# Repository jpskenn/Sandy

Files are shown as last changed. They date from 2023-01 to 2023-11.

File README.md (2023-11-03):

# Sandy（サンディ）

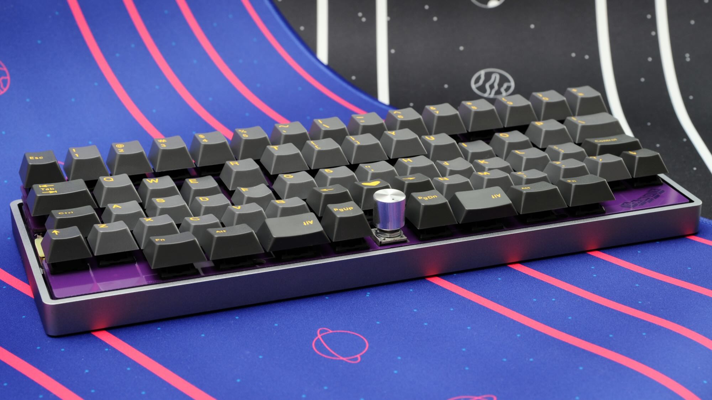
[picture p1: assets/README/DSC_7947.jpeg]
Sandy keyboard
  

Sandy is a keyboard with key height optimization.

Layered PCB will make height differences for each key.
This covers the lack of optimization to physical key layout that only adjust x-y direction in a plane.

---

Sandyは、スイッチの配置を立体的にして高さ方向への最適化を加えた、左右対称レイアウトの60%キーボードです。  

平面上のキーレイアウトだけでは最適化しきれない部分を、キーの位置に応じてスイッチを配置する高さを変えることで補っています。

名前の由来は、立体的、つまり3Dという意味を込めて…

``` text
3D → スリーディー → さんディー → サンディ → Sandy
```

という言葉遊びで、Sandy（サンディ）に決まりました。

---

## お知らせ

2023-11-04

キー割り当て書き換えツール[Remap](https://remap-keys.app)がQMKファームウェアのバージョン 0.22.2以降に対応したことに伴い、新しくビルドしたSandyのファームウェアを公開しました。  
参考：[Remap supports QMK Firmware 0.22.2 or higher](https://remap-keys.app/docs/support-qmk-022)

今すぐファームウェアを更新する必要はありませんが、ロータリーエンコーダへのキー割り当てを変更したい場合は、ファームウェアを更新するとよいでしょう。

Remapによる旧バージョンのサポート終了後は、ファームウェアを更新してください。

詳しくは、ビルドガイドの「Sandy関連ファイル」等をご覧ください。

## 特徴

- 左右対称のキーレイアウト  
  [Jones](https://github.com/jpskenn/Jones)と同様の、2行目と3行目にずれのない、左右対称な、シンメトリカル ロースタッガードのレイアウトです。
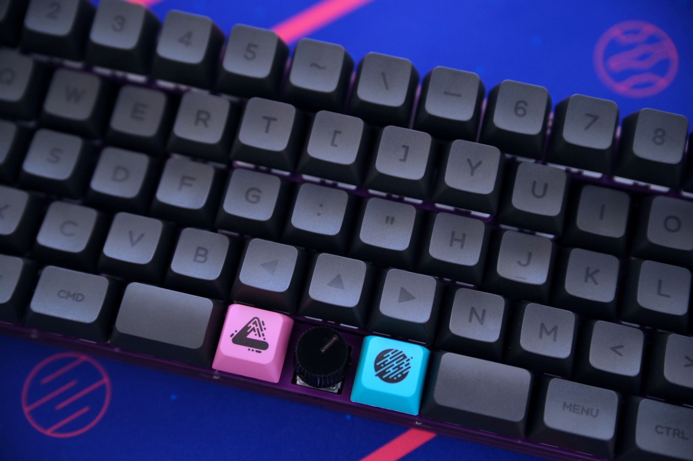
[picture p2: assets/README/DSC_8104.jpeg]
左右対称のキーレイアウト
  

- キースイッチを立体的に配置  
  3段階の高さで、キースイッチを立体的に配置しています。
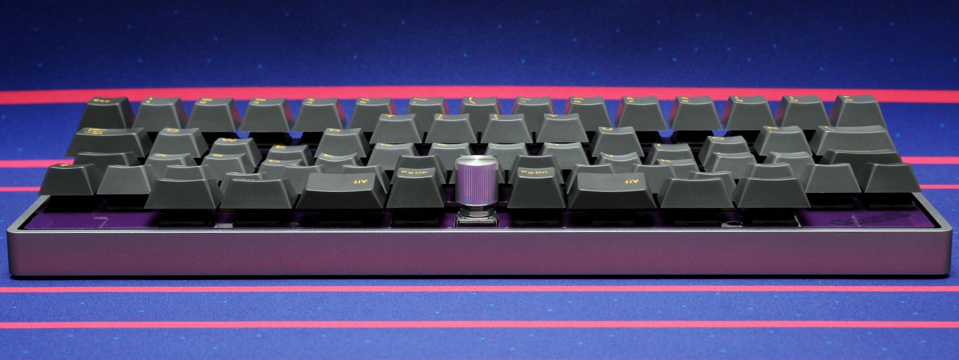
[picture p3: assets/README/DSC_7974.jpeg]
キースイッチの高さ
  

  平面上のキー配置だけでは最適化しきれない部分を、キーの位置に応じて高さを変え、立体的に配置することで補っています。  
  Jonesに比べて、ホームポジションから遠いキーへの打鍵しやすさが向上しています。

- 60%ケースと組み合わせられる  
  GH60型ケース互換のネジ穴を用意してあるので、市販のケースと組み合わせて使用できます。  
  ※詳しくはビルドガイドを参照

- [Remap](https://remap-keys.app)や[VIA](https://www.caniusevia.com)によるキー割り当て変更  
  プログラミング等の知識がなくても、ブラウザ上で簡単にキー割り当てを変更することができます。

- 外部EEPROM搭載  
  Remapでたくさんのレイヤーを使用できます。

- オプション機能  
  以下のオプション機能を使用できます。

  - ロータリーエンコーダ
  - インジケータLED
  - アンダーグローLED

## レイアウト

### バリエーション

キーのバリエーションを含むレイアウトは以下の通りです。  
Ctrl（左）とEnter（右）にはキーサイズのバリエーションがあり、最下行の中央にはロータリーエンコーダを配置できます。
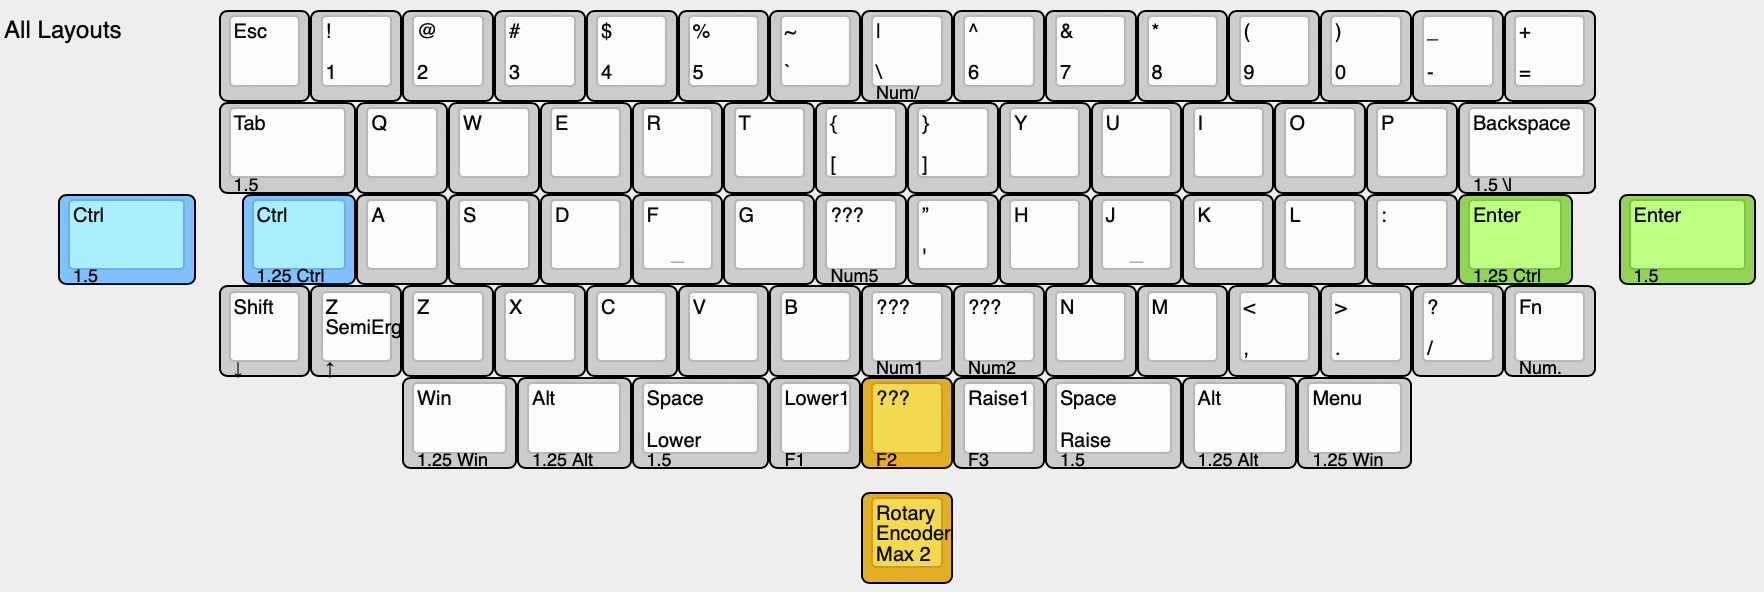
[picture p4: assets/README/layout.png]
Keyboard Layout Editor: Sandy (DN0030)
[  
Keyboard Layout Editor: Sandy (DN0030)](http://www.keyboard-layout-editor.com/#/gists/c907e866d8f82b82a22b455e622b7301)

### キーの高さ

キーの高さはLow（0mm）, Middle（3.6mm）, High（8.6mm）の3段階で、以下のように配置されます。  
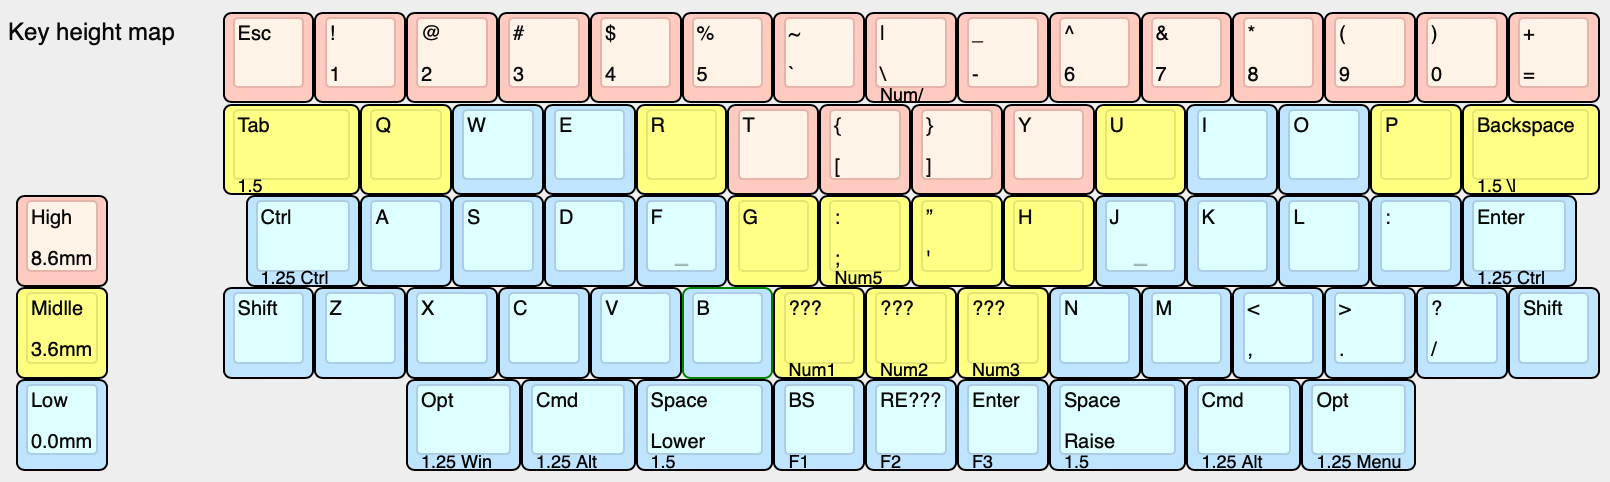
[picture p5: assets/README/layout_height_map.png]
キーの高さ


### 推奨キーマッピング

このレイアウトは、左右の手の運指を同じにするため、[SemiErgo Layout](https://github.com/mtei/SemiErgo_Layout)に準ずるキーマッピングで使用することを念頭に設計されています。  
つまり、一般的なロースタッガードレイアウトから、アルファ部の左手側Z行を左へ1キー、数字行の右手側を右側へ1キーずらしたものが、推奨キーマッピングとなります。

以下にSemiErgoを適用した推奨キーマッピングの例を示します。  
枠で囲った部分が、一般的なロースタッガードからの変更箇所です。
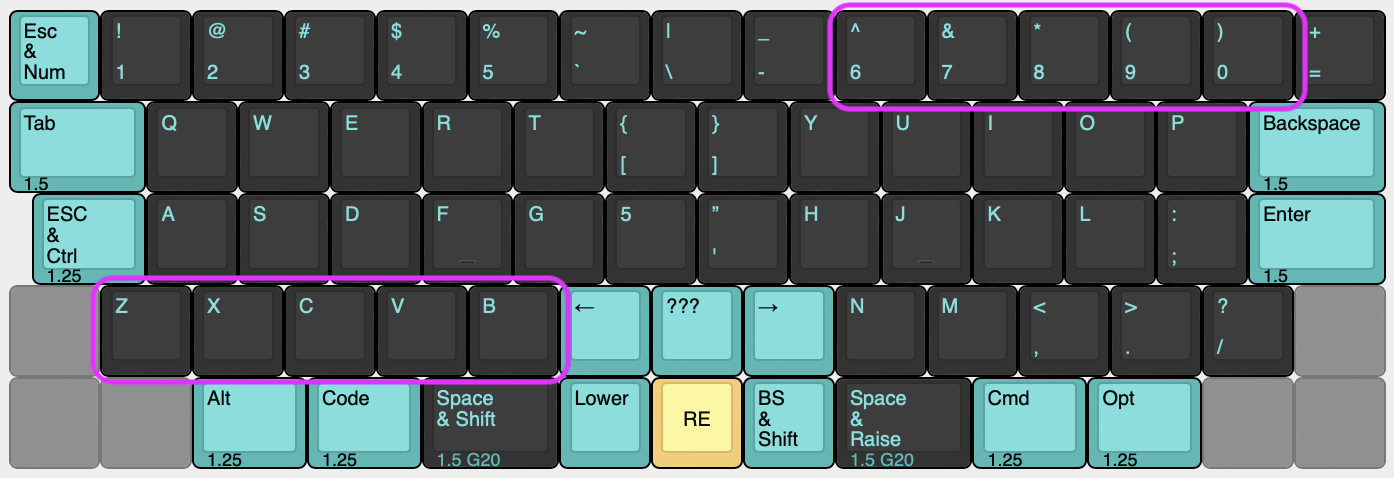
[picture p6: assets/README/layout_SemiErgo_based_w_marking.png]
SemiErgoを適用した推奨キーマッピング例

<small>💡ヒント：このキーマッピング例ではスペースキーをSandS（Space & Shift）にしているので、左右端のシフトキーを取り除いています。</small>

## ビルドガイド

- 最新版
  - [Sandy（DN0030）](/docs/BuildGuide_DN0030.md)

- 試作版
  - [Sandy（DN0020）](/docs/BuildGuide_DN0020.md)
  - [Sandy v.0.1](/docs/BuildGuide_v0_1.md)

## SNSタグ

[#Sandy_kbd](https://twitter.com/search?q=%23Sandy_kbd)

## ギャラリー

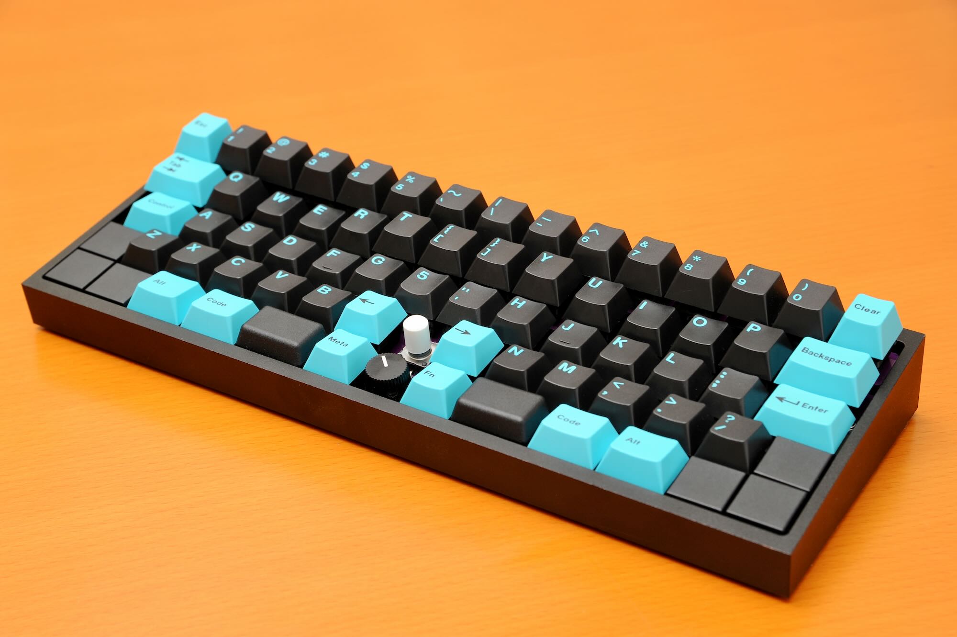
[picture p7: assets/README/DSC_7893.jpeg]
Sandy keyboard, v.0.1
  
v.0.1, Cherryプロファイルキーキャップ使用  

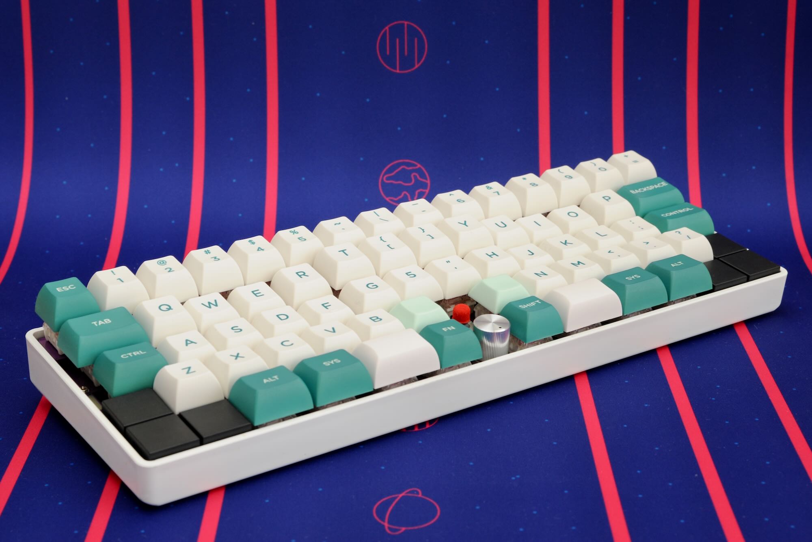
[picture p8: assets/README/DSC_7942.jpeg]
Sandy keyboard, 試作2号機
  
v.0.1, KATプロファイルキーキャップ使用

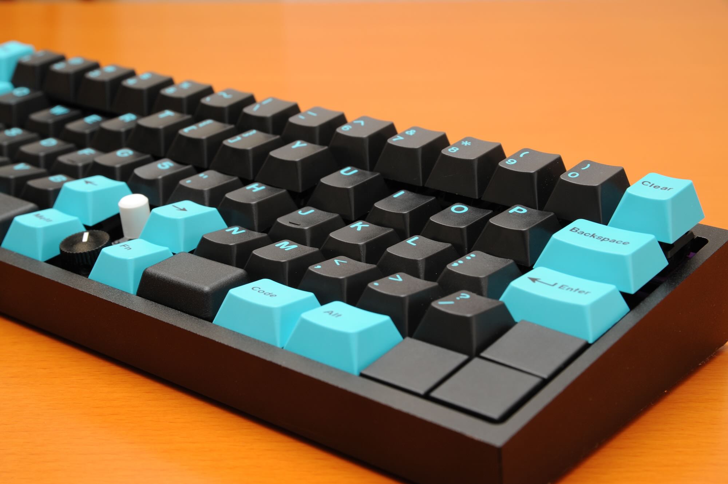
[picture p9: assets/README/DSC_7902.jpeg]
Sandy keyboard, キーの段差（Cherryプロファイル）
  
キーの段差（Cherryプロファイル）

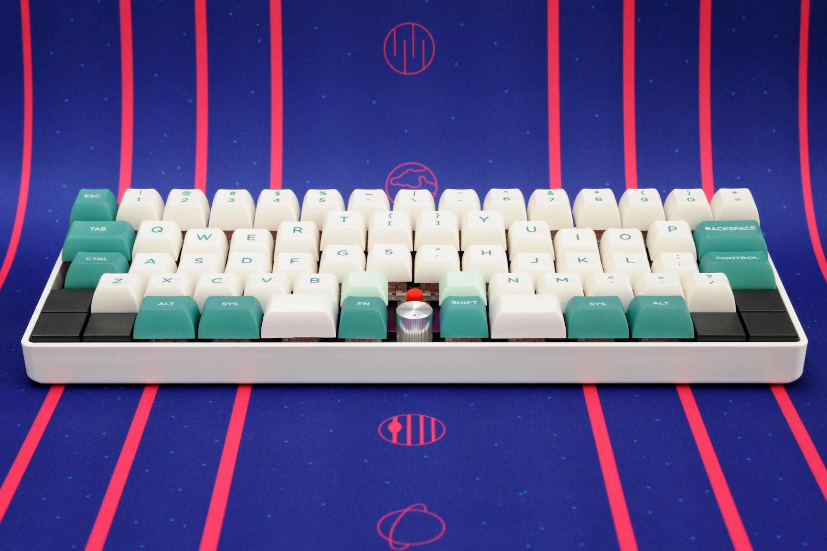
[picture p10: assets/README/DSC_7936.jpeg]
Sandy keyboard, キーの段差（KATプロファイル）
  
キーの段差（KATプロファイル）

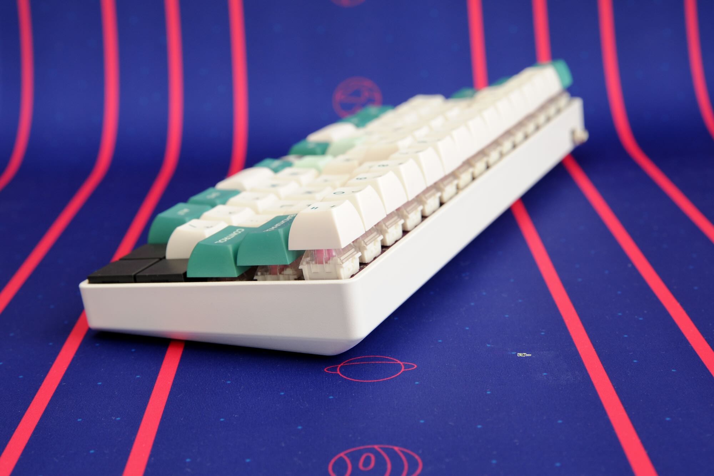
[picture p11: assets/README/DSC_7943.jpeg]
Sandy keyboard, キーの段差（横と後ろ
  
キーの段差（横）

## 残る課題

Sandyは複数基板を重ねるという手法で製作しているため、その技術的な制限や、製作工程を複雑にしすぎない配慮により、全てのスイッチをなめらかな高さ変化で配置できていません。  
そのため、高さ方向へ最適化しきれていない部分が残っています。  

## 参考事例

- [Genesis2.5](https://github.com/sekigon-gonnoc/Genesis2.5-doc)（[販売ページ](https://booth.pm/ja/items/1308005)  
  行ごとに高さと傾きを変えることができる自作キーボードキット。  

- [Thumbs Up!](https://www.thumbsup.shop)  
  カラムスタガをベースに親指や中央のキーを高くした設計の自作キーボードキット。

- [Kinesis Advantage series](https://kinesis-ergo.com/products/#keyboards)  
  ”エルゴノミクス”、”3Dキーボード”と言えばこれが思い浮かぶのはこれ。凹形状にキーが配置されている。

- [Microsoft Sculpt](https://www.microsoft.com/en/accessories/products/keyboards/sculpt-ergonomic-desktop)  
  ほんのり放射状に並んだキーと、中央部が高くなった形状。

- [Dactyl](https://github.com/adereth/dactyl-keyboard)  
  3Dプリンタで作る、スイッチを3D配置したキーボード。

- ["3D" キーキャップ](https://qiita.com/zk_phi/items/5680607118516413a0ba)  
  キーボードはそのままに、キーごとに高さを変えた3D形状のキーキャップ。MXスイッチ用。

- [Gravity Keycaps](https://note.com/yfuku_/n/n1fbba2e8f44c)  
  Choc用の3D形状キーキャップ。

## 開発経緯

### 元々の計画

当初（2021年1月ごろ）は、Chocスイッチを使用するキーボード、[Nora](https://github.com/jpskenn/Nora)の打鍵しやすさ向上を目的に、スイッチの配置を立体的に改修する計画でした。  
Choc用キーキャップには、行ごとに高さの異なるプロファイルのものが存在しません。すべてのキーが同じ形状になっているため、1行目の数字行や、ホームポジションから遠いキーへ指が届きにくくなります。  
その状況を改善するための改修計画でしたが、あまりモチベーションも上がらず、手をつけずに放置していました。  

### Sandy計画の始動

2022年12月の末ごろ、[SMKJのアドベントカレンダー](https://scrapbox.io/self-made-kbds-ja/アドベントカレンダー)を久しぶりに読み返しながら、様々なアイデアや取り組みについて思いをめぐらせていました。
そのとき、ふとした思いつきでJonesのキーキャップを部分的に背の高いものに入れ替えたところ、思いのほか打鍵しやすくなることに気がつきました。  

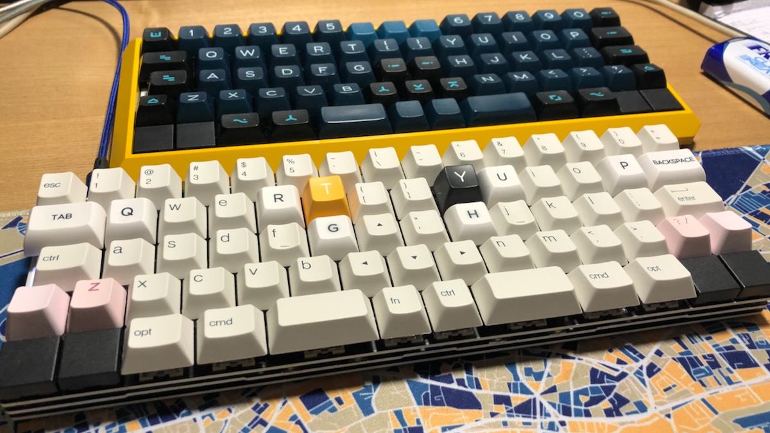
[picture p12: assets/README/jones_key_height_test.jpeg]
Jonesのキーキャップを部分的に背の高いものに入れ替えたテスト機
  
奥：通常のJones，手前：一部のキーを入れ替えたJones

Cherryプロファイルをベースにして、`T` `Y`は倍ほどの高さのSAプロファイル、`G`や`Q`などは少しだけ背の高いKATプロファイルに交換しました。  
この時点では`左右のシフト`などをOEMプロファイルでほんの少し高くしようとしていますが、後にボツとなります。

これをきっかけとして、MXスイッチを使用するキーボード、[Jones](https://github.com/jpskenn/Jones)を改修する計画として復活することになりました。  

### ロードテスト

先ほどのテスト機を使い部分的にキーキャップを交換してどのキーを最適化の対象にするかを調べたり、スチレンボードにスイッチをのせたモックアップを作成して最適な高さを探ったりしました。（`0+2+2`は、ベースの0mmに対して、1段目が2mm、2段目も2mmの段差を意味するメモ）

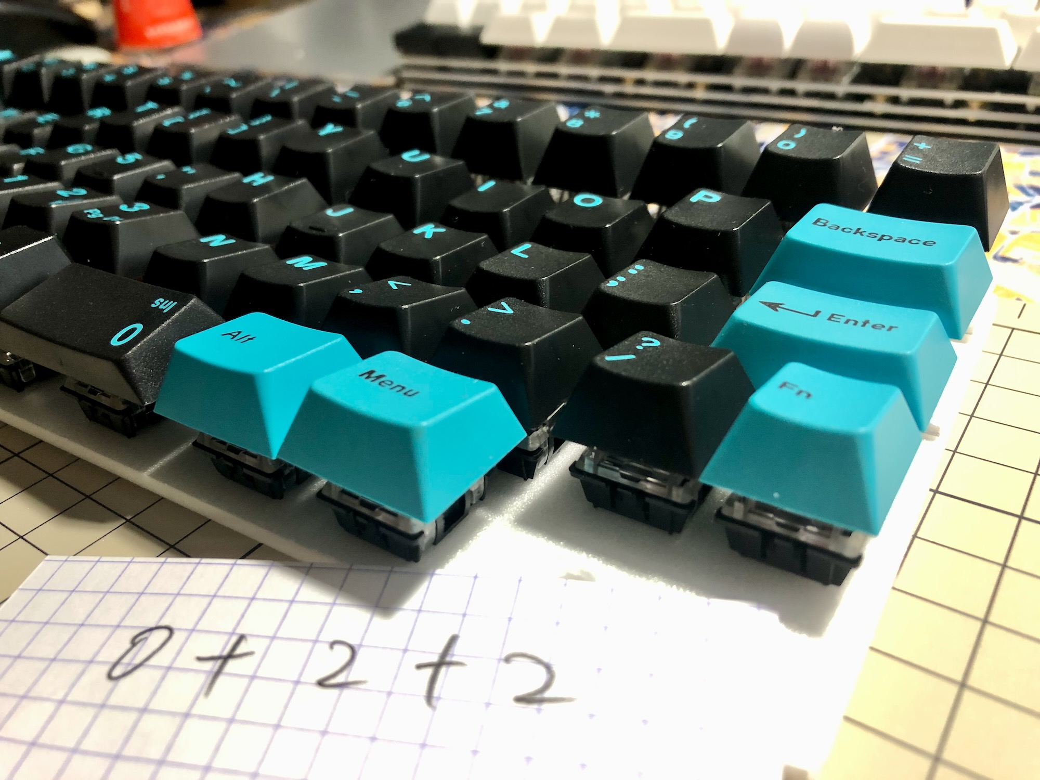
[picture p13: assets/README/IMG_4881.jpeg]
モックアップ
  

テスト機は、数字行をSAプロファイルへ、また、`T` `Y`をSAプロファイル1行目のキーに交換してさらに高くした最終形態になりました。  

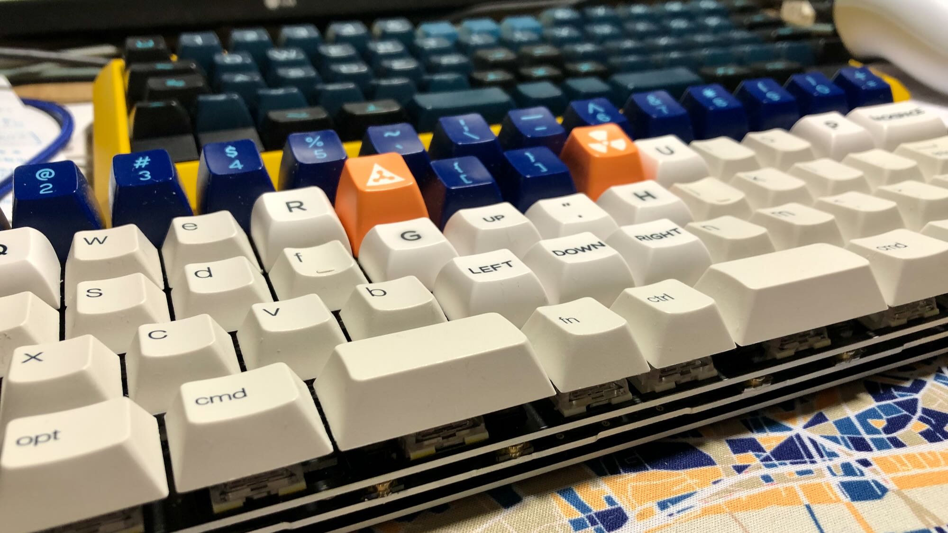
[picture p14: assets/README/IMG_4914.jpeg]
最終形のテスト機


この形態をロードテストとして3ヶ月ほど使用し、日常的な使用で問題ないことを確認した上で基板の製作に取り掛かりました。

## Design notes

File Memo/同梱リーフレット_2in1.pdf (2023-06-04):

このたびは、自作キーボードキット Sandy（サンディ）をご購入いただ

き、まことにありがとうございます。

まずは、すみやかにキット内容をご確認ください。

万一不足等がありましたら、下記の連絡先へお問い合わせください。

キット内容・組み立て方法
URL または QR コードから Sandy のプロジェクトペー

ジへアクセスし、ビルドガイドをごらんください。

https://github.com/jpskenn/Sandy

別途用意が必要な部品
- はんだ付け関連用品，ドライバーなど
- Cherry MX（互換）スイッチ 66 ～ 最大 67 個
- キーキャップ（MX 用） 同上
- USB ケーブル（Type-C） 1 本

連絡先
Twitter: @jpskenn

mail: kkeennnn+sandy@gmail.com

組み立てに関する質問なども、こちらでお受けいたします。

このたびは、自作キーボードキット Sandy（サンディ）をご購入いただ

き、まことにありがとうございます。

まずは、すみやかにキット内容をご確認ください。

万一不足等がありましたら、下記の連絡先へお問い合わせください。

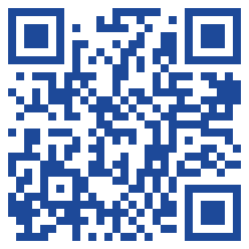
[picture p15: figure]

キット内容・組み立て方法
URL または QR コードから Sandy のプロジェクトペー

ジへアクセスし、ビルドガイドをごらんください。

https://github.com/jpskenn/Sandy

別途用意が必要な部品
- はんだ付け関連用品，ドライバーなど
- Cherry MX（互換）スイッチ 66 ～ 最大 67 個
- キーキャップ（MX 用） 同上
- USB ケーブル（Type-C） 1 本

連絡先
Twitter: @jpskenn

mail: kkeennnn+sandy@gmail.com

組み立てに関する質問なども、こちらでお受けいたします。

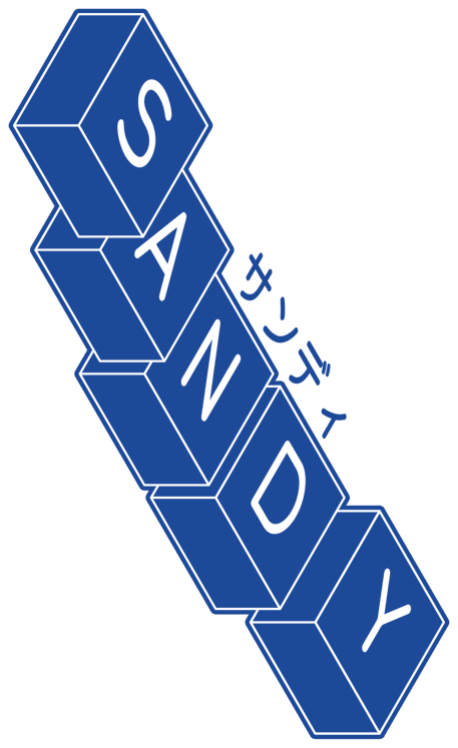
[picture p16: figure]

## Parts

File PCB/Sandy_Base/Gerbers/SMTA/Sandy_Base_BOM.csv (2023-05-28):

Comment | Designator | Footprint | LCSC
10uF | C1 | Capacitor_SMD:C_0805_2012Metric | C15850
22pF | C2,C3 | Capacitor_SMD:C_0805_2012Metric | C1804
0.1uF | C4,C5,C7,C8,C9 | Capacitor_SMD:C_0805_2012Metric | C49678
1uF | C6 | Capacitor_SMD:C_0805_2012Metric | C28323
D | D1,D2,D3,D4,D5,D6,D7,D8,D9,D10,D11,D12,D13,D14,D15,D16,D17,D18,D19,D20,D21,D22,D23,D24,D25,D26,D27,D28,D29,D30,D31,D32,D33,D34,D35,D36,D37,D38,D39 | locallib:D_SOD-123_Emphasized_Direction_Line_Reference_on_bottom | C81598
PRTR5V0U2X | D99 | Package_TO_SOT_SMD:SOT-143_Handsoldering | C78442
Conn_01x01 | EXT_C0,EXT_R0,EXT_C1,EXT_R1,EXT_C2,EXT_R2,EXT_C3,EXT_R3,EXT_C4,EXT_R4,EXT_C5,EXT_R5,EXT_C6,EXT_R6,EXT_C7,EXT_R7,EXT_R8,EXT_R9 | TestPoint:TestPoint_THTPad_D2.0mm_Drill1.0mm
500mA | F1 | Fuse:Fuse_1206_3216Metric_Pad1.42x1.75mm_HandSolder | C70076
MountingHole | H1,H2,H3,H4 | locallib:MountingHole_2.2mm_M2_No_Cu
MountingHole | H6,H7,H8,H9,H10,H11,H12,H13,H14,H40,H41 | locallib:MountingHole_2.2mm_M2_Pad_minimal
Conn_02x02_Top_Bottom | J1,J2,J3,J4,J5,J6 | locallib:JST_SH_SM04B-SRSS-TB_1x04-1MP_P1.00mm_Horizontal_wCable_housing_spare_pin | C371510
Conn_01x03 | J10 | Connector_PinHeader_2.54mm:PinHeader_1x03_P2.54mm_Vertical
USB_C_Receptacle_USB2.0 | J7 | Connector_USB:USB_C_Receptacle_HRO_TYPE-C-31-M-12 | C165948
Conn_02x03_Odd_Even | J8 | Connector_PinHeader_2.54mm:PinHeader_2x03_P2.54mm_Vertical
Conn_01x02 | J9 | Connector_PinHeader_2.54mm:PinHeader_1x02_P2.54mm_Vertical
SolderJumper_3_Open | JP1 | Jumper:SolderJumper-3_P1.3mm_Open_RoundedPad1.0x1.5mm
SK6812MINI-E | L1,L2,L3,L4,L5,L6,L7,L8,L9,L10,L11,L12,L13,L14,L15,L16,L17,L18 | locallib:YS-SK6812MINI-E_middle_hole_with_small_pad
Logo_Base | LOGO1 | Jones.local:Sandy_logo_w60_new
5.1k | R1,R2 | Resistor_SMD:R_0805_2012Metric | C27834
22 | R3,R4 | Resistor_SMD:R_0805_2012Metric | C17561
10k | R5,R6 | Resistor_SMD:R_0805_2012Metric | C17414
4.7k | R8,R9 | Resistor_SMD:R_0805_2012Metric | C17673
RotaryEncoder_Switch | RE_L1,RE_R1,RE_L2 | locallib:RotaryEncoder_Alps_EC11K-Switch_Vertical_H20mm_NPTH_MP_minimal
5.2x5.2mm | ResetSW1 | Button_Switch_SMD:SW_SPST_TL3342
SW_Push | SW_;1,SW_<1,SW_>1,SW_A1,SW_C1,SW_D1,SW_DOWN1,SW_E1,SW_F1,SW_I1,SW_J1,SW_K1,SW_L1,SW_M1,SW_N1,SW_O1,SW_S1,SW_UP1,SW_V1,SW_W1,SW_X1,SW_Z1,SW_Fn1u1,SW_LSFT1u1,SW_CenterL1u2,SW_CenterR1u2,SW_LSFT1u2,SW_L2-1u1 | MX_Alps_Hybrid:MXOnly-1U-Hotswap-guide
SW_Push | SW_RIGHT1,SW_CAPS1u1,SW_CenterC1u1 | MX_Alps_Hybrid:MXOnly-1U-Hotswap-on-RE-guide
SW_Push | SW_CTL1.25u1,SW_ENT1.25u1,SW_LALT1.25u1,SW_LWIN1.25u1,SW_RALT1.25u1,SW_ROPT1.25u1 | MX_Alps_Hybrid:MXOnly-1.25U-Hotswap-guide
SW_Push | SW_CTL1.5u1,SW_ENT1.5u1,SW_LSPC1.5u1,SW_RSPC1.5u1 | MX_Alps_Hybrid:MXOnly-1.5U-Hotswap-guide
ATmega32U4-MU | U1 | Package_DFN_QFN:QFN-44-1EP_7x7mm_P0.5mm_EP5.2x5.2mm | C112161
24LC64 | U2 | Package_SO:SO-8_3.9x4.9mm_P1.27mm | C79988
16MHz | Y1 | Crystal:Crystal_SMD_3225-4Pin_3.2x2.5mm_HandSoldering | C13738

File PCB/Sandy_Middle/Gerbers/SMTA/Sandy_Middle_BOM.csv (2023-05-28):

Comment | Designator | Footprint | LCSC
D | D1,D2,D3,D4,D5,D6,D7,D8,D9,D10,D11,D12,D13 | locallib:D_SOD-123_Emphasized_Direction_Line | C81598
Conn_01x01 | EXT_MC0,EXT_MR1,EXT_MC2,EXT_MR2,EXT_MC3,EXT_MR3,EXT_MC4,EXT_MC6,EXT_MR6,EXT_MC7,EXT_MR7,EXT_MR8 | TestPoint:TestPoint_THTPad_D2.0mm_Drill1.0mm
MountingHole | H1,H2,H3,H4,H5,H6,H7,H8,H9,H10,H11,H12,H13,H14,H15,H16,H17,H18,H19 | locallib:MountingHole_2.2mm_M2_Pad_minimal
Conn_02x02_Top_Bottom | J1,J2,J3 | locallib:JST_SH_SM04B-SRSS-TB_1x04-1MP_P1.00mm_Horizontal_wCable_housing_spare_pin | C160404
SW_Push | SW_'1,SW_;1,SW_G1,SW_H1,SW_P1,SW_Q1,SW_R1,SW_U1,SW_R4CenterC1,SW_R4CenterL1,SW_R4CenterR1 | MX_Alps_Hybrid:MXOnly-1U-Hotswap-guide
SW_Push | SW_BS1.5u1,SW_TAB1.5u1 | MX_Alps_Hybrid:MXOnly-1.5U-Hotswap-guide

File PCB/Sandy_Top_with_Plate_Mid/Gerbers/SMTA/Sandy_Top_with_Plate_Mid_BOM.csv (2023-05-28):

Comment | Designator | Footprint | LCSC
D | D1,D2,D3,D4,D5,D6,D7,D8,D9,D10,D11,D12,D13,D14,D15,D16,D17,D18,D19 | locallib:D_SOD-123_Emphasized_Direction_Line | C81598
Conn_01x01 | EXT_TC0,EXT_TR0,EXT_TC1,EXT_TR1,EXT_TC2,EXT_TC3,EXT_TC4,EXT_TC5,EXT_TR5,EXT_TC6,EXT_TR6,EXT_TC7 | TestPoint:TestPoint_THTPad_D2.0mm_Drill1.0mm
MountingHole | H1,H2,H3,H4,H5,H6,H7,H8 | locallib:MountingHole_2.2mm_M2_Pad_minimal
Conn_02x02_Top_Bottom | J1,J2,J3 | locallib:JST_SH_SM04B-SRSS-TB_1x04-1MP_P1.00mm_Horizontal_wCable_housing_spare_pin | C371510
SW_Push | SW_-1,SW_1,SW_=1,SW_ESC1,SW_T1,SW_Y1,SW_[1,SW_\1,SW_]1,SW_`1,SW_2,SW_3,SW_4,SW_7,SW_9,SW_10 | MX_Alps_Hybrid:MXOnly-1U-Hotswap-guide
SW_Push | SW_5 | MX_Alps_Hybrid:MXOnly-1U-Hotswap-screw-hole-side2-guide
SW_Push | SW_6 | MX_Alps_Hybrid:MXOnly-1U-Hotswap-screw-hole-side1-guide
SW_Push | SW_8 | MX_Alps_Hybrid:MXOnly-1U-Hotswap-screw-hole-side3-guide

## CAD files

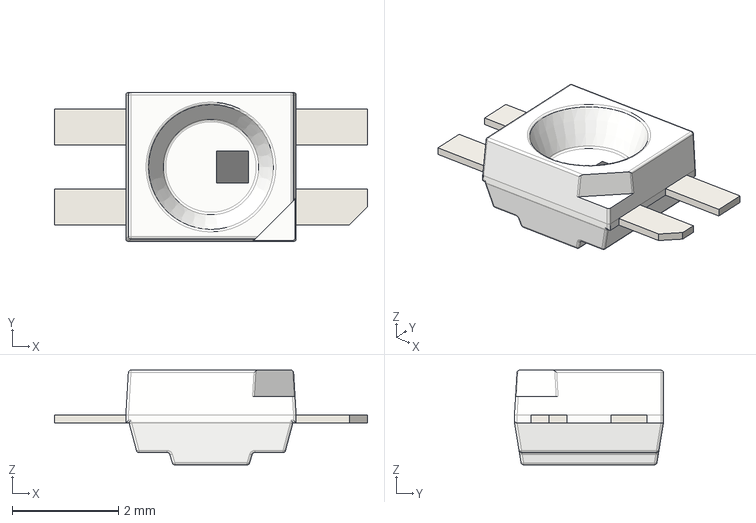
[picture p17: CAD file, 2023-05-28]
PCB/Sandy_Base/lib_LED/LED_SK6812MINI-E.step
5.88 x 2.80 x 1.78 mm

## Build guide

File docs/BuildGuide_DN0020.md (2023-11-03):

# Sandy（DN0020）ビルドガイド

このドキュメントは、Sandy（DN0020）を組み立てるためのビルドガイドです。  
Sandyのコンセプトや特徴、ビルド例などについては、こちらの[README](/README.md)をご覧ください。

ビルドガイド全体に目を通して作業手順を把握しておくとミスの防止につながりますので、ぜひ、一度お読みになってから組み立て作業を始めてください。

作業手順をしっかりと確認しながら組み立てたい方は、

<details>
<summary>《《《 詳しい説明 》》》</summary>

ここに追加の説明を表示します。
</details>

と書かれたところをクリックすると、追加の説明が表示されます。

---

## 目次

<!-- @import "[TOC]" {cmd="toc" depthFrom=2 depthTo=2 orderedList=false} -->

<!-- code_chunk_output -->

- [目次](#目次)
- [注意事項](#注意事項)
- [部品リスト](#部品リスト)
- [組み立てに使用する工具](#組み立てに使用する工具)
- [組み立て手順](#組み立て手順)
- [参考資料](#参考資料)
- [サービスマニュアル](#サービスマニュアル)

<!-- /code_chunk_output -->

---

## 注意事項

- 試作版

  Sandy（DN0020）は試作版です。  

- 組み立て難易度：高

  SHコネクタのはんだ付けがそこそこ難しいです。  
  テスターで確認しながら作業を進めると、失敗を防ぎ、手戻りなく進められるでしょう。  
  個人的な所感としては、はんだ付けを数回やった程度の方にはかなりチャレンジングな作業になると思います。  
  これを機にテスターを購入してはんだ付けの腕前を上げる気持ちで挑むか、コネクタ取り付けサービスの利用をご検討ください。

- スイッチの取り付け

  一部のスイッチを上下反対向きに取り付けます。

- ビルドガイド

  一部の写真はDN0030のものを掲載しています。  
  パーツ位置や表記が異なるだけで、基本的には同じです。

- ファームウェアについて

  出荷時に書き込み済みのファームウェアは、QMKバージョン 0.18.17です。  
  [Remap for QMK Firmware 0.18.17 or lower](https://qmk018.remap-keys.app)で、キーの割り当てを変更することができます。  
  ロータリーエンコーダへのキー割り当てをおこなうには、Remapで定義ファイル`sandy_v01_via.json`をインポートしてください。

  QMKバージョン 0.22.14のファームウェアに書き換えると、[Remap](https://remap-keys.app/)で、ロータリーエンコーダを含むキーの割り当てを変更できるようになります。

## 部品リスト

このキットを組み立てるためには、[キット内容](#キット内容)に加え、[別途用意が必要な部品](#別途用意が必要な部品)が必要です。  
好みに合わせて必要な数をお買い求めください。

[オプション部品](#オプション部品)は、使いたい機能に応じて用意してください。  

### キット内容

| 部品名 | 個数 | 備考 |
| :-- | --: | :-- |
| ご案内リーフレット | 1 | |
| 基板Base | 1 | Baseのみ部品実装済み |
| 基板Mid | 1 | |
| 基板Top | 1 | Mid用スイッチプレートを兼ねる |
| Base用スイッチプレート | 1 | 捨て基板（捨て板）付き |
| Top用スイッチプレート | 1 ||
| ボトムプレート | 1 ||
| ダイオード<br>表面実装（SMD）タイプ, 1N4148W<br>[高速スイッチング・ダイオード　１Ｎ４１４８Ｗ](https://akizukidenshi.com/catalog/g/gI-07084/) | 34 | 予備2個含む |
| SHコネクタ<br>JST SH ベース サイド型 4pin 面実装<br>[HR(Joint Tech Elec) A1001WR-S-04P](https://www.lcsc.com/product-detail/_HR-Joint-Tech-Elec-_C371510.html) | 12 | 取り付けサービス利用時は、各基板に取り付け済み |
| JST SH 4pinケーブル<br>（いわゆるQwiicケーブル）<br>[PRT-17260](https://www.digikey.jp/ja/products/detail/sparkfun-electronics/PRT-17260/13629028) | 6 | ケーブルの取り回しを考え、長さ5-10cm程度を推奨。<br>国内での販売例：<br>- [Qwiicケーブル（Qwiic -Qwiic）50 mm](https://www.switch-science.com/products/6896?_pos=1&_sid=bc641ada5&_ss=r)<br>- [SparkFun　PRT-17260 Qwiicケーブル (50mm)](https://www.sengoku.co.jp/mod/sgk_cart/detail.php?code=EEHD-5ZMM) |
| スペーサー<br>両メネジ M2 3mm<br>[ヒロスギ ARB-2003E](https://hirosugi.co.jp/products/B/ARB-E.html#bx3) | 16 | 丸型、六角いずれも使用可能 |
| 六角ナット<br>M2 2種 高さ1.6mm<br>[ウィルコ FNT-02N-2](https://wilco.jp/products/F/FNT-N-2.html) | 22 | |
| ワッシャー<br>内径2.3mm 外径4.3mm 厚さ0.4mm<br>[ウィルコ FW-0204-04N](https://wilco.jp/products/F/FW-N.html#page3) | 19 | |
| ネジ<br>M2 3mm<br>[ウィルコ F-0230N-03](https://wilco.jp/products/F/F-N-02.html#page3) | 32 | |
| ネジ<br>M2 7mm<br>[ウィルコ F-0270N-03](https://wilco.jp/products/F/F-N-02.html#page3) | 11 | |
| LED<br>SK6812MINI<br>[マイコン内蔵ＲＧＢＬＥＤ　ＳＫ６８１２ＭＩＮＩ](https://akizukidenshi.com/catalog/g/gI-15477/) | 4 | |
| スイッチ用ソケット（MX）<br>[MXスイッチ用 Kailh PCBソケット](https://talpkeyboard.net/items/5e02c5405b120c792616bcf9) | 72 | 予備1個含む |

※出荷時期によって、機能的に同等なものへ変更することがあります。

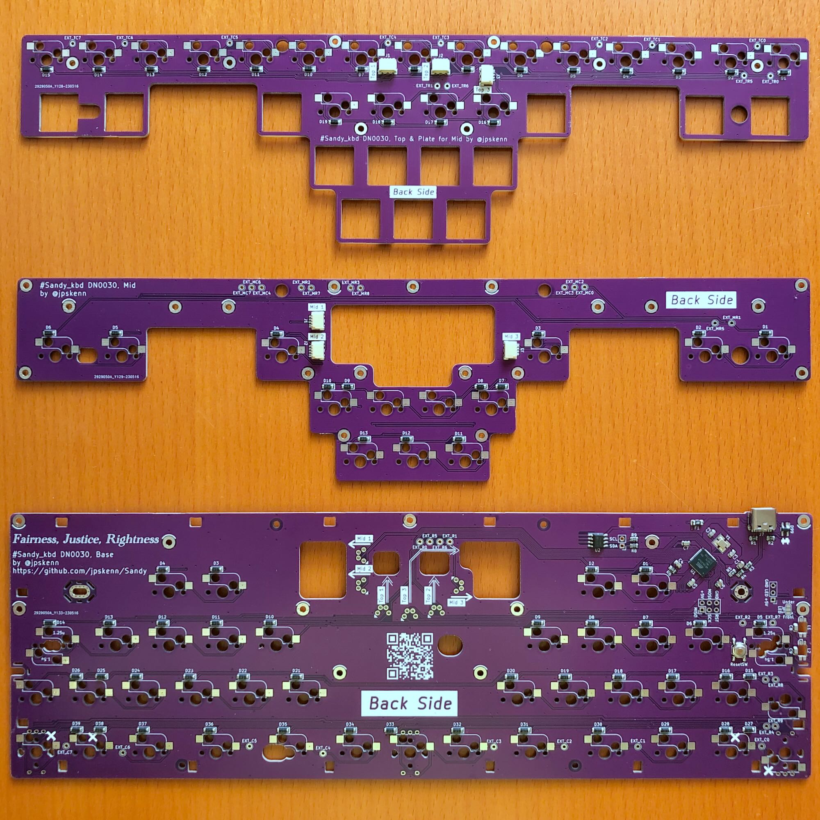
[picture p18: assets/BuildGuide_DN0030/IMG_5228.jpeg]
  
基板3枚（※写真はDN0030）  
上から順に、基板Top、基板Mid、基板Base。

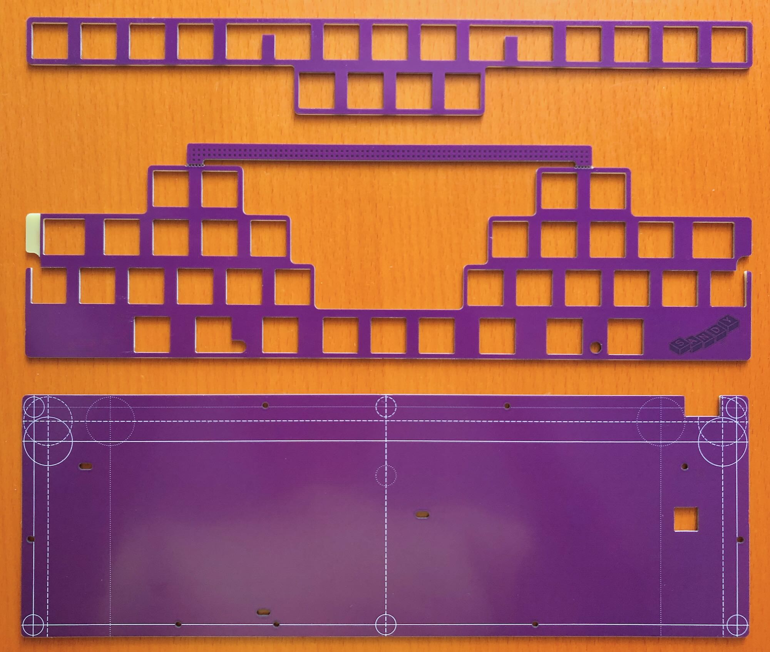
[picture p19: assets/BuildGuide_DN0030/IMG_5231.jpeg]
  
プレート類（※写真はDN0030）  
上から順に、Top用スイッチプレート、Base用スイッチプレート、ボトムプレート。

### 別途用意が必要な部品

| 部品名 | 個数 | 備考 |
| :-- | :-- | :-- |
| Cherry MX（互換）スイッチ | 69 〜 71 | 組み立てるレイアウトにより使用数が変動します。 |
| キーキャップ<br>Cherry MX（互換）スイッチ用 | 必要数 | 一般的な英語104キーキャップセットに、スペースキー用として1.5uのキー2個を追加すると全て埋めることができます。<br>1.5uのALTキーなどが含まれるセットを使用したり、文字の入っていないブランクのDSAキーキャップなどを追加すると良いでしょう。<br>参考： [Sandy（DN0020）のレイアウト](http://www.keyboard-layout-editor.com/#/gists/19f42cd466b4f3b269f38e3bdd6bf532) |
| USBケーブル （Type-C） | 1 | |

### オプション部品

| 部品名 | 個数 | 備考 |
| :-- | :-- | :-- |
| ロータリーエンコーダ<br>ALPS EC11, EC12または同等品 | 最大 2 | プッシュスイッチ付きにも対応 |
| ロータリーエンコーダ用ノブ（つまみ） | 必要数 | |
| GH60互換ケース | 1 | ケースへの基板の固定には中央と中央下のネジを使用せず、左右2本ずつ合計4本のネジだけで取り付けます。<br>ケース内部の構造によっては取り付けに加工が必要になったり、取り付けできないことがるかもしれません。<br>以下のケースへ取り付けできることを確認済みです。<br>- KBDfans TOFU 60% ALUMINUM CASE<br>- KBDfans 5° FIVE DEGREE 60% ALUMINUM CASE<br>- KBDfans 60% ALUMINUM LOW PROFILE CASE<br>- 60% プラスチックケース（簡単な加工が必要） |

## 組み立てに使用する工具

- 必要な工具

  - 先の細いプラスドライバー（+0）

    M2ネジに対応するもの。

  - はんだ付け関連用品

  - ピンセット

  - マジックペン

    基板の色に近いもの。  
    [プロッキー<細字丸芯+太字角芯>](https://www.mpuni.co.jp/products/felt_tip_pens/water_based/sign_pen/prockey/pm_150tr.html)の角芯側が塗りやすい。

- あると便利な工具

  - テスター

    はんだ付けの難易度が高くミスが起こりがちなので、確認作業や、何か不具合があった場合の原因調査で活躍します。  
    **SHコネクタを取り付ける場合は、ほぼ必須。**

  - フラックスやハンダ吸い取り線

    はんだ付けの修正や、部品の取り外しなどがしやすくなります。

  - M2ナット対応のレンチ

    ナットを締めるのが格段に楽になります。  
    [タミヤ SP.38 工具セット](https://www.tamiya.com/japan/products/50038/index.html)の十字レンチがM2ナットに対応しています。

  - ニッパーやカッターなど

    使用するケースによっては、スイッチの足やケース内のリブをカットする必要があるかもしれません。

  - やすり

    Base用スイッチプレートの捨て基板を切り離したあと、側面を滑らかにします。

## 組み立て手順

手順に沿って、順番に組み立てます。

- `（こだわり作業）`の手順は、完成時の質感を重視した内容であり、不要であれば作業をとばしてもかまいせん。

- `（該当者のみ）`の手順は、条件に該当する場合のみ作業します。

基板の`おもて側`と`うら側`を間違えないよう、注意して作業します。  
うら側には`Back Side`の表記があります。
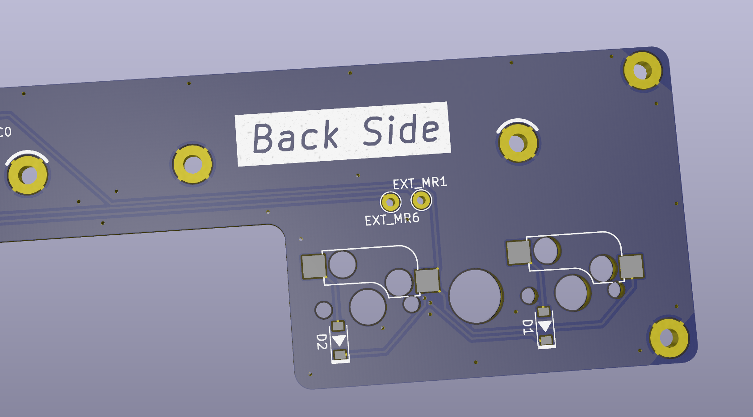
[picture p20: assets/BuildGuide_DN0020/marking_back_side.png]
Back Sideの印


### 組み立て前の確認

発送前に基板Baseの動作確認をおこなっていますが、輸送時の破損なども考えられるため、念のため確認を行います。

確認結果に問題がある場合は、リーフレットに記載の連絡先へ相談してください。

1. 基板Baseを、USBケーブルでPCやMacに接続する

1. PCやMacで認識されていることを確認する

    - Windows  
      設定 → キーボードに”Sandy”が表示されていること

    - Mac  
      システムレポート → USBに”Sandy”が表示されていること

1. [Remap](https://remap-keys.app/)を開く

    💡ヒント：出荷時のファームウェアを書き換えていない場合は、[Remap for QMK Firmware 0.18.17 or lower](https://qmk018.remap-keys.app)を開きます。

1. "START REMAP FOR YOUR KEYBOARD"をクリックし、キーボード”Sandy”を接続する

1. "Layout Option"で以下のようにレイアウトを指定する

    - Left Shift: 1u + 1u
    - Bottom Keys: 5 keys
    - Rotary Encoder, Left: Off
    - Rotary Encoder, Right: Off
    - 5-way navigation: Off

1. Remapの”Test Matrix Mode”を開く

1. キースイッチの反応を確認する

    基板Baseうら側のスイッチソケット取り付け用パッド（銀色の四角い端子部分）をピンセットなどでショートさせ、画面上のキーの色が青に変わることを確認します。  

    以下のように色が変われば正常です。  
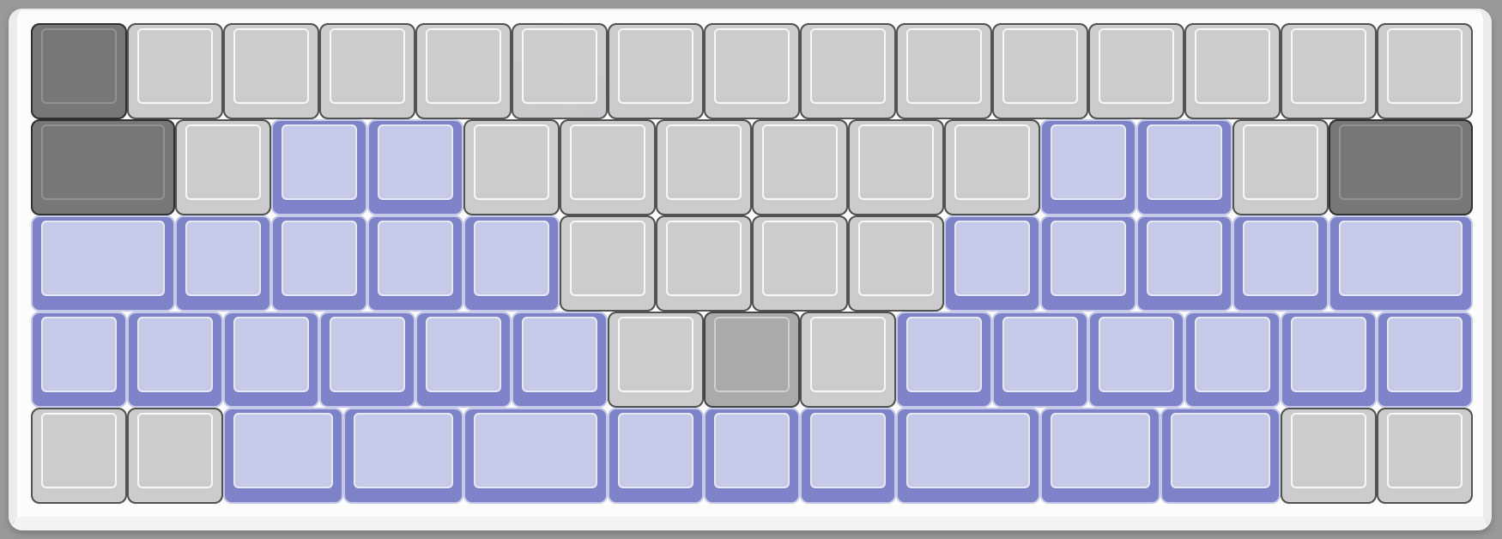
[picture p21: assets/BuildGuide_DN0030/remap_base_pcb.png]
基板Base確認結果
    

### 組み立てるレイアウトを決める

以下のポイントを念頭に、組み立てるレイアウトを決めます。

- キーのサイズ  

  - 左Control：1.25u / 1.5u

  - Enter：1.25u / 1.5u

- ロータリーエンコーダの有無と場所

  最大2個まで取り付けできます。

  - 左側（RE_L1）と中央（RE_L2）のうち、いずれかひとつ

  - 右側（RE_R1）

参考：[Sandy（DN0020）のレイアウト](http://www.keyboard-layout-editor.com/#/gists/19f42cd466b4f3b269f38e3bdd6bf532)

### 基板Topの準備

1. （こだわり作業）基板側面をマジックで塗る

1. SHコネクタを取り付ける（3個）

    うら側（`J1`, `J2`, `J3`）

    基板に描かれた枠に合わせてはんだ付けします。  
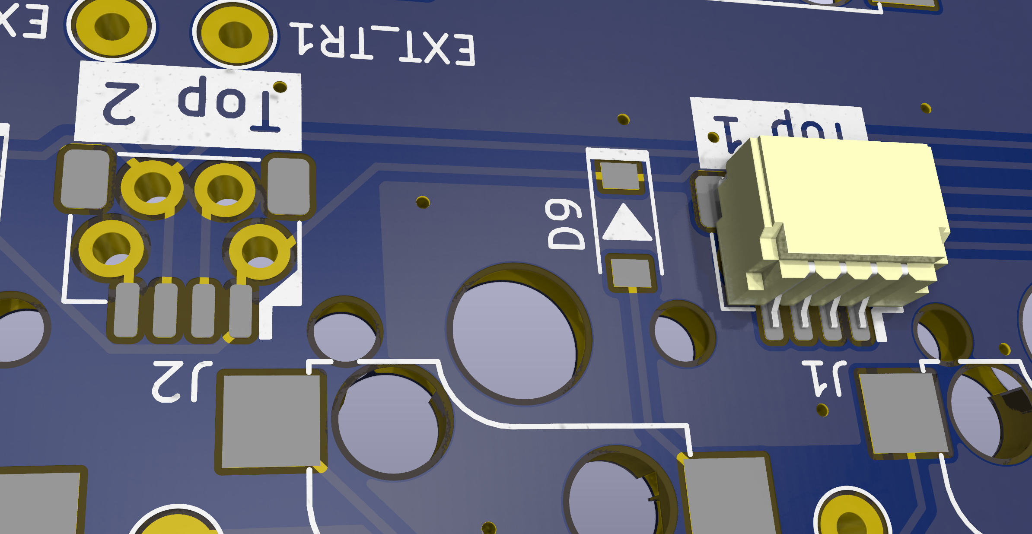
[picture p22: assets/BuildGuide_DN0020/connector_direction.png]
SHコネクタ取り付け方向
    

    大きなパッドの片方だけに予備はんだしておき、コネクタの位置を合わせて仮固定します。  
    コネクタが正しい位置に仮固定されたら、残りのパッドと4本のピンをはんだ付けします。  

    隣同士の端子がはんだで繋がっていないか確認し、可能ならコネクタうら側のスルーホールが隣同士で同通しないことをテスターで確認しておきます。

1. ダイオードを取り付ける（19個）

    うら側（`D1` ... `D19`）

    基板とダイオードに描かれた印の向きを合わせて、はんだ付けします。  
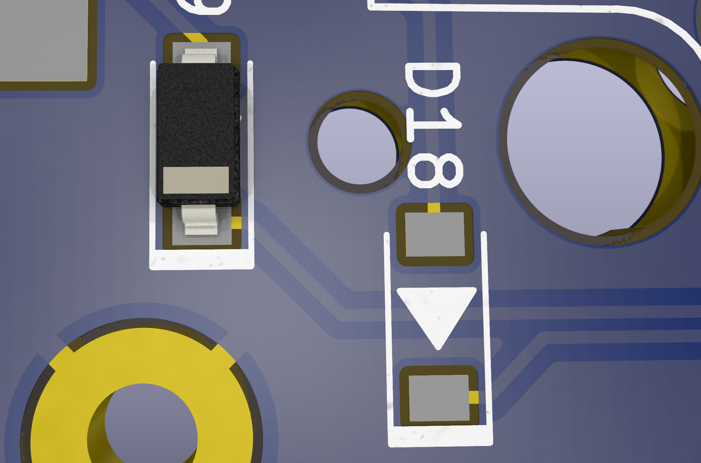
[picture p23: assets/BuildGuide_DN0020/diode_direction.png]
ダイオード取り付け方向
    

1. スイッチ用ソケットを取り付ける（19個）

    うら側。

    基板に描かれた枠に合わせてソケットを取り付け、はんだ付けします。  
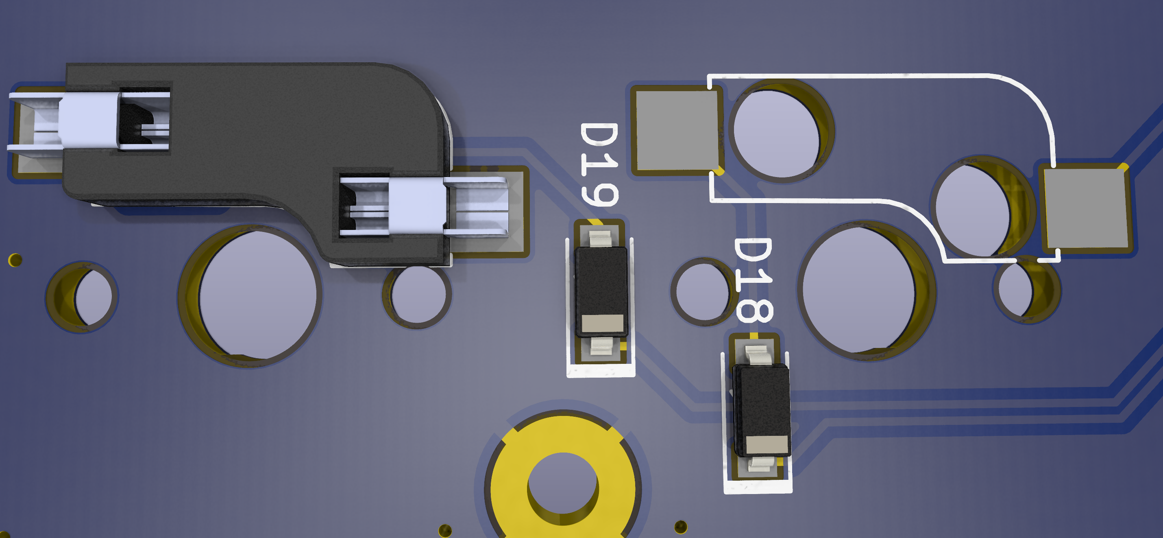
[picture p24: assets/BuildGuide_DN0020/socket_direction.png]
ソケット取り付け方向
    

1. SHコネクタへ、ケーブルを差し込む（3本）

    コネクタがもげないよう、コネクタを上から押さえたり後ろを支えたりしながらケーブルを差し込むと安心です。

### 基板Midの準備

1. （こだわり作業）基板側面をマジックで塗る

1. SHコネクタを取り付ける（3個）

    うら側（`J1`, `J2`, `J3`）

1. ダイオードを取り付ける（13個）

    うら側（`D1` ... `D13`）

1. スイッチソケットを取り付ける（13個）

    うら側。

1. 基板Midのおもて側から、ワッシャーを挟んだナットを7mmネジでとめる（11箇所）

    ナットを締め込みすぎないよう注意します。  
    グイグイ・グググッと締め込むのではなく、ナットを回して最初にクッと止まったところでやめます。

    💡ヒント：ネジ穴に印がついている側から、ネジを差し込みます。  
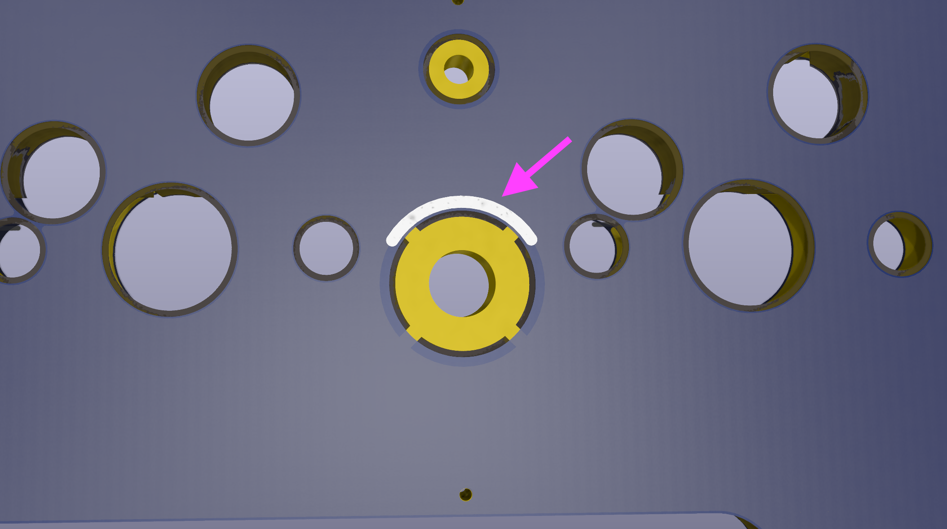
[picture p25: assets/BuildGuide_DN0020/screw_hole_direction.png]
ネジ穴の印
      

    ```text
    7mmネジ  
    ↓  
    －－ 基板Mid －－  
    ↓  
    ワッシャー  
    ↓  
    ナット
    ```

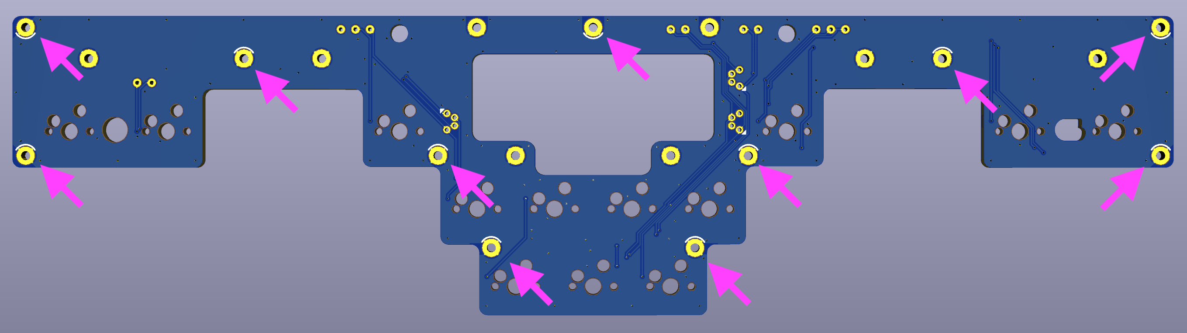
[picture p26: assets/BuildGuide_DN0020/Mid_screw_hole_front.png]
基板Midおもて側ネジ止め箇所
    

1. 基板Midのうら側から、ワッシャーを挟んだスペーサーを3mmネジでとめる（8箇所）

      ```text
      スペーサー  
      ↑
      ワッシャー  
      ↑
      －－ 基板Mid －－  
      ↑
      3mmネジ  
      ```

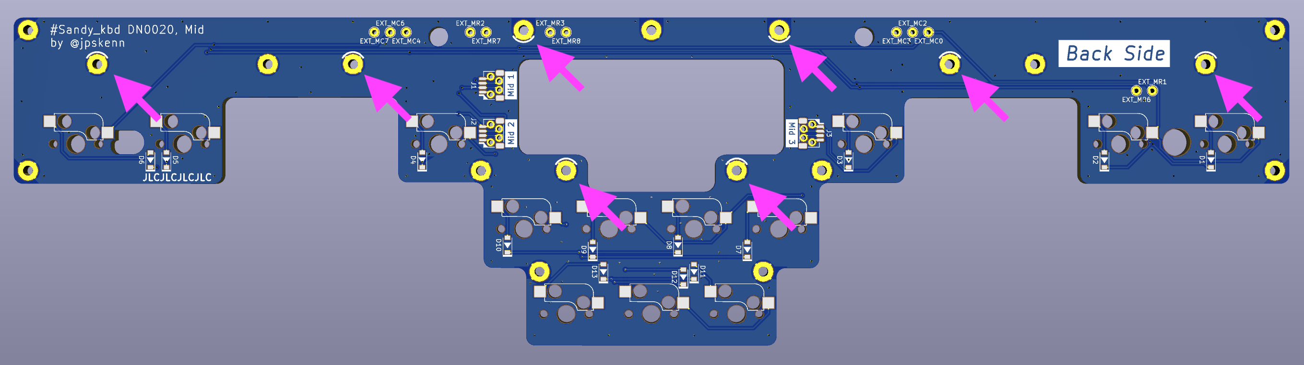
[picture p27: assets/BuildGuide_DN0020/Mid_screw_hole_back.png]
基板Midうら側ネジ止め箇所
    

1. 基板Midのコネクタへ、ケーブルを差し込む（3本）

### 基板Baseの準備

1. （こだわり作業）基板側面をマジックで塗る

1. スイッチソケットを取り付ける（39個）

    うら側。  
    組み立てるレイアウトにより、一部の取り付け位置が変わります。  
    ロータリーエンコーダを取り付ける箇所には、ソケットは取り付けません。

1. （該当者のみ）インジケータLEDを取り付ける

    条件：インジケータLEDを使用する場合

    おもて側（`LED1`, `LED2`, `LED3`, `LED4`）

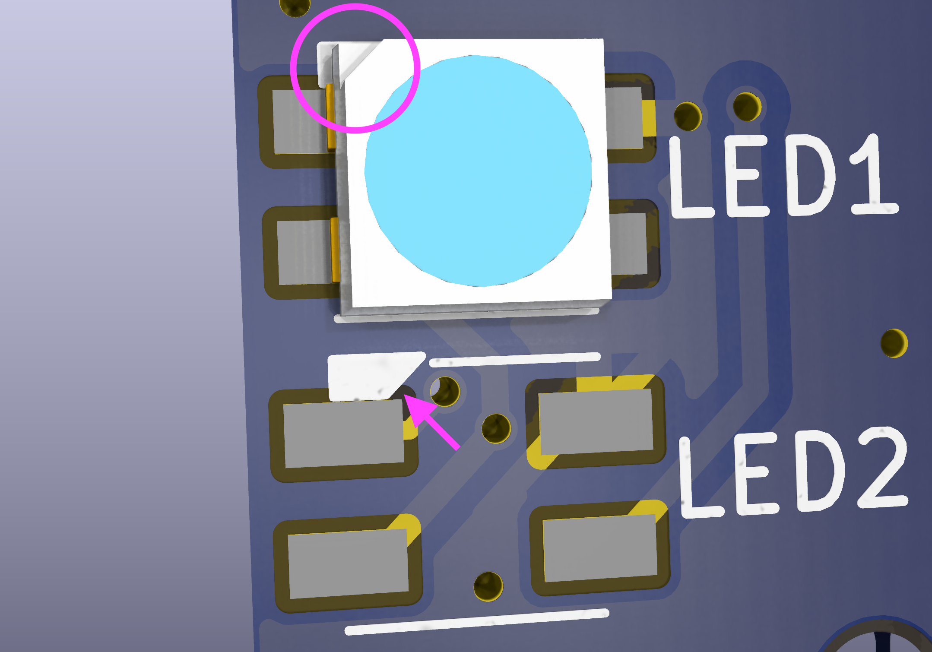
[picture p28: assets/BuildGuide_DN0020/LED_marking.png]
LED取り付けマーキング
      

    270度以下の小手先温度ではんだ付けします。

    基板に描かれた印に、LEDの切り欠き部分を合わせます。  
    4箇所のうち1箇所のパッドだけに予備はんだして、LEDの位置を合わせて仮固定してから、残りのパッドをはんだ付けします。

1. SHコネクタを取り付ける（6個）

    おもて側（`J1`, `J2`, `J3`, `J4`, `J5`, `J6`）

1. （該当者のみ）ロータリーエンコーダを取り付ける

    条件：ロータリーエンコーダを使用する場合

    最大2個まで取り付けできます。

      - 左側（RE_L1）と中央（RE_L2）のうち、いずれかひとつ

      - 右側（RE_R1）

    おもて側からはめ込んで、うら側からはんだ付けします。  

### Top用スイッチプレートの準備

1. （こだわり作業）基板側面をマジックで塗る

### Base用スイッチプレートの準備

1. 捨て基板（プレート外側の枠）をミシン目に沿って切り離す

    プレート本体を破損しないように注意しながら、左右と上下の捨て基板を切り離します。  

    固くて折り取るのが難しい場合は、ミシン目をカッターで10-20回ほどなぞると切り離しやすくなります。

    切り離した箇所が尖っている場合は、やすりなどで滑らかにします。

1. （こだわり作業）基板側面をマジックで塗る

### 各基板をひとつに組み合わせる

1. 基板Midのケーブルを、基板Baseのコネクタへ差し込む

    コネクタ`Mid1`, `Mid2`, `Mid3`同士を接続します。

1. ケーブルを基板間の隙間やBase基板のうら側へ逃しながら、基板Midを基板Baseへ乗せ、ネジ穴へはめ込む

    ケーブルに無理な力がかからないように注意します。

1. 基板Baseと基板Midを仮固定する（全11箇所のうち3箇所程度）

    基板Baseのうら側から、基板Midのネジをナットで止めます。  
    後工程の確認作業が完了するまでは、仮固定の状態で作業を進めます。

    ```text
    －－ 基板Mid －－  
    ↓  
    －－ 基板Base －－  
    ↑  
    ナット
    ```

1. 基板Topのケーブルを、基板Midの穴を通しつつ、基板Baseのコネクタへ差し込む

    コネクタ`Top1`, `Top2`, `Top3`同士を接続します。

1. ケーブルを基板間の隙間やBase基板のうら側へ逃しながら、基板Topを基板Midへ乗せ、ネジ穴へはめ込む

    ケーブルをBase基板の穴からうら側へ逃した例  
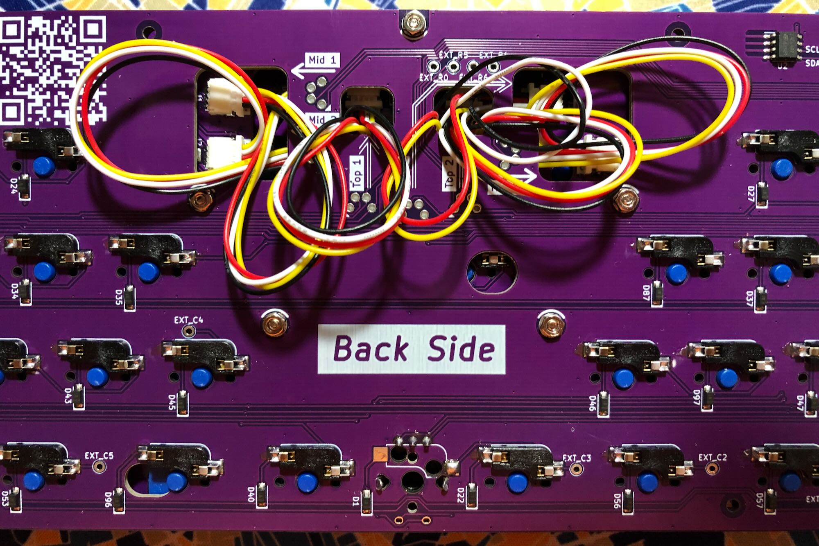
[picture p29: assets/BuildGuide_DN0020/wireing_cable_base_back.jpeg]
ケーブルをBase基板の穴からうら側へ逃した例
    

1. 基板Topのおもて側から、基板Midを3mmネジで止める（8箇所）

    ```text
    3mmネジ  
    ↓  
    －－ 基板Top －－  
    ↑  
    －－ 基板Mid －－
    ```

### スイッチを取り付ける

スイッチの端子が曲がっていないことを確認してから、まっすぐに取り付けます。

1. 基板Midのスイッチを、基板TopのMid用スイッチプレートを介して取り付ける

1. 基板Baseのスイッチを、Base用スイッチプレートを介して取り付ける

1. 基板Topのスイッチを、Top用スイッチプレートを介して取り付ける

### 動作確認をおこない、基板を完全固定する

1. Remapの”Test Matrix Mode”を使用して、すべてのキースイッチが正常に反応するか確認する

    異常がある場合は、原因を調査して修正します。

1. 基板Baseのうら側から、基板Midのすべてのネジをナットで固定する（11箇所）

### （該当者のみ）ボトムプレートへ取り付ける

条件：ボトムプレートを使用する場合

1. ボトムプレートのうら側から、スペーサーを3mmネジでとめる（8箇所）

      ```text
      スペーサー  
      ↑
      －－ ボトムプレート －－  
      ↑
      3mmネジ  
      ```

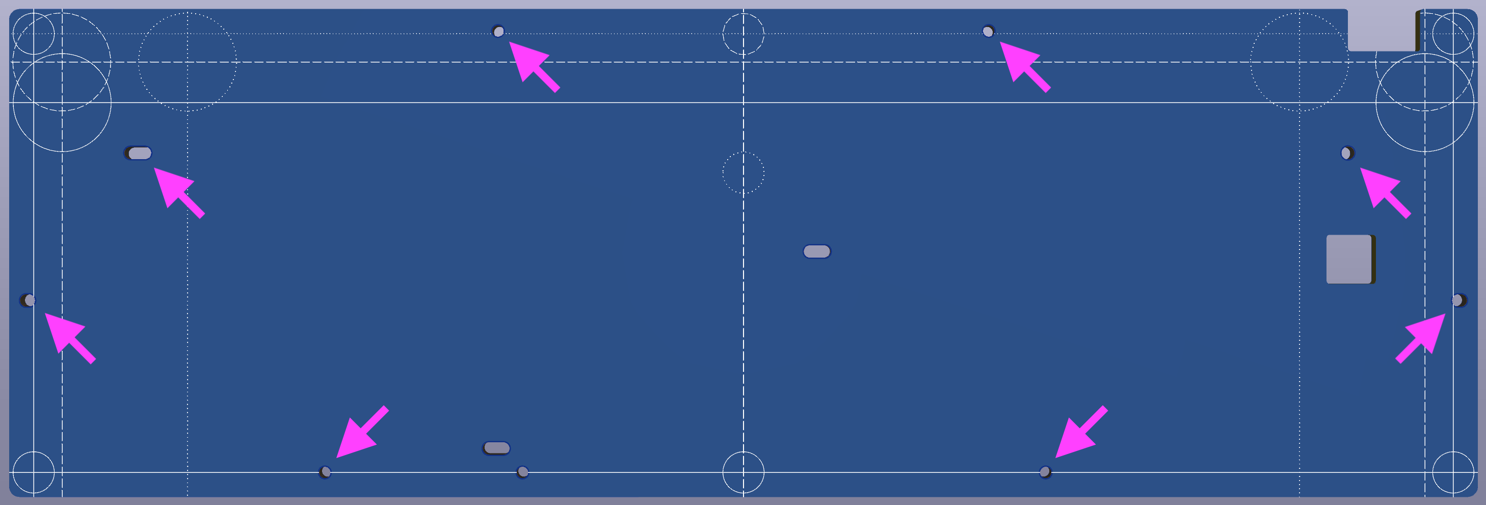
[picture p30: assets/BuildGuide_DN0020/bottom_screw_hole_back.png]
ボトムプレートうら側ネジ止め箇所
    

1. 組み合わせた基板をボトムプレートへ乗せ、ネジ穴とスペーサーの位置を合わせる

1. 基板Baseのおもて側から、ボトムプレートを3mmネジで止める（8箇所）

    ```text
    3mmネジ  
    ↓  
    －－ 基板Base －－  
    ↑  
    －－ ボトムプレート －－
    ```

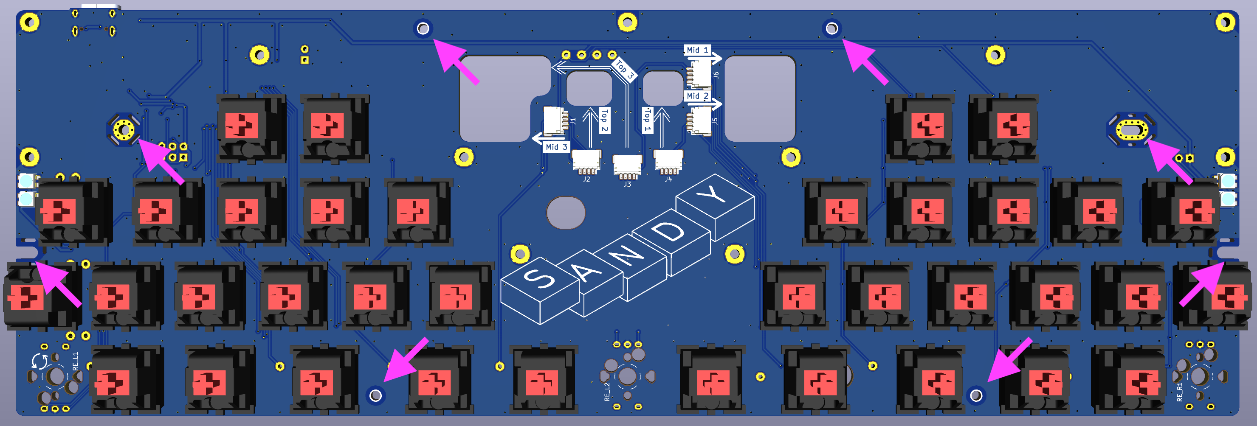
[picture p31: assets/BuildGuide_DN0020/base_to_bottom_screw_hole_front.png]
基板Baseおもて側からボトムプレートへのネジ止め箇所
    

### （該当者のみ）ケースへ取り付ける

条件：ケースを使用する場合

1. 組み合わせた基板を、ケースへそっと入れる

1. 基板Baseおもて側からネジ止めする（左側2箇所、右側2箇所）

    中央と、中央右下のネジは使用しません。

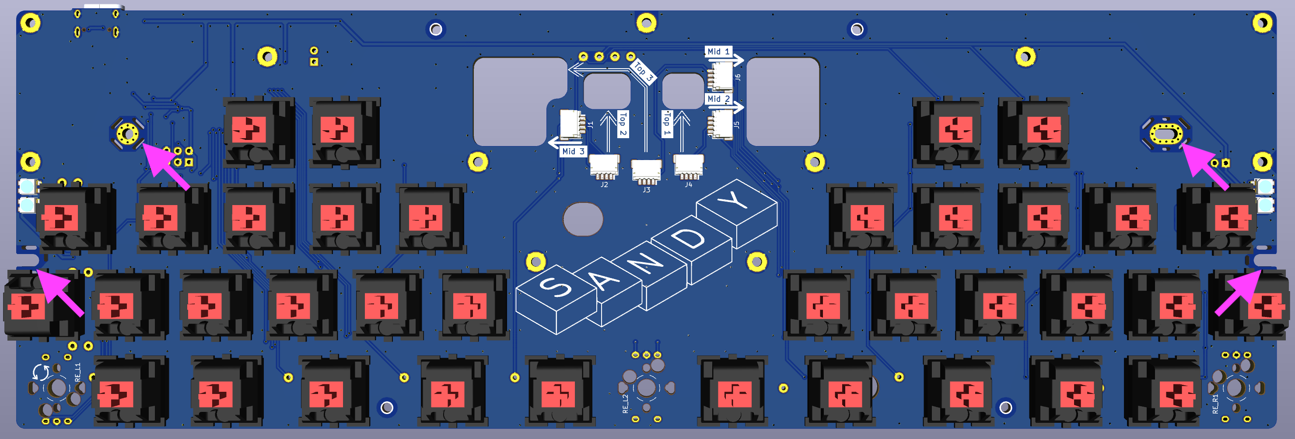
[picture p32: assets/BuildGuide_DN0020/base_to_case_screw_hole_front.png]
基板Baseおもて側からケースへのネジ止め箇所
    

### キーキャップを取り付ける

1. キーキャップを取り付ける

以上で組み立て完了です。

## 参考資料

### 資料：初期ファームウェアの機能と設定値

出荷時に書き込まれている初期ファームウェアの機能と設定値を説明します。

- QMKバージョン

  0.18.17

- キーマップ書き換えツールのRemapに対応。

- レイヤー構成とレイヤーインジケータLEDの色  
  レイヤー0から7まで、8個のレイヤーが使用できます。  
  色が`－`の箇所は、元のレイヤー色が表示されます。

    | No. | レイヤー名 | 主なキー割り当て | レイヤーインジケータLEDの色<br>上, 下 |
    | :-: | :-- | :-- | :-: |
    | 0 | ベースレイヤー #1 | 英語配列 | 白, 白 |
    | 1 | ベースレイヤー #2 | ↑ | 青, 青 |
    | 2 | ベースレイヤー #3 | ↑ | 黄, 黄 |
    | 3 | Lower #1 | ファンクションキー<br>記号<br>オーディオコントロール | 緑, － |
    | 4 | Lower #2 | ↑ | 桃, － |
    | 5 | Raise #1 | ファンクションキー<br>数字<br>カーソル移動 | 水, － |
    | 6 | Raise #2 | ↑ | 橙, － |
    | 7 | Adjust | ベースレイヤー切り替え<br>LED等の設定<br>スクロールロックなど | 赤, － |
    | 番外| CapsLock | n/a | －, 紫 |

- ロータリーエンコーダ

  最大2個に対応。

  - 左側（RE_L1）と中央（RE_L2）のうち、いずれかひとつ

  - 右側（RE_R1）

- その他

  - ベースレイヤーを記憶させる

    キーボードの電源を切ってもベースレイヤーが記憶されるようにするには、  
    デフォルトレイヤー切り替えのキー `DF(0)`, `DF(1)`, `DF(2)` を `Shift` と組み合わせて押します。

    例えば、`Shift + DF(1)` を押すと `ベースレイヤー #2` へ切り替わると同時に、EEPROMへその情報が保存されます。
    EEPROMへ保存されているので、キーボードの電源を切っても、次回接続した際に`ベースレイヤー #2`の状態で起動します。

  - レイヤーインジケータの表示状態を切り替える

    レイヤーインジケータの表示は、  
    `左のみ` → `右のみ` → `左右両方` → `消灯` …  
    の4パターンへ切り替えることができます。

    表示状態を切り替えるには、`Adjust`レイヤーの`O（オー）`を押します。  
    なお、表示状態はEEPROMに保存されます。

  - レイヤーインジケータの明るさを調整する

    レイヤーインジケータの明るさは、RGB Lightingの明るさに合わせるように設定してあります。

    明るさを調整するには、  
    `Adjust`レイヤーの`L`を押してから、（一時的にRGB LightingをONにしてから、）  
    `Adjust`レイヤーの`I`と`K`で明るさを調整し、
    `Adjust`レイヤーの`L`を押します。（RGB LightingをOFFにします。）

### 資料：Sandy関連ファイル

このキーボードに関連するファイルです。  

- ビルド済みファームウェア（QMKバージョン 0.22.14）： sandy_dn0020_qmk_0.22.14_via.hex  
[Sandy_DN0020_files2](https://gist.github.com/jpskenn/3fba73c5b541e13f96ebbfbdbcda088c)（Zipファイルをダウンロードして展開）

    2023年9月11日に更新されたRemap（QMKバージョン 0.22.2以降版）に対応するファームウェアです。  
    機能的な変更はありません。

- ビルド済みファームウェア： sandy_dn0020_via.hex  
  [Sandy_DN0020_files](https://gist.github.com/jpskenn/f1980616959f451fd799d8fc0f839c91)（Zipファイルをダウンロードして展開）

    出荷時に書き込み済みのファームウェアです。  
    [Remap for QMK Firmware 0.18.17 or lower](https://qmk018.remap-keys.app)で、キーの割り当てを変更することができます。  
    ロータリーエンコーダへのキー割り当てをおこなうには、Remapで定義ファイル`sandy_v01_via.json`をインポートしてください。

- ファームウェアのソース

    私がQMKからフォークしたリポジトリ[https://github.com/jpskenn/qmk_firmware](https://github.com/jpskenn/qmk_firmware)の、[develop_Sandy](https://github.com/jpskenn/qmk_firmware/tree/develop_Sandy)ブランチ内、`keyboards/sandy/dn0030`に配置しています。  

    このブランチは、QMKバージョン 0.18.17から派生し、後にQMKバージョン 0.22.14をマージしています。

  - Tags
    - [Sandy_QMK_0.22.14](https://github.com/jpskenn/qmk_firmware/releases/tag/Sandy_QMK_0.22.14)
    - [Sandy_QMK_0.18](https://github.com/jpskenn/qmk_firmware/releases/tag/Sandy_QMK_0.18)

### 資料：QMK Toolboxを使用して、ファームウェアを書き込む方法

[QMK Toolbox](https://github.com/qmk/qmk_toolbox/releases)を使用してビルド済み（＝作成済み）のファームウェアを書き込む方法について説明します。  
（確認したQMK Toolboxのバージョン： 0.2.1）

<details>
<summary>《《《 詳しい説明 》》》</summary>

**ファームウェアを書き込んだ後に初めてRemapに接続した際、キーボードレイアウト画面が表示されるまで30秒〜1分ほどかかる場合があります。**  
EEPROMの初期化処理がおこなわれていますので、キーボードの準備が整うまでしばらくお待ちください。  
2回目以降の接続では、すぐに接続されます。

QMKファームウェアのドキュメント”[ファームウェアを書き込む](https://docs.qmk.fm/#/ja/newbs_flashing?id=ファームウェアを書き込む)”も、あわせてご覧ください。

1. [資料：Sandy関連ファイル](#資料sandy関連ファイル)に記載のダウンロード先から、ビルド済みのファームウェアをダウンロードします。

1. [QMK Toolbox](https://github.com/qmk/qmk_toolbox/releases)をダウンロードし、起動します。

1. `Open`ボタンを押し、QMK Toolboxで、ダウンロードしておいたファームウェアを開きます。

1. `Sandy`キーボードをDFU (Bootloader)モードにします。
    1. USBケーブルが接続されている場合は、ケーブルを抜きます。
    1. キーボードの**左上**のキー（`ESC`や`\``）を押したまま、USBケーブルを差し込みます。

1. QMK Toolboxの画面に、以下のような接続メッセージが表示されます。  
    （もし表示されない場合は、USBケーブルを接続した状態で、基板うら側のリセットボタンを押します）

    ```text
    *** Atmel DFU device connected: ATMEL ATm32U4DFU (03EB:2FF4:0000)
    ```

1. QMK Toolboxの`Flash`ボタンを押すとファームウェアの書き込みが始まります。  
    5秒程度で書き込みが終わり、QMK Toolboxの画面に以下のような書き込み完了メッセージが表示されます。（サイズ表記などの、細かい部分は実際とは異なります）

    ```text
    *** Attempting to flash, please don't remove device
    >>> dfu-programmer atmega32u4 erase --force
        Erasing flash...  Success
        Checking memory from 0x0 to 0x6FFF...  Empty.
    >>> dfu-programmer atmega32u4 flash --force /Users/jpskenn/qmk_firmware/nora_v01_via.hex
        0%                            100%  Programming 0x5E80 bytes...
        [>>>>>>>>>>>>>>>>>>>>>>>>>>>>>>>>]  Success
        0%                            100%  Reading 0x7000 bytes...
        [>>>>>>>>>>>>>>>>>>>>>>>>>>>>>>>>]  Success
        Validating...  Success
        0x5E80 bytes written into 0x7000 bytes memory (84.38%).
    >>> dfu-programmer atmega32u4 reset
    *** Atmel DFU device disconnected: ATMEL ATm32U4DFU (03EB:2FF4:0000)
    ```

    書き込み完了メッセージが表示されたら、QMK Toolboxを終了してもかまいません。  

    これとは違うメッセージ（書き込み失敗など）が表示された場合は、スクリーンショットを撮ったり、メッセージをコピーしておくと、何らかのサポートを受ける場合にスムースに話が進みます。

1. 書き込みが終わってから30秒程度でキーボードが起動し、キー入力できるようになります。  
  ファームウェアを書き込んだ後、初回起動時に外部EEPROMの消去をおこなっています。  
  この消去処理にしばらく時間がかかっています。

1. リセットボタンを使ってDFUモードにする操作をおこなった場合は、[資料：EEPROMを消去して、初期状態に戻す方法](#資料eepromを消去して初期状態に戻す方法)をおこないます。

以上でQMK Toolboxを使用したファームウェアの書き込み作業は完了です。

</details>

### 資料：EEPROMを消去して初期状態に戻す方法

EEPROMに記録されているデータを消去し、初期状態に戻す方法について説明します。  

<details>
<summary>《《《 詳しい説明 》》》</summary>

キーマップやLEDの表示モードなどのEEPROMに記録されているデータを消去し、初期状態に戻すことができます。  

また、古いデータが残って動作がおかしくなるのを防止するため、リセットボタンを使用してファームウェアを書き込んだ際にもこの操作をおこないます。

1. USBケーブルを接続している場合は、ケーブルを抜きます。

1. キーボードの左上のキーを押したまま、USBケーブルを差し込みます。

1. ケーブルを差し込んで、1、2と数えてから、USBケーブルを抜きます。

1. USBケーブルを差し込みます。

1. 10秒ほど待つとキーボードが起動します。

以上でEEPROMが消去され、初期状態に戻ります。

</details>

## サービスマニュアル

基板の準備やファームウェアの書き込みなど、出荷前の作業メモです。

<details>
<summary>《《《 詳しい説明 》》》</summary>

### パーツリスト

| 部品名 | 個数 | 備考 |
| :---- | :-----: | :---- |
| USBコネクタ<br>USB4085-GF-A または TYPE-C-31-M-12 | 1 | 製造により異なる |
| ESD<br>PRTR5V0U2X | 1 | 取り付け方向は基板の印を参照 |
| FUSE<br>0ZCJ0050AF2E | 1 ||
| リセットスイッチ<br>RS-187R05A2-DSMTRT | 1 ||

### 基板セットアップ

作業対象は基板Baseのみ

1. 部品取り付け

    1. 基板うらからUSBコネクタを取り付ける

        テスターでピン接続、ショートしないことを確認する。
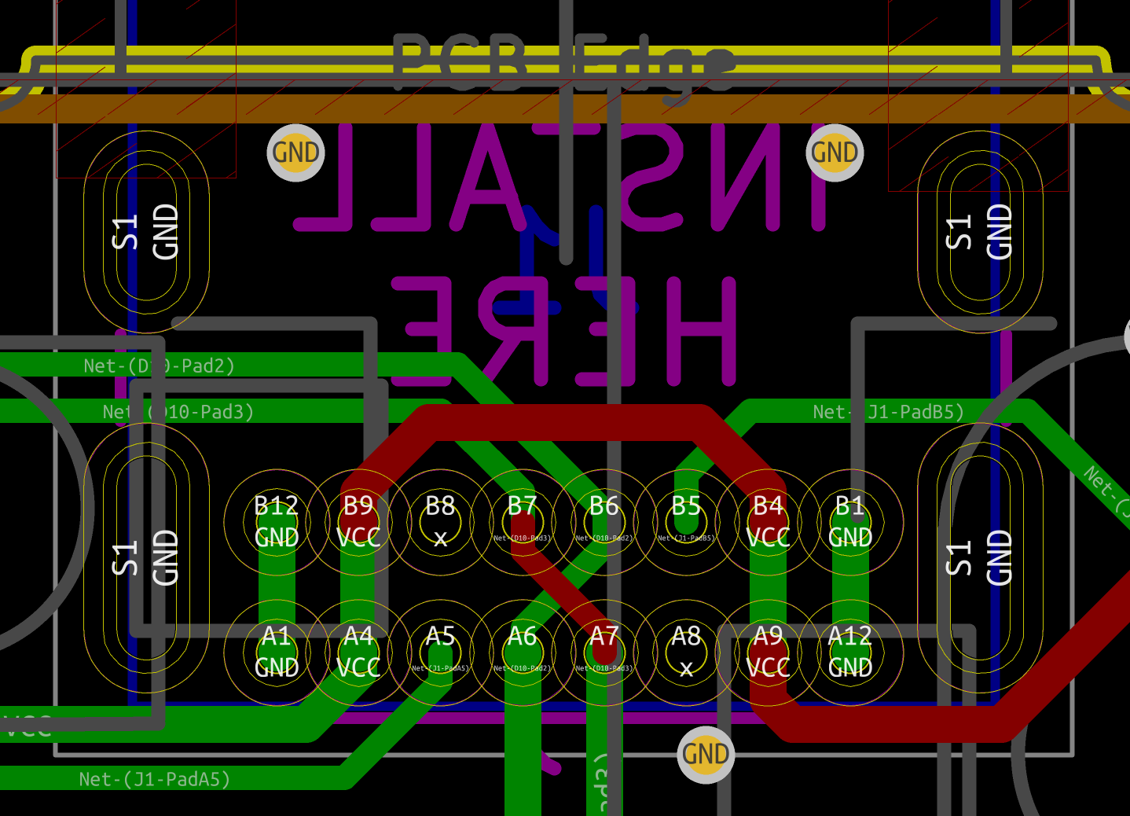
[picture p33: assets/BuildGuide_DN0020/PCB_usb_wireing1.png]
USBコネクタ接続図（USB4085-GF-A）
          
        USBコネクタ接続図（USB4085-GF-A）

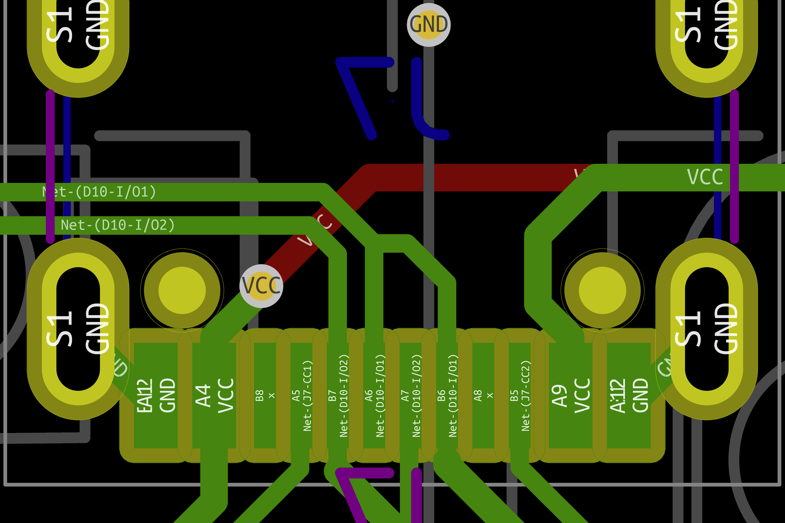
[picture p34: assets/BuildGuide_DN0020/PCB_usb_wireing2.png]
USBコネクタ接続図（TYPE-C-31-M-12）
          
        USBコネクタ接続図（TYPE-C-31-M-12）

    1. 基板うら側`D10`へESDを取り付ける

        基板に描かれた取り付け方向を参照

    1. 基板うら側`F1`へFUSEを取り付ける

        方向なし

    1. リセットスイッチを取り付ける

        方向なし

1. ファームウェア書き込み

    1. QMK Toolboxを起動して、書き込むファームウェアを開く

    1. 基板をPC/Macへ接続

        QMK Toolboxに、デバイスの接続メッセージが表示されることを確認。

    1. 基板のリセットスイッチを押す

        QMK Toolboxに、デバイスの切断と接続のメッセージが表示されることを確認。

    1. QMK Toolboxの`Flash`ボタンを押して書き込む

    1. Remapを開いて接続

        → EEPROMの初期化に1分ほどかかる

    1. Remapでスイッチソケットのパッドの反応を確認する

</details>

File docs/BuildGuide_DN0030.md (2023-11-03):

# Sandy（DN0030）ビルドガイド

このドキュメントは、Sandy（DN0030）を組み立てるためのビルドガイドです。

開発番号`DN0030`は、各基板のうら側に記載されています。
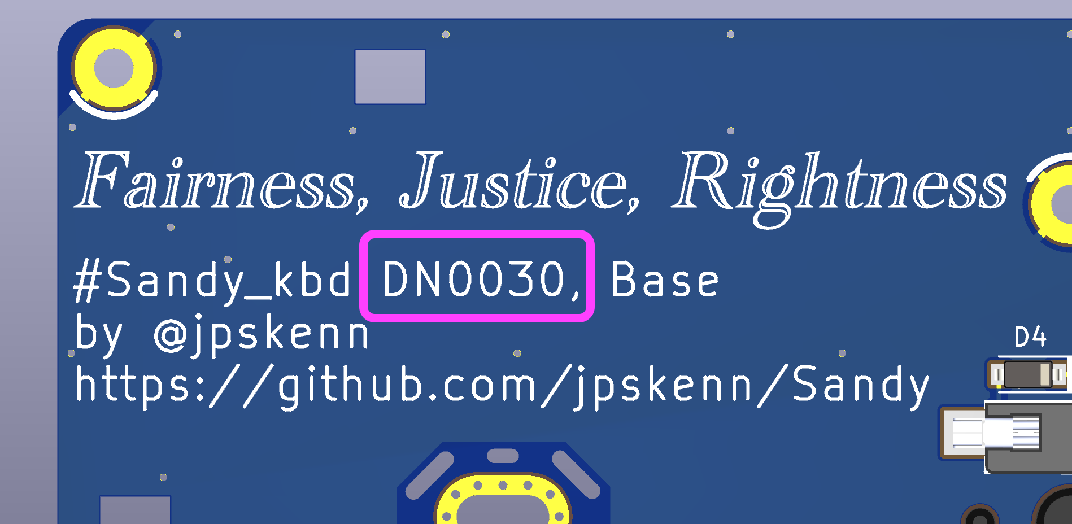
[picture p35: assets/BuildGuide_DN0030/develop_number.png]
開発ナンバー


Sandyのコンセプトや特徴、ビルド例などについては、こちらの[README](/README.md)をご覧ください。

ビルドガイド全体に目を通して作業手順を把握しておくとミスの防止につながりますので、ぜひ、一度お読みになってから組み立て作業を始めてください。

折り畳まれた項目は、

<details>
<summary>《《《 詳しい説明 》》》</summary>

ここに追加の説明を表示します。
</details>

と書かれたところをクリックすると、追加の説明が表示されます。

---

## 目次

<!-- @import "[TOC]" {cmd="toc" depthFrom=2 depthTo=2 orderedList=false} -->

<!-- code_chunk_output -->

- [目次](#目次)
- [注意事項](#注意事項)
- [組み立て難易度](#組み立て難易度)
- [部品リスト](#部品リスト)
- [組み立てに使用する工具](#組み立てに使用する工具)
- [組み立て手順](#組み立て手順)
- [カスタマイズガイド](#カスタマイズガイド)
- [サービスマニュアル](#サービスマニュアル)

<!-- /code_chunk_output -->

## 注意事項

- 一部のキーは上下反転して取り付けます

  - 3行目左右端（1.5uのキーを使用する場合）
  - 4行目左端

- ファームウェアについて

  出荷時に書き込み済みのファームウェアは、QMKバージョン 0.18.17です。  
  [Remap for QMK Firmware 0.18.17 or lower](https://qmk018.remap-keys.app)で、キーの割り当てを変更することができます。  
  ロータリーエンコーダへのキー割り当てをおこなうには、Remapで定義ファイル`sandy_v01_via.json`をインポートしてください。

  QMKバージョン 0.22.14のファームウェアに書き換えると、[Remap](https://remap-keys.app/)で、ロータリーエンコーダを含むキーの割り当てを変更できるようになります。

## 組み立て難易度

- 通常版キット： **★★★☆☆ ふつう**

    一般的なはんだ付けとネジ止めができれば、高度なテクニック不要で組み立てられます。  
    初めてキーボードキットを組み立てる方や不慣れな方にはちょっと難しいかもしれませんが、まぁなんとかなるでしょう。

- 通常版以外のキット： **★★★★☆ そこそこ難しい**

    コツをつかむまでは、SHコネクタの取り付けに苦労するでしょう。  
    はんだ付け作業自体は難しくありませんが、端子間隔が狭いため、はんだブリッジが起こりやすくなっています。  
    さらに、その箇所を目視確認するのも困難なため、テスターでの確認がほぼ必須となります。  
    はんだ付けを数回やった程度の方には、かなりチャレンジングな作業になると思われます。  

    なお、はんだブリッジが起きても修正すれば復旧できるので、致命傷ではありません。

## 部品リスト

このキットを組み立てるためには、[キット内容](#キット内容)に加え、[別途用意が必要な部品](#別途用意が必要な部品)が必要です。  

[オプション部品](#オプション部品)は、使いたい機能に応じて用意します。  

### キット内容

| 番号 | 部品名 | 個数 | 備考 |
| :--: | :-- | :--: | :-- |
| 1 | ご案内リーフレット | 1 | |
| 2 | 基板Base | 1 | |
| 3 | 基板Mid | 1 | |
| 4 | 基板Top | 1 | Mid用スイッチプレートを兼ねる |
| 5 | Base用スイッチプレート | 1 | 捨て基板（プレート外側の枠）を切り離して使用 |
| 6 | Top用スイッチプレート | 1 ||
| 7 | ボトムプレート | 1 ||
| 8 | SH 4pinケーブル<br>（いわゆるQwiicケーブル） | 6※ | ※1本をTop基板に取り付け済みの場合あり<br> [PRT-17260](https://www.digikey.jp/ja/products/detail/sparkfun-electronics/PRT-17260/13629028) |
| 9 | スペーサー<br>両メネジ M2 3mm | 16 | [ヒロスギ ASB-2003E](https://hirosugi.co.jp/products/B/ASB-E.html#bx3) |
| 10 | ナット<br>M2 2種 高さ1.6mm | 22 | [ウィルコ FNT-02N-2](https://wilco.jp/products/F/FNT-N-2.html) |
| 11 | ワッシャー<br>M2 内径2.3mm 外径4.3mm 厚さ0.4mm| 19 | [ウィルコ FW-0204-04N](https://wilco.jp/products/F/FW-N.html#page3) |
| 12 | ネジ<br>M2 3mm | 32 | [ウィルコ F-0230N-03](https://wilco.jp/products/F/F-N-02.html#page3) |
| 13 | ネジ<br>M2 7mm | 11 | [ウィルコ F-0270N-03](https://wilco.jp/products/F/F-N-02.html#page3) |
| 14 | ゴム足（大） | 2 | [KKU-122]() |
| 15 | ゴム足（小） | 3 | [CS-102](https://www.3mcompany.jp/3M/ja_JP/p/d/v000453068/) |
| 16 | LED<br>SK6812MINI-E | 2 | [マイコン内蔵ＲＧＢＬＥＤ　ＳＫ６８１２ＭＩＮＩ－Ｅ](https://akizukidenshi.com/catalog/g/gI-15478/) |
| 17 | スイッチ用ソケット<br>（MXスイッチ用） | 68 | 予備含む<br>[MXスイッチ用 Kailh PCBソケット](https://talpkeyboard.net/items/5e02c5405b120c792616bcf9) |
| 18 | SHコネクタ<br>JST SH ベース サイド型 4pin 面実装 | (6) | 通常版以外のキットに付属<br>[SM04B-SRSS-TB(LF)(SN)](https://www.lcsc.com/product-detail/_JST-Sales-America-_C160404.html) |

※出荷時期によって、機能的に同等なものへ変更することがあります。

3枚の基板  
基板3枚。  
上から順に、基板Top、基板Mid、基板Base。

3枚の基板  
プレート類。  
上から順に、Top用スイッチプレート、Base用スイッチプレート、ボトムプレート。

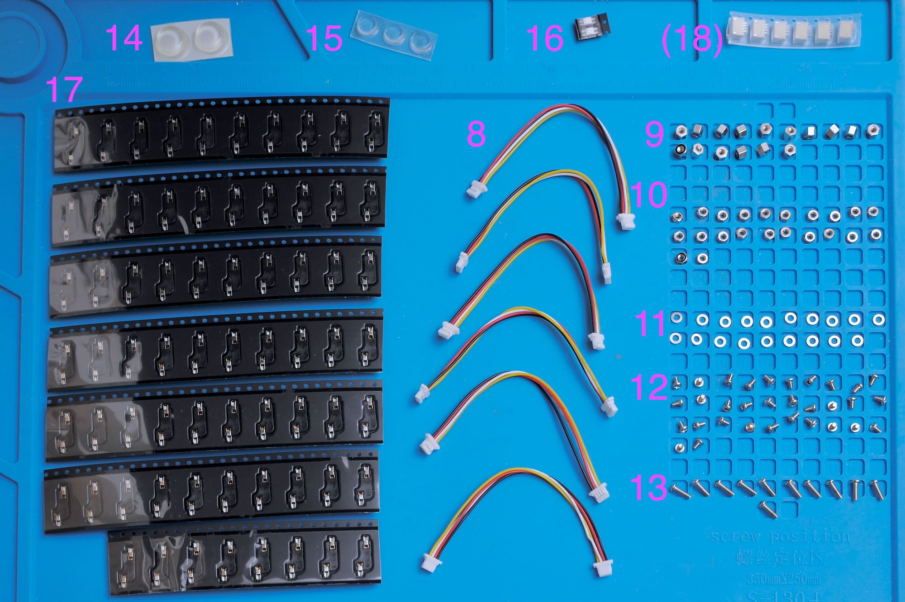
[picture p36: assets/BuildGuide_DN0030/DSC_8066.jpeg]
その他部品
  
その他部品

### 別途用意が必要な部品

完成させるには、これらの部品を別途用意する必要があります。

| 部品名 | 個数 | 備考 |
| :-- | :--: | :-- |
| Cherry MX（互換）スイッチ | 66〜最大67 | 3pin、5pinどちらにも対応。<br>組み立てるレイアウトにより使用数が変動します。 |
| キーキャップ<br>Cherry MX（互換）スイッチ用 | 必要数 | 英語104キーキャップセットにスペースキー用として1.5uのキー2個を追加すると、ぴったり埋めることができます。<br>バラ売りのブランクDSAキーキャップなどを追加したり、1.5uのALTキーなどが含まれるセットを購入すると良いでしょう。<br>日本語108キーキャップセットはBSキーとして使う1.5uキーが足りないため、おすすめしません。<br>参考： [Sandy（DN0030）のレイアウト](http://www.keyboard-layout-editor.com/#/gists/c907e866d8f82b82a22b455e622b7301) |
| USBケーブル （Type-C） | 1 | |

### オプション部品

これらの部品は、使いたい機能に応じて用意します。

| 部品名 | 個数 | 備考 |
| :-- | :--: | :-- |
| ロータリーエンコーダ<br>ALPS EC11, EC12同等品 | 1 | ロータリーエンコーダを使用する場合<br>プッシュスイッチ付きにも対応<br><br>取り付け確認済みのロータリーエンコーダは以下の通りです。<br>- EC12E24204A2<br>- EC11K1525401 |
| ロータリーエンコーダ用ノブ（つまみ） | 1 | ロータリーエンコーダを使用する場合 |
| LED<br>SK6812MINI-E | 16 | アンダーグローLEDを取り付ける場合<br>[マイコン内蔵ＲＧＢＬＥＤ　ＳＫ６８１２ＭＩＮＩ－Ｅ](https://akizukidenshi.com/catalog/g/gI-15478/) |
| GH60型ケース | 1 | ボトムプレートを使わず、ケースへ取り付ける場合。<br><br>ケースへの固定には、中央と中央下のネジは使用しません。左右2本ずつ、合計4本のネジだけで取り付けます。<br>すべてのGH60型ケースへの対応を確認していないため、ケース内部の構造によっては取り付けに加工が必要になったり、取り付けできないことも考えられます。<br><br>取り付け確認済みのケースは以下の通りです。<br>- KBDfans TOFU 60% ALUMINUM CASE<br>- KBDfans 5° FIVE DEGREE 60% ALUMINUM CASE<br>- KBDfans 60% ALUMINUM LOW PROFILE CASE<br>- 60% プラスチックケース（簡単な加工が必要） |

## 組み立てに使用する工具

こちらの[工具セット](https://shop.yushakobo.jp/products/a9900to)などを参考に、工具を用意します。

- 必要な工具

  - M2ネジに対応する、先の細いプラスドライバー（+0）

    スイッチとスイッチの間などに差し込みやすい”細軸タイプ”がおすすめ。

  - はんだ付け関連用品

    温度調整機能つきのはんだごてを推奨します。

  - ピンセット

- あると便利な工具

  - マジックペン

    基板の側面を塗ると、完成時の質感が上がります。  
    暗めの色を塗る場合は[プロッキー](https://www.mpuni.co.jp/products/felt_tip_pens/water_based/sign_pen/prockey.html)を、明るめの色を塗る場合は不透明顔料インクの[ポスカ](https://www.mpuni.co.jp/products/felt_tip_pens/water_based/posca/standard.html)を使うなど、お好みで。

    太字角芯と極細をそれぞれ用意しておくと作業がはかどります。

  - M2ナット対応のレンチ，ナットドライバー

    ナットを締める箇所が多いので、あると作業が格段に楽になります。  
    [タミヤ SP.38 工具セット](https://www.tamiya.com/japan/products/50038/index.html)の十字レンチが安くておすすめ。

  - カッター，はさみ

    捨て基板（捨て板）のミシン目に切り込みを入れて、切り離しやすくします。

  - ニッパー

    ケースへ取り付ける場合、ケース内部の構造によっては、スイッチの足やケース内のリブをカットする必要があるかもしれません。

  - テスター

    はんだ付けの確認作業や、何か不具合があった場合の原因調査で活躍します。  
    **通常版以外のキットでSHコネクタを取り付ける場合は、ほぼ必須。**

  - フラックスやハンダ吸い取り線

    小さな部品のはんだ付けや修正、部品の取り外しなどがしやすくなります。

## 組み立て手順

手順に沿って、順番に組み立てます。

- `（こだわり作業）`の手順は、完成時の質感を重視した内容であり、不要であれば作業をとばしてもかまいせん。

- `（該当者のみ）`の手順は、条件に該当する場合のみ作業します。

- おもて側とうら側を間違えないよう、基板うら側の`Back Side`の表記を確認しながら作業を進めます。

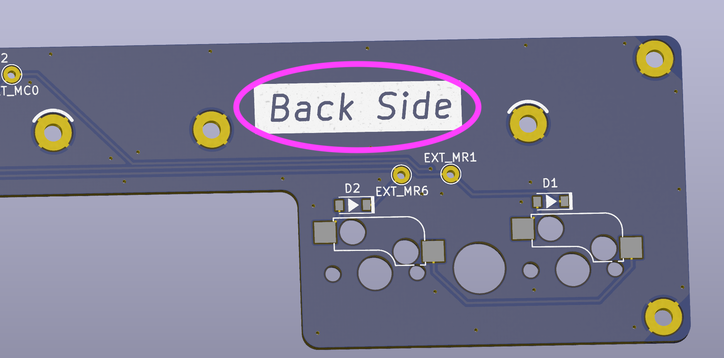
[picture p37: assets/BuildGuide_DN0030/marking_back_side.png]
Back Sideの印
  

### 組み立て前の確認

輸送時の破損なども考えられるため、組み立てを始める前に基板Baseの動作確認をおこないます。  
確認結果に問題がある場合は、リーフレットに記載の連絡先へ相談してください。

1. 基板Baseを、うら側を上にして安定した場所へ置く

1. 基板BaseのUSBコネクタへケーブルを差し込み、PCやMacに接続する

1. PCやMacで認識されていることを確認する

    - Windows  
    設定 → キーボード  
    ”Sandy”が表示されていること

    - Mac  
    システムレポート → USB  
    ”Sandy”が表示されていること

1. [Remap](https://remap-keys.app/)を、対応するブラウザ（ChromeやEdgeなど）で開く

    💡ヒント：出荷時のファームウェアを書き換えていない場合は、[Remap for QMK Firmware 0.18.17 or lower](https://qmk018.remap-keys.app)を開きます。

1. キーボードをRemapに接続する

    1. `START REMAP FOR YOUR KEYBOARD`
    1. `+ KEYBOARD`
    1. `Sandy`を選択
    1. `接続`

1. 画面にキーボードのレイアウトが表示されるまでしばらく待つ。

    30秒待っても表示されないときは、ブラウザをリロードしてやり直します。

1. "Layout Option"で以下のようにレイアウトを指定する

    - Left Shift: 1u + 1u
    - Bottom Keys: 5 keys
    - Rotary Encoder, Left / Center: Off
    - Rotary Encoder, Right: Off
    - 5-way navigation: Off

1. ”Test Matrix Mode”を開く

1. キースイッチの反応を確認する

    基板Baseうら側のスイッチソケット取り付け用パッド（銀色の四角い端子部分）をピンセットなどでショートさせ、ブラウザ画面上の対応するキーの色が変わることを確認します。

    以下のように色が変われば正常です。  
    基板Base確認結果

### 組み立てるレイアウトを決める

以下のポイントを念頭に、組み立てるレイアウトを決めます。

- キーのサイズ

  - Control（左）：1.25u または 1.5u

  - Enter（右）：1.25u または 1.5u

- ロータリーエンコーダ

  - 中央（RE_L2）：有 または 無

参考：[SandyのレイアウトSandyのレイアウト](http://www.keyboard-layout-editor.com/#/gists/c907e866d8f82b82a22b455e622b7301)

### Base用スイッチプレートの捨て基板を切り離す

  プレート上部の捨て基板（プレート外側の枠）を、ミシン目に沿って折り取るようにして切り離します。  
  プレート本体を破損しないように注意しながら作業します。

  折り取るにはそこそこ力が必要で、`うにぃぃいいいい…`と力を入れて曲げていくと、最後に`ベキッ！`という具合にミシン目から折れます。  
  💡ヒント：ミシン目をカッターやはさみで10-20回ほどなぞって切れ込みを入れておくと折りやすくなります。

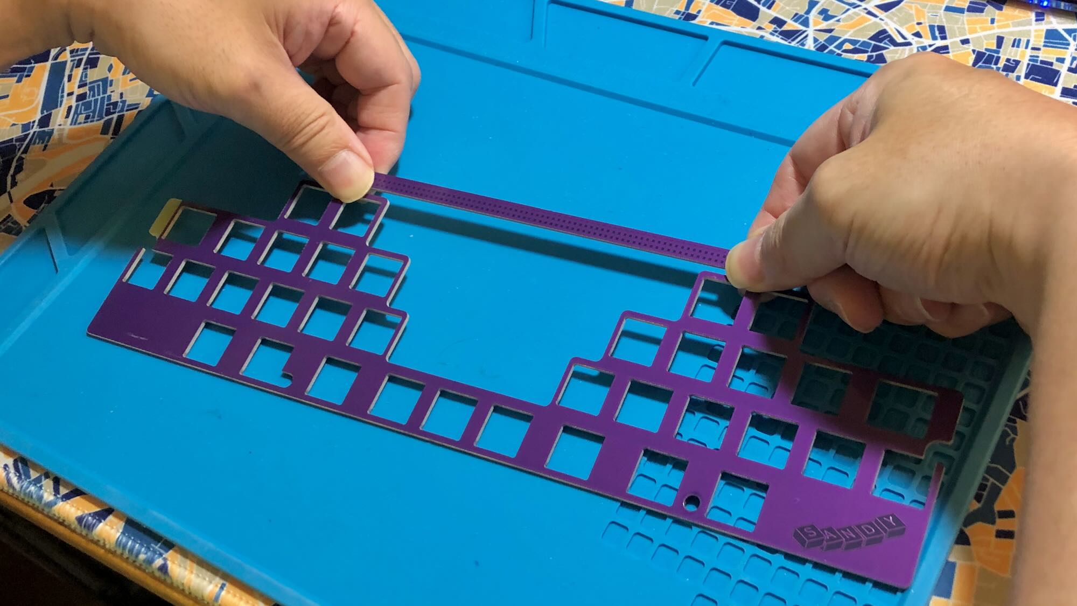
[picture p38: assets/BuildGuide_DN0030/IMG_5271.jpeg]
捨て基板を切り離す様子
  

  切り離した箇所が尖っていることがあるので、怪我をしないように気をつけます。

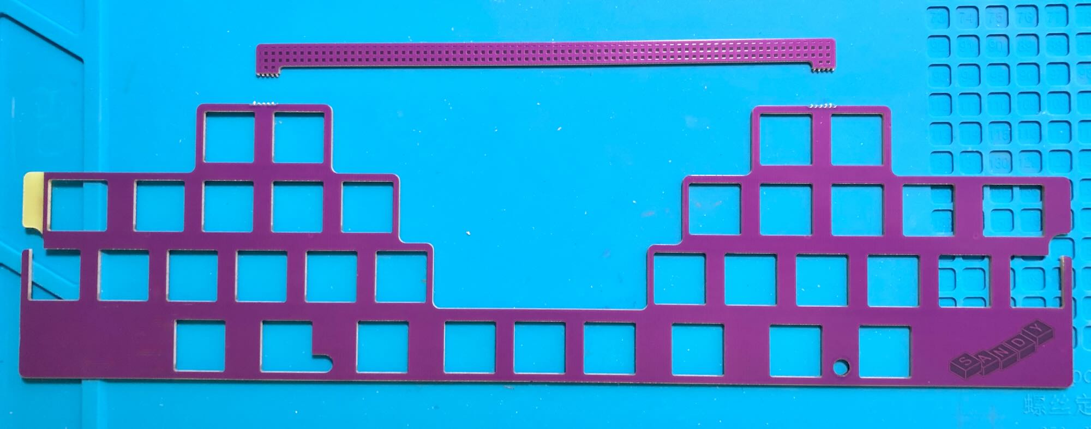
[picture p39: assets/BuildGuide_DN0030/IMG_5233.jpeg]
Base用プレート切り離し箇所
  

### （こだわり作業）基板とプレート側面をマジックで塗る

完成時の質感を高めるため、基板とプレートの側面をマジックで塗ります。

💡ヒント：組み立て後は一旦分解しないと塗れなくなる箇所があります。どうせやるなら、最初からやってしまう方が楽です。

上：基板そのままの色，下：プロッキーの紫で塗った色
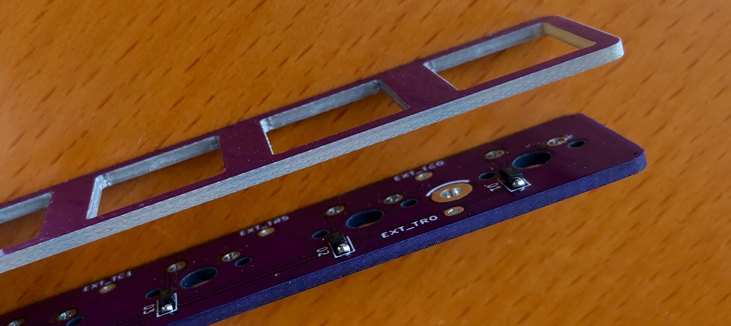
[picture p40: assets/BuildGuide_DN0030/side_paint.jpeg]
基板側面を塗った様子


### 基板Topの準備

1. うら側から、スイッチ用ソケットを取り付ける（19個）

    ‼️注意：出荷時にケーブルが取り付けらている場合は、ケーブルを取り外さないでください。

    基板に描かれた枠に合わせてソケットを置きます。  
    はんだごての温度を270度程度にセットして、はんだ付けします。  
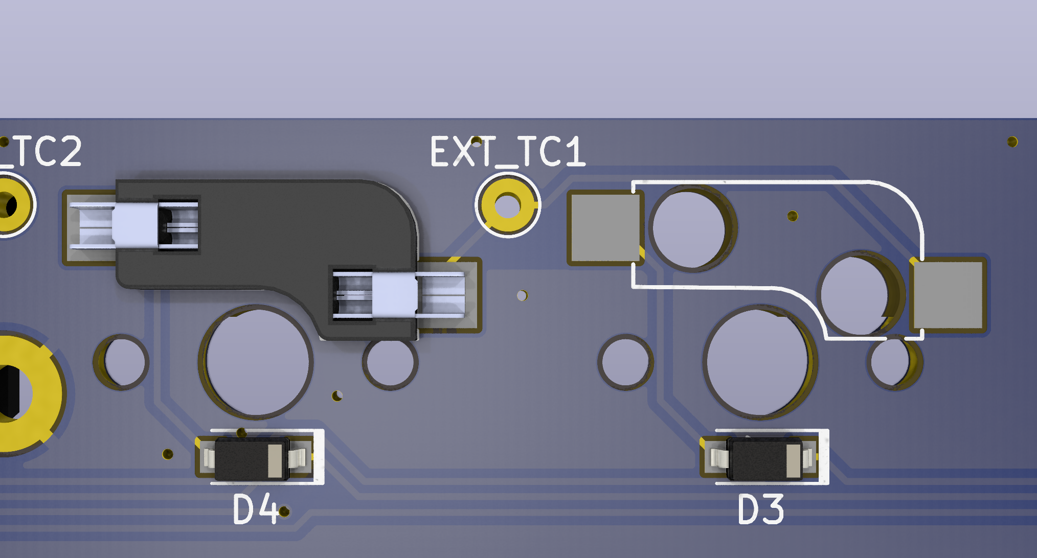
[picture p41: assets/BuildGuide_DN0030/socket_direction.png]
ソケット取り付け方向
    

    ソケットが基板から浮かないように注意し、基板にぴったりと接するように取り付けます。
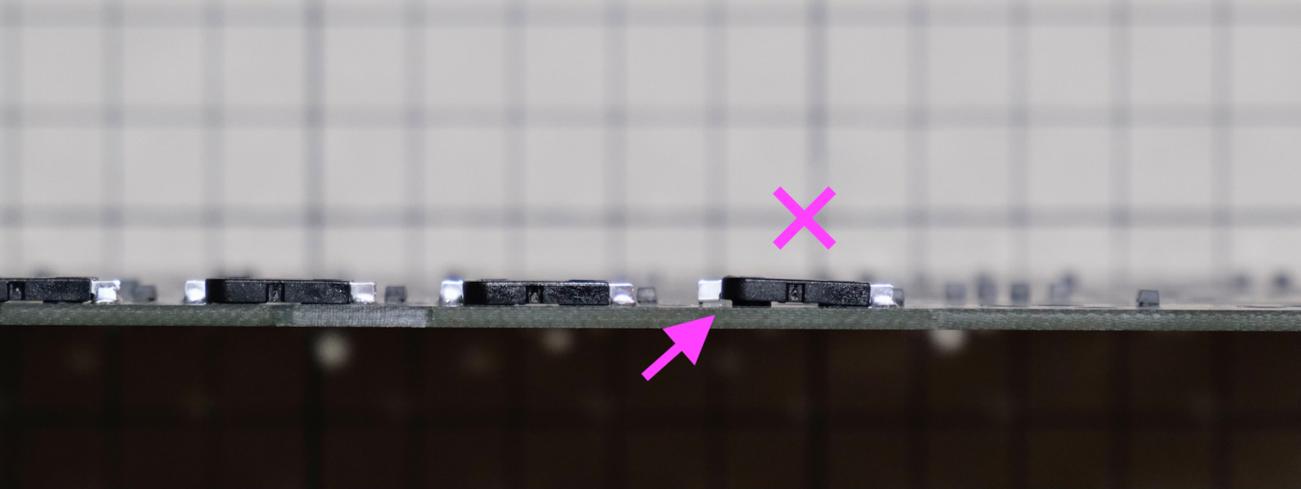
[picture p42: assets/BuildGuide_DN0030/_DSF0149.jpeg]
ソケットの浮き
    

1. 方向を合わせて、コネクタへケーブルを差し込む（3本）

    うら側（`Top1`, `Top2`, `Top3`）  
    （出荷ロットによっては、`Top3`にケーブルを取り付け済みの場合があります。）

    **ケーブルの端子側が上**になるように、方向を合わせて真っ直ぐに差し込みます。  
    コネクタが基板からもげてしまわないように、上から押さえたり後ろを支えたりしながらケーブルを差し込むと安心です。

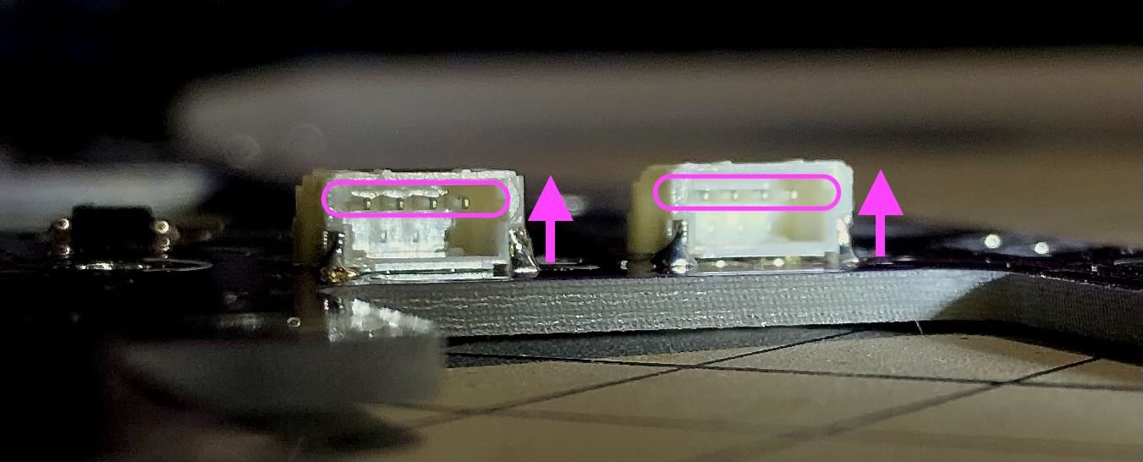
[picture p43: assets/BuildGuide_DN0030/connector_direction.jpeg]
SHコネクタ接続方向
    

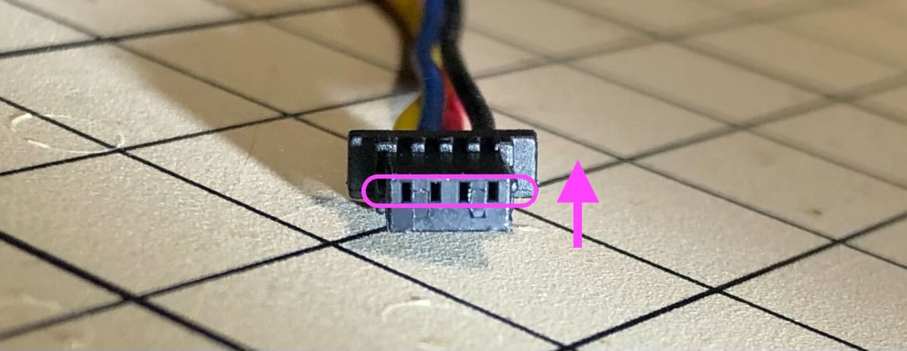
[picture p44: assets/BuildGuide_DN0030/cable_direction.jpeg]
ケーブル接続方向
    

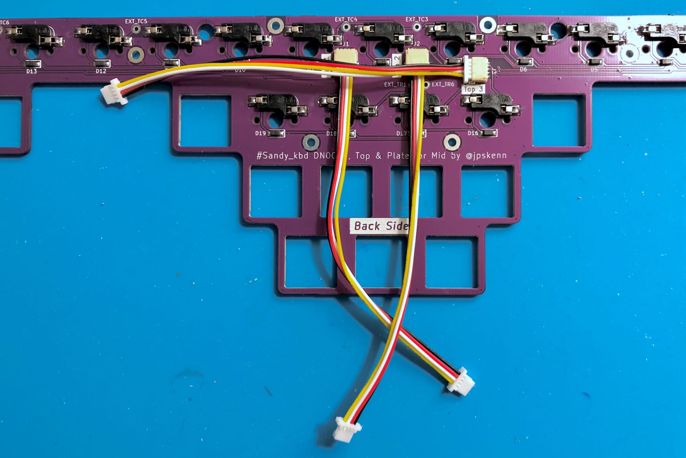
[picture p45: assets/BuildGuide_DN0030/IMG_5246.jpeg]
Top基板のコネクタにケーブルを差し込んだ様子
    

### 基板Midの準備

1. うら側から、スイッチソケットを取り付ける（13個）

1. おもて側から、ワッシャーを挟んだナットを7mmネジでとめる（11箇所）

    ナットを締め込みすぎないよう、`グイグイ` `グググーッ`と締め込むのではなく、ナットを回して最初に`ククッ`と止まったところでやめます。

    ```text
    7mmネジ  
    ↓  
    －－ 基板Mid －－  
    ↓  
    ワッシャー  
    ↓  
    ナット
    ```

    基板Midおもて側ネジ止め箇所

    💡ヒント：ネジ穴に印がついている側から、ネジを差し込みます。  
    ネジ穴の印  

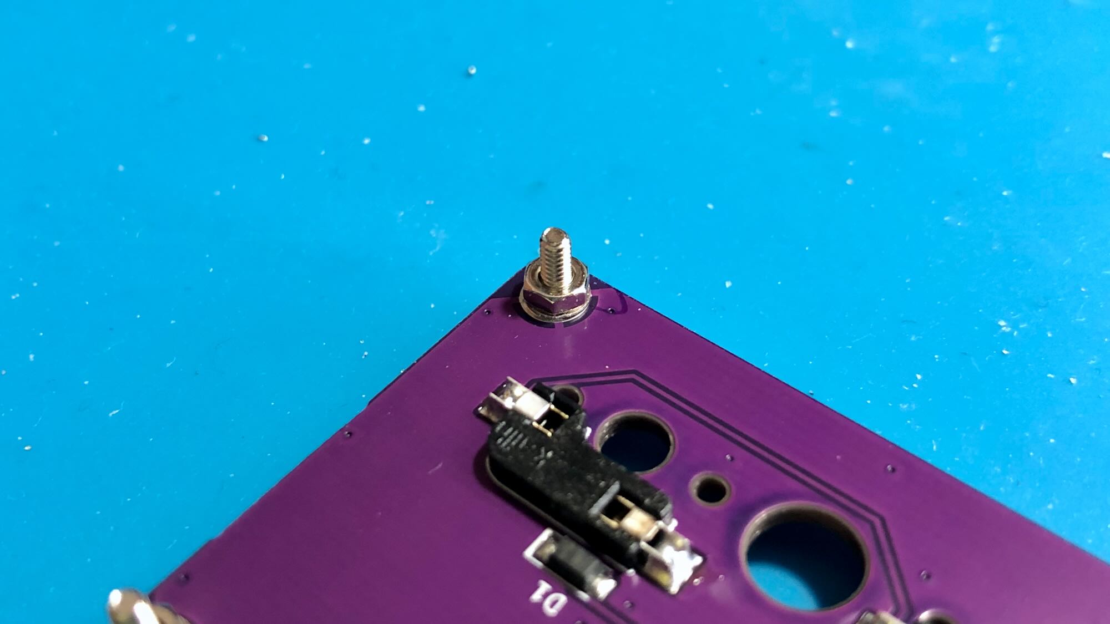
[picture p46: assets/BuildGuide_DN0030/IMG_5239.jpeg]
ナットを7mmネジを止めた様子
    

1. うら側から、ワッシャーを挟んだスペーサーを3mmネジでとめる（8箇所）

      ```text
      スペーサー  
      ↑
      ワッシャー  
      ↑
      －－ 基板Mid －－  
      ↑
      3mmネジ  
      ```

    基板Midうら側ネジ止め箇所

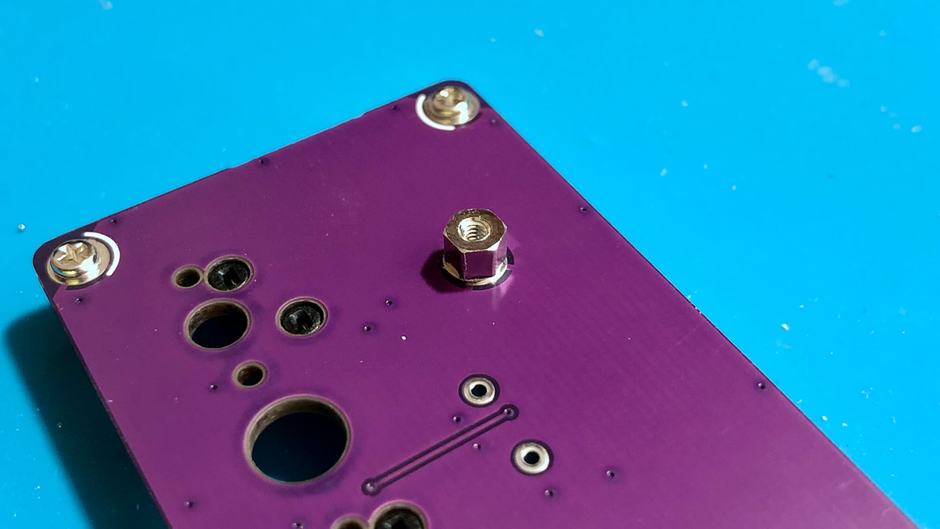
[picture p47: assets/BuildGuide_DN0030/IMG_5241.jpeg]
スペーサーを3mmネジで止めた様子
    

1. 方向を合わせて、コネクタへケーブルを差し込む（3本）

    うら側（`Mid1`, `Mid2`, `Mid3`）

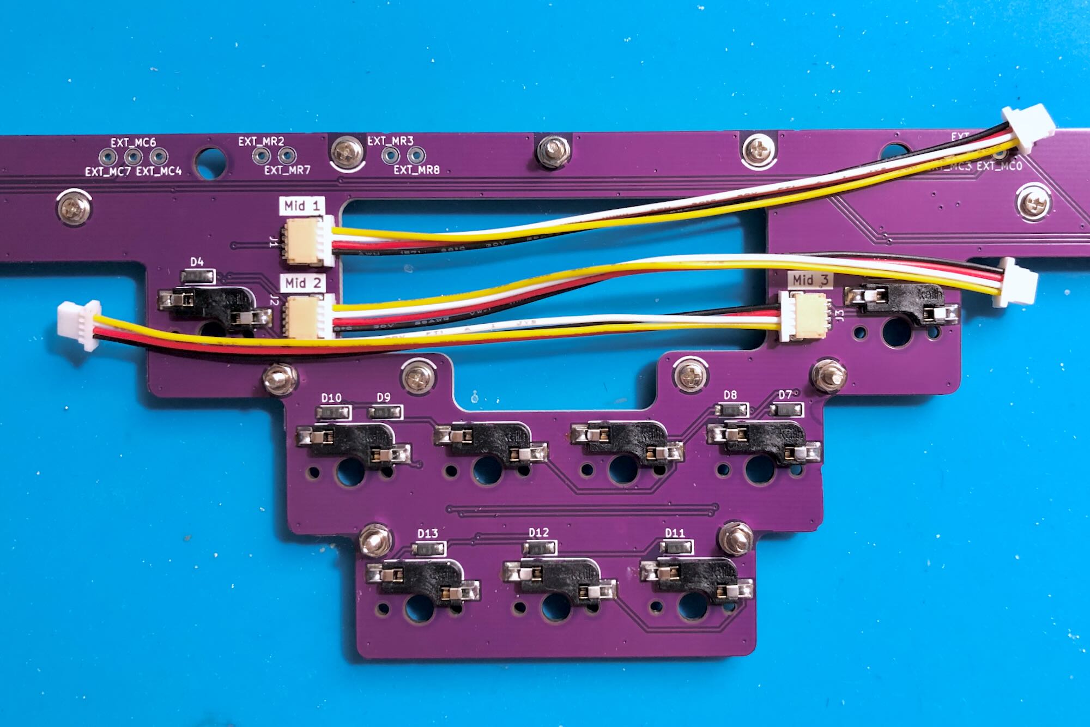
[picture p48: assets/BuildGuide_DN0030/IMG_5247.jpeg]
基板Midのコネクタにケーブルを差し込んだ様子
    

### 基板Baseの準備

1. うら側から、スイッチソケットを取り付ける（34〜35個）

    組み立てるレイアウトに合わせてソケットを取り付けます。  
    Control（左）とEnter（右）は、`1.25u`または`1.5u`のいずれか1個を取り付けます。  
    ロータリーエンコーダを取り付ける場合は、ソケットは不要です。

    また、最下行の左右端から2個ずつ、`×`マークのついた箇所には取り付けません。

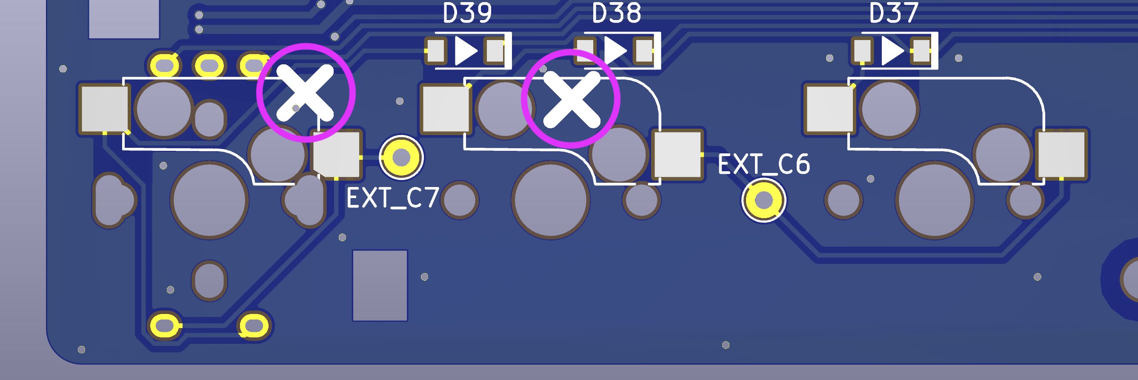
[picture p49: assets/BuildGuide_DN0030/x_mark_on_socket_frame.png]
×マークのついた箇所
    

1. （該当者のみ）うら側から、インジケータLEDを取り付ける（2個）

    条件：インジケータLEDを使用する場合

    うら側（`L1`, `L2`）

    基板に描かれた印にLEDの端子の切り欠き部分を合わせ、LED発光部が基板おもて側になるようにはめこみます。  
    220度程度の温度ではんだ付けします。  
    （はんだが溶けにくい場合は、270度程度まで温度を上げ、短時間の作業をおこないます）

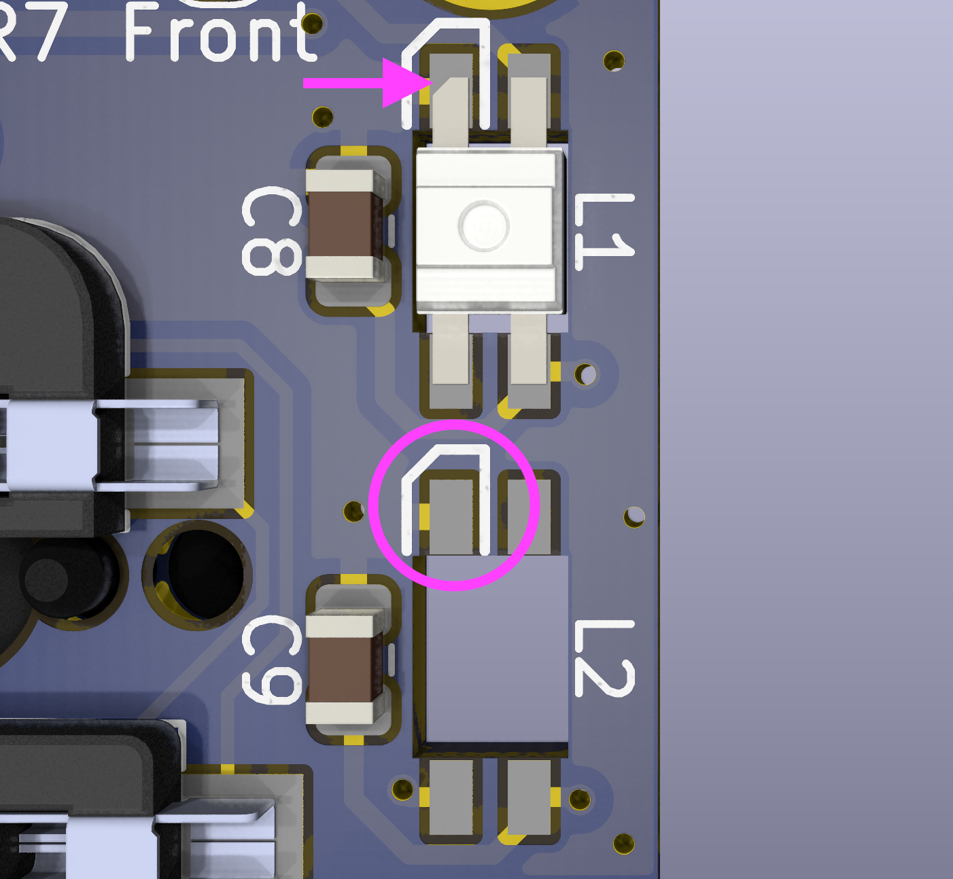
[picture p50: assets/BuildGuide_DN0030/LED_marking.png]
LED取り付けマーキング
    

    PCやMacに接続し、インジケータLED2個が白色に点灯することを確認します。

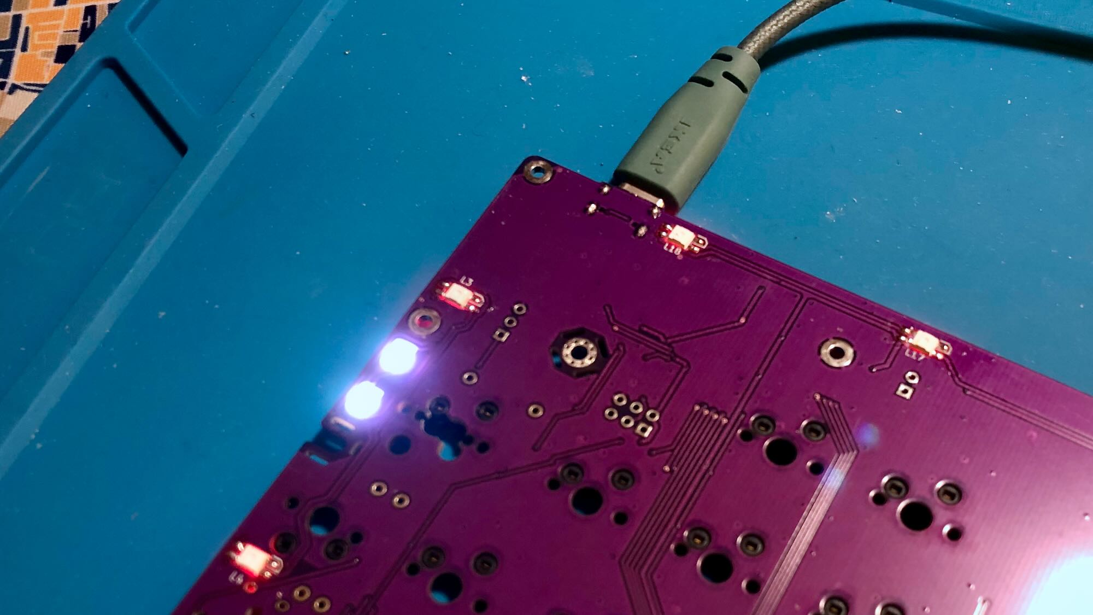
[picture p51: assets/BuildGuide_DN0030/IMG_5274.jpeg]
インジケータLED点灯確認
    

1. （該当者のみ）おもて側から、アンダーグローLEDを取り付ける（16個）

    条件：アンダーグローLEDを使用する場合

    おもて側（`L3` ... `L18`）

    LED発光部が基板うら側になるように取り付けます。

    PCやMacに接続し、アンダーグローLEDがすべて赤色に点灯することを確認します。

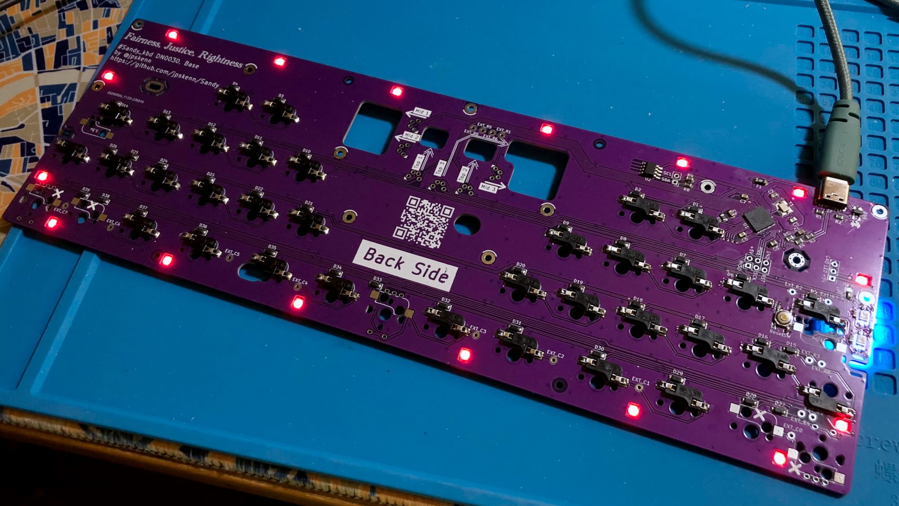
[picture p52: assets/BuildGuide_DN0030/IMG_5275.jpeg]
アンダーグローLED点灯確認
    

1. （該当者のみ）おもて側から、SHコネクタを取り付ける（6個）

    条件：通常版以外のキットを組み立てる場合

    おもて側（`J1` ... `J6`）

    基板に描かれた枠に合わせてはんだ付けします。  
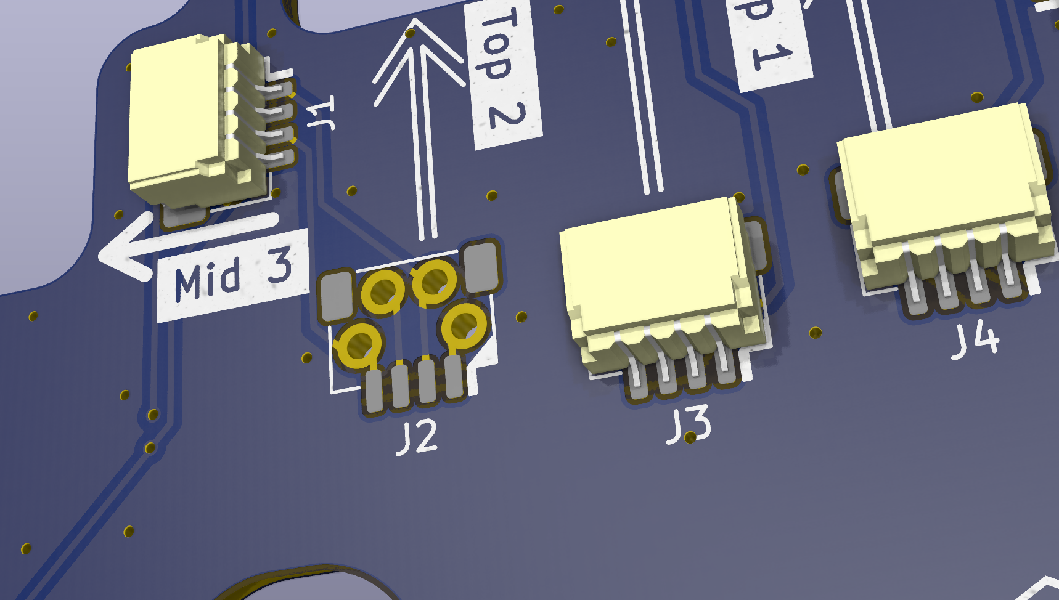
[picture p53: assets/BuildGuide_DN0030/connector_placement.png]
SHコネクタ取り付け方向
    

    まず、大きなパッドの片方だけに予備はんだしておきます。  
    コネクタの位置を基板に描かれた枠に合わせ、仮固定します。  
    正しい位置に仮固定できたら、もう片方のパッドと4本のピンをはんだ付けします。  
    隣同士の端子がはんだで繋がっていないか目視確認し、可能であれば、テスターで隣同士の端子が同通しないことも確認しておきます。  
    端子にプローブを当てるのが難しい場合は、コネクタのうら側にあるスルーホールで確認することもできます。

1. （該当者のみ）おもて側から、ロータリーエンコーダを取り付ける

    条件：ロータリーエンコーダを使用する場合

    おもて側（`RE_L2`）

    おもて側からはめ込んで、うら側からはんだ付けします。

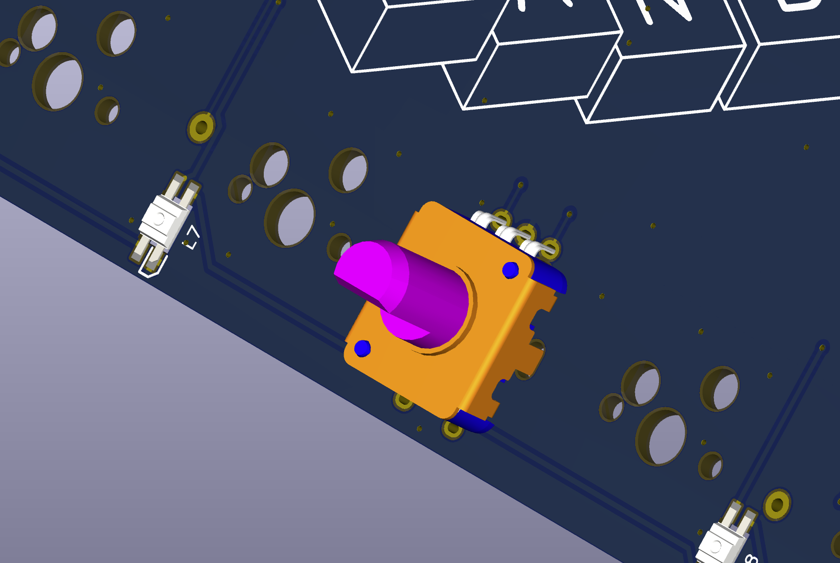
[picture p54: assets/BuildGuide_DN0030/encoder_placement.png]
ロータリーエンコーダの取り付け位置
    

### 各基板をひとつに組み合わせる

1. 基板Midのケーブルを、基板Baseのコネクタへ、方向を合わせて差し込む

    コネクタ`Mid1`, `Mid2`, `Mid3`同士を接続します。

    **ケーブルの端子側が上**になるように、方向を合わせて差し込みます。  
    💡ヒント：ケーブルを1回ひねって方向を合わせるようにします。

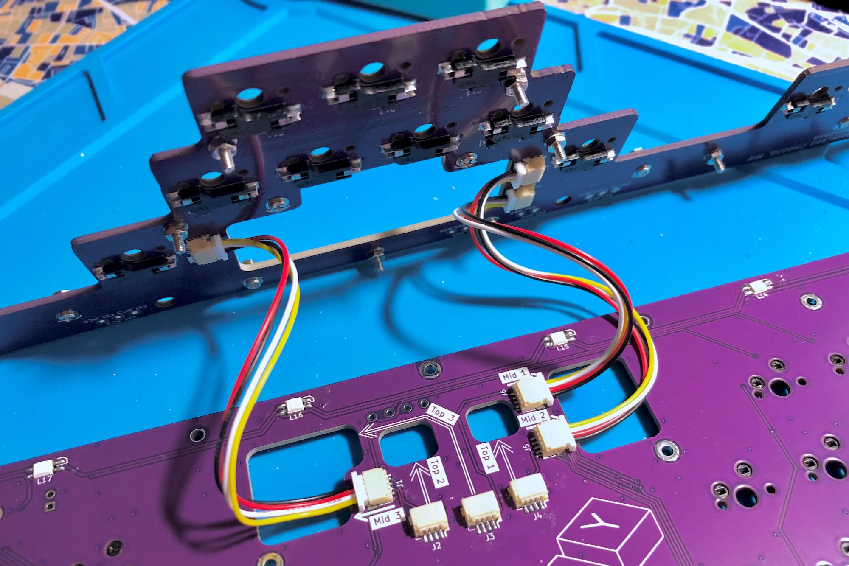
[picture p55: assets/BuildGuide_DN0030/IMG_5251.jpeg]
基板Midのケーブルを、基板Baseのコネクタへ差し込んだ様子
    

1. ケーブルを基板の隙間や、Base基板の穴からうら側へ逃しながら、基板Midを基板Baseへ乗せ、ネジ穴へはめ込む

    ケーブルを挟んだり、無理な力がかからないように注意します。

    11箇所のネジが、きっちりとネジ穴にはまっていることを確認します。

1. 基板Baseと基板Midを仮固定する（全11箇所のうち3箇所程度）

    基板Baseのうら側から、基板Midのネジをナットで止めます。  
    💡ヒント：後工程の確認作業が完了するまでは、3箇所だけ仮固定した状態で作業を進めます。

    ```text
    －－ 基板Mid －－  
    ↓  
    －－ 基板Base －－  
    ↑  
    ナット
    ```

    ケーブルを基板Baseの穴から出して逃し、3箇所だけ仮固定した様子
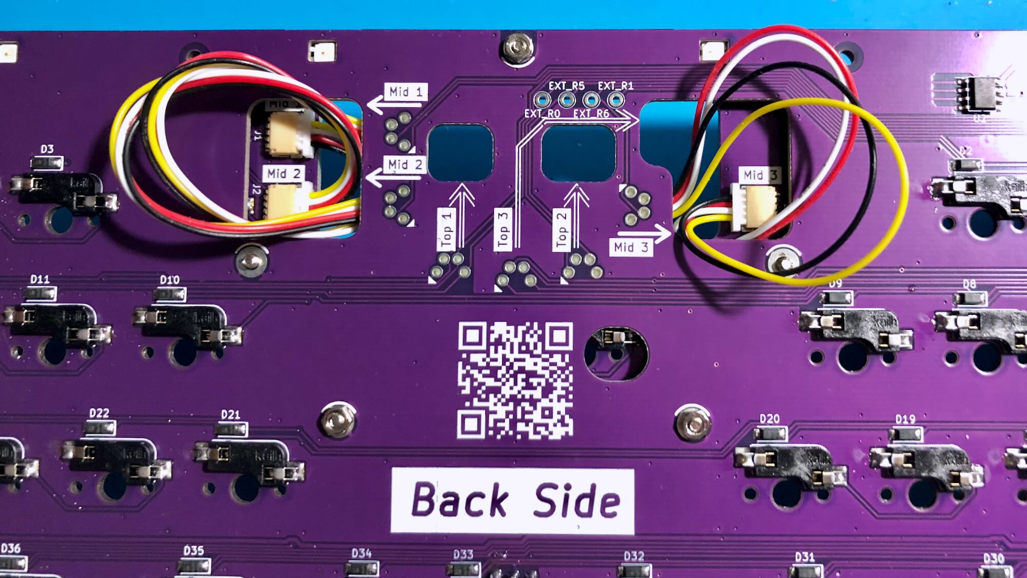
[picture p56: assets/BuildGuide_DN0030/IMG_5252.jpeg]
基板Baseと基板Midを仮固定した様子
    

1. 基板Topのケーブルを、基板Baseのコネクタへ、方向を合わせて差し込む

    コネクタ`Top1`, `Top2`, `Top3`同士を接続します。

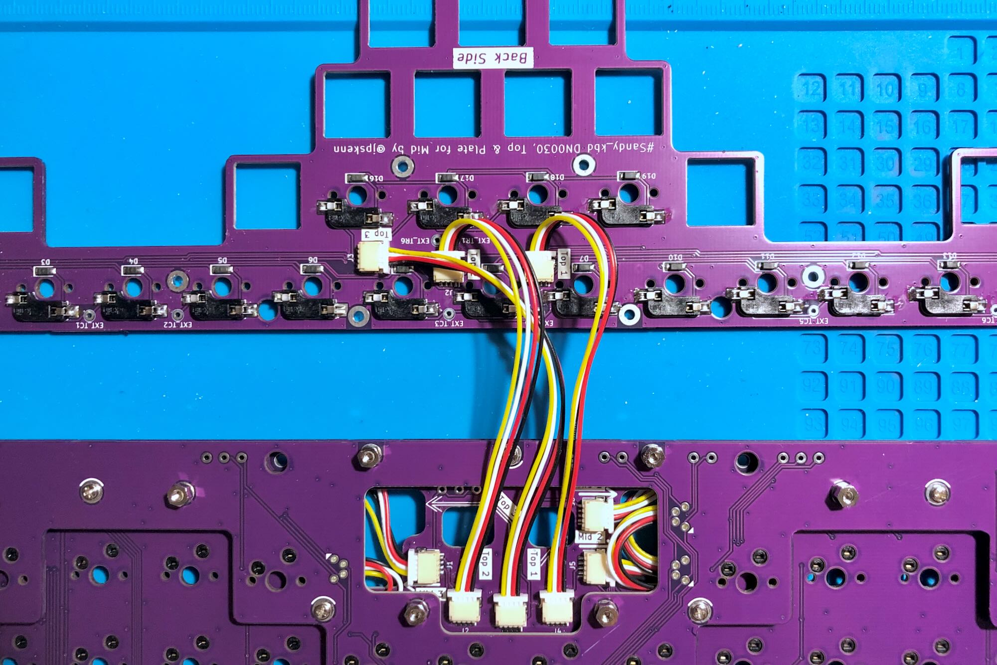
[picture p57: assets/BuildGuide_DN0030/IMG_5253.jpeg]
基板Topのケーブルを、基板Baseのコネクタへ差し込んだ様子
    

1. ケーブルを基板の隙間や基板Baseのうら側へ逃しながら、基板Topを基板Midへ乗せ、ネジ穴へはめ込む

1. 基板Topのおもて側から、基板Midを3mmネジで止める（8箇所）

    ```text
    3mmネジ  
    ↓  
    －－ 基板Top －－  
    ↑  
    －－ 基板Mid －－
    ```

    組み合わせた基板（おもて側）
    組み合わせた基板（おもて側）

    組み合わせた基板（うら側コネクタ部分）
    組み合わせた基板（うら側）

### スイッチを取り付ける

スイッチの端子が曲がっていないことを確認してから、プレートを介して基板へまっすぐ押し込んで取り付けます。  

```text
スイッチ  
↓  
－－ プレート －－  
↓  
－－ 基板 －－
```

スイッチがプレートにぴったりはまるように取り付けます。
スイッチがプレートにぴったりはまっている状態

以下の写真は、スイッチの爪でプレートが押し下げられた不正な状態です。  
プレートを指で持ち上げて、スイッチをプレートにぴったりとはめ込みます。
スイッチがプレートから浮いている

1. 基板Midのスイッチを、基板TopのMid用スイッチプレートを介して取り付ける

1. 基板Topのスイッチを、Top用スイッチプレートを介して取り付ける

1. 基板Baseのスイッチを、Base用スイッチプレートを介して取り付ける

    以下のスイッチは上下反対に取り付けます。

    - 下から2行目の左端
    - Control（左）※1.5uを使用する場合
    - Enter（右）※1.5uを使用する場合

    すべてのスイッチを取り付けた様子
    すべてのスイッチを取り付けた様子

### 動作確認をおこない、基板を完全固定する

1. Remapの”Test Matrix Mode”を使用して、すべてのキースイッチが正常に反応するか確認する

    異常がある場合は、原因を調査して修正します。

1. 基板Baseのうら側から、基板Midのすべてのネジをナットで固定する（11箇所）

### （該当者のみ）ボトムプレートへ取り付ける

条件：ボトムプレートを使用する場合

1. ボトムプレートのうら側から、スペーサーを3mmネジでとめる（8箇所）

      ```text
      スペーサー  
      ↑
      －－ ボトムプレート －－  
      ↑
      3mmネジ  
      ```

    ボトムプレートうら側ネジ止め箇所

    ボトムプレートにネジ止めしたスペーサー

1. 組み合わせた基板をボトムプレートへ乗せ、ネジ穴とスペーサーの位置を合わせる

    ケーブルをネジで挟んだり、無理な力がかからないように気をつけます。

1. 基板Baseのおもて側から、ボトムプレートを3mmネジで止める（8箇所）

    ```text
    3mmネジ  
    ↓  
    －－ 基板Base －－  
    ↑  
    －－ ボトムプレート －－
    ```

    基板Baseおもて側からボトムプレートへのネジ止め箇所

1. ボトムプレートのうら側から、ゴム足を貼り付ける。

### （該当者のみ）ケースへ取り付ける

条件：ケースを使用する場合

1. (該当者のみ)ケースを加工する

    条件：加工が必要なケースを使用する場合

    - [60% プラスチックケース](https://shop.yushakobo.jp/products/60-plastic-case)  
      ケース内側のリブのうち、他よりも高くなっている箇所をニッパーなどでカットします。  
      また、ケース奥側、内側側面の突起もカットします。

1. 組み合わせた基板を、ケースへ入れる

    基板の手前側を持ち、ケースに対して30度くらいの角度にします。  
    基板の奥の方からケースに差し込むようにし、USBコネクタをケースの穴にはめます。  
    手前側をそっと下ろします。

    右スペースのスイッチの足（5pinスイッチの固定ピンの片方）がケースネジ穴に干渉する場合は、ニッパーなどでカットします。

1. 基板Baseおもて側からネジ止めする（左側2箇所、右側2箇所）

    中央と中央右下のネジは使用しません。

    基板Baseおもて側からケースへのネジ止め箇所

### キーキャップを取り付ける

1. キーキャップを取り付ける

1. （該当者のみ）ロータリーエンコーダのノブを取り付ける

    条件：ロータリーエンコーダを使用する場合

以上で組み立て完了です。
完成

自分好みのキーマップにカスタマイズして、お使いください。

---

## カスタマイズガイド

### 部分的にキーの高さを変え、さらに3D的に最適化する

キーの物理レイアウトを、さらに3D的に最適化する方法です。

<details>
<summary>《《《 詳しい説明 》》》</summary>

一般的なMX（互換）スイッチよりも高さが3mm程度低いスイッチが販売されています。  
このようなスイッチを使用することで、部分的にキーの高さを低くすることができます。  
（逆の発想として、低いスイッチを全体的に使って、普通のスイッチを部分的に使用すれば、部分的にキーの高さを高くできます）

TECSEE使用例  
E, D, Cに低いスイッチを使用した例

製品例：

- [TECSEE Pudding ミディアムリニアスイッチ](https://talpkeyboard.net/items/63c7d52e791d021b06ee47fa)
- [TECSEE Pudding ミディアムタクタイルスイッチ](https://talpkeyboard.net/items/63e60a1134e0177ea5ea1fb4)

</details>

### 打鍵感を柔らかくする（実験的）

ボトムプレートの取り付け方法を変えて、打鍵感を柔らかくする方法を紹介します。  
まだ長期間使い込んでいないため、**実験的**な情報提供となります。

<details>
<summary>《《《 詳しい説明 》》》</summary>

通常の組み立て手順では、ボトムプレートはスペーサーとネジで基板Baseに固定します。  
あまりガチガチに固定されない位置にネジを配置していますが、場合によっては打鍵感が硬く感じられることもあるでしょう。

こういった場合、スペーサーとネジを使わず、耐震ジェルを使ってボトムプレートを取り付けると打鍵感を柔らかくすることができます。  
Base基板のうら側、ソケットの間などへ耐震ジェルを貼り付け、ボトムプレートを重ねます。

耐震ジェル貼り付け例  
耐震ジェル貼り付け例（少し貼りすぎたので、後で長いジェルを剥がしました）

耐震ジェルを貼りすぎるとプニプニ感が減って柔らかさが出にくいので、好みに合わせて調整してください。

製品例：

- [北川工業 TF-10100CL-3 タックフィット 細幅タイプ 10mm×100mm 6本入り 目安耐荷重：1本あたり7kg](https://www.yodobashi.com/product-detail/100000001007168728/)

ふと思いついたアイデアですが、今のところ実用面で特に問題もないため、情報共有します。

</details>

### キーボードの傾きを調整する

キーボードの傾きを自分に好みに合わせて調整する方法です。

<details>
<summary>《《《 詳しい説明 》》》</summary>

Sandyはそれ自体にキーの段差が組み込まれているため、キーボードの傾きを大きくつける必要がありません。  
そのため、奥側に取り付けるゴム足は低めのものを付属させています。

キーボードの傾きには個人の好みがあるので、ゴム足の高さを変えて好みの傾きに調整してください。

製品例：

- 高め：8.7mm

    [光 HIKARI KKU-190 ウレタンクッション19丸 透明](https://www.yodobashi.com/product-detail/100000001001980663/)

- ちょい高：5mm

    [光 HIKARI KKU-120 ウレタンクッション12mm角 透明](https://www.yodobashi.com/product-detail/100000001001980660/)

- キット付属品と同等：4.2mm

    [光 HIKARI KKU-122 ウレタンクッション12.8丸 透明](https://www.yodobashi.com/product/100000001001980661/)

</details>

### 基板の振動を抑える

不快な振動を感じる際の対処方法を紹介します。

<details>
<summary>《《《 詳しい説明 》》》</summary>

基板Base、基板Mid、基板Topそしてボトムプレートの4枚は、それぞれ8本または11本のスペーサーやネジでしっかりと固定されていますが、場合によっては不快な振動が発生する場合があります。<br>

このような場合は、適当な厚さのPORON（ポロン）シートを基板に貼り付けることで、振動を抑制することができます。

製品例：

- [イノアックL24-350-MT マイクロセルウレタンロールPORON 黒 3×50mm×1M巻](https://www.yodobashi.com/product/100000001004002496/)
- [イノアック L32-1.550-MT マイクロセルウレタンロールPORON 黒 1.5×50mm×1M巻](https://www.yodobashi.com/product/100000001004002516/)

</details>

## サービスマニュアル

### 初期ファームウェアの機能と設定値

出荷時に書き込まれている初期ファームウェアの機能と設定値を説明します。

<details>
<summary>《《《 詳しい説明 》》》</summary>

- QMKバージョン

  0.18.17

- キーマップ書き換えツールのRemapに対応。

- レイヤー構成とレイヤーインジケータLEDの色  
  レイヤー0から7まで、8個のレイヤーが使用できます。  
  色が`－`の箇所は、元のレイヤー色が表示されます。

    | No. | レイヤー名 | 主なキー割り当て | レイヤーインジケータLEDの色<br>上, 下 |
    | :-: | :-- | :-- | :-: |
    | 0 | ベースレイヤー #1 | SemiErgo 英語配列 | 白, 白 |
    | 1 | ベースレイヤー #2 | 一般的なロースタッガード 英語配列 | 青, 青 |
    | 2 | ベースレイヤー #3 | ↑ | 黄, 黄 |
    | 3 | Lower #1 | ファンクションキー<br>記号<br>オーディオコントロール | 緑, － |
    | 4 | Lower #2 | ↑ | 桃, － |
    | 5 | Raise #1 | ファンクションキー<br>数字<br>カーソル移動 | 水, － |
    | 6 | Raise #2 | ↑ | 橙, － |
    | 7 | Adjust | ベースレイヤー切り替え<br>LED等の設定<br>スクロールロックなど | 赤, － |
    | 番外| CapsLock | n/a | －, 紫 |

- ロータリーエンコーダ

  1個に対応。

  - 中央（RE_L2）

- アンダーグローLED

  16個のアンダーグローLEDに対応。

- その他

  - ベースレイヤーを記憶させる

    キーボードの電源を切ってもベースレイヤーが記憶されるようにするには、  
    デフォルトレイヤー切り替えのキー `DF(0)`, `DF(1)`, `DF(2)` を `Shift` と組み合わせて押します。

    例えば、`Shift + DF(1)` を押すと `ベースレイヤー #2` へ切り替わると同時に、EEPROMへその情報が保存されます。
    EEPROMへ保存されているので、キーボードの電源を切っても、次回接続した際に`ベースレイヤー #2`の状態で起動します。

  - レイヤーインジケータの表示状態を切り替える

    レイヤーインジケータの表示状態は、表示または非表示に切り替えることができます。

    表示状態を切り替えるには、`Adjust`レイヤーの`O（オー）`を押します。  
    なお、表示状態はEEPROMに保存されます。

  - レイヤーインジケータの明るさを調整する

    レイヤーインジケータの明るさは、RGB Lightingの明るさに合わせるように設定してあります。

    明るさを調整するには、  
    `Adjust`レイヤーの`L`を押してから、（一時的にRGB LightingをONにしてから、）  
    `Adjust`レイヤーの`I`と`K`で明るさを調整し、
    `Adjust`レイヤーの`L`を押します。（RGB LightingをOFFにします。）

  - アンダーグローの表示状態を切り替える

    アンダーグローの表示状態は、表示または非表示に切り替えることができます。

    表示状態を切り替えるには、`Adjust`レイヤーの`L`を押します。  
    なお、表示状態はEEPROMに保存されます。

</details>

### Sandy関連ファイル

このキーボードに関連するファイルです。  

<details>
<summary>《《《 詳しい説明 》》》</summary>

- ビルド済みファームウェア（QMKバージョン 0.22.14）： sandy_dn0030_qmk_0.22.14_via.hex  
[Sandy_DN0030_files2](https://gist.github.com/jpskenn/16a033668dabca065a8330595d4761a1)（Zipファイルをダウンロードして展開）

    2023年9月11日に更新されたRemap（QMKバージョン 0.22.2以降版）に対応するファームウェアです。  
    機能的な変更はありません。

- ビルド済みファームウェア（QMKバージョン 0.18.17）： sandy_dn0030_via.hex  
[Sandy_DN0030_files](https://gist.github.com/jpskenn/916b2abc9b1252dcd62130175d11db3e)（Zipファイルをダウンロードして展開）

    出荷時に書き込み済みのファームウェアです。  
    [Remap for QMK Firmware 0.18.17 or lower](https://qmk018.remap-keys.app)で、キーの割り当てを変更することができます。  
    ロータリーエンコーダへのキー割り当てをおこなうには、Remapで定義ファイル`sandy_v01_via.json`をインポートしてください。

- ファームウェアのソース

    私がQMKからフォークしたリポジトリ[https://github.com/jpskenn/qmk_firmware](https://github.com/jpskenn/qmk_firmware)の、[develop_Sandy](https://github.com/jpskenn/qmk_firmware/tree/develop_Sandy)ブランチ内、`keyboards/sandy/dn0030`に配置しています。  

    このブランチは、QMKバージョン 0.18.17から派生し、後にQMKバージョン 0.22.14をマージしています。

  - Tags
    - [Sandy_QMK_0.22.14](https://github.com/jpskenn/qmk_firmware/releases/tag/Sandy_QMK_0.22.14)
    - [Sandy_QMK_0.18](https://github.com/jpskenn/qmk_firmware/releases/tag/Sandy_QMK_0.18)

- 基板等の設計ファイルやドキュメント、Remapの定義ファイルなどは、[Sandyリポジトリ](https://github.com/jpskenn/Sandy)の[DN0030タグ](https://github.com/jpskenn/Sandy/releases/tag/DN0030)にまとめてあります。

</details>

### QMK Toolboxを使用して、ファームウェアを書き込む方法

[QMK Toolbox](https://github.com/qmk/qmk_toolbox/releases)を使用してビルド済み（＝作成済み）のファームウェアを書き込む方法について説明します。  

<details>
<summary>《《《 詳しい説明 》》》</summary>

（確認したQMK Toolboxのバージョン： 0.2.1）

**ファームウェアを書き込んだ後に初めてRemapに接続した際、キーボードレイアウト画面が表示されるまで30秒〜1分ほどかかる場合があります。**  
EEPROMの初期化処理がおこなわれていますので、キーボードの準備が整うまでしばらくお待ちください。  
2回目以降の接続では、すぐに接続されます。

QMKファームウェアのドキュメント”[ファームウェアを書き込む](https://docs.qmk.fm/#/ja/newbs_flashing?id=ファームウェアを書き込む)”も、あわせてご覧ください。

1. [資料：Sandy関連ファイル](#資料sandy関連ファイル)に記載のダウンロード先から、ビルド済みのファームウェアをダウンロードします。

1. [QMK Toolbox](https://github.com/qmk/qmk_toolbox/releases)をダウンロードし、起動します。

1. `Open`ボタンを押し、QMK Toolboxで、ダウンロードしておいたファームウェアを開きます。

1. `Sandy`キーボードをDFU (Bootloader)モードにします。
    1. USBケーブルが接続されている場合は、ケーブルを抜きます。
    1. キーボードの**左上**のキー（`ESC`や`\``）を押したまま、USBケーブルを差し込みます。

1. QMK Toolboxの画面に、以下のような接続メッセージが表示されます。  
    （もし表示されない場合は、USBケーブルを接続した状態で、基板うら側のリセットボタンを押します）

    ```text
    *** Atmel DFU device connected: ATMEL ATm32U4DFU (03EB:2FF4:0000)
    ```

1. QMK Toolboxの`Flash`ボタンを押すとファームウェアの書き込みが始まります。  
    5秒程度で書き込みが終わり、QMK Toolboxの画面に以下のような書き込み完了メッセージが表示されます。（サイズ表記などの、細かい部分は実際とは異なります）

    ```text
    *** Attempting to flash, please don't remove device
    >>> dfu-programmer atmega32u4 erase --force
        Erasing flash...  Success
        Checking memory from 0x0 to 0x6FFF...  Empty.
    >>> dfu-programmer atmega32u4 flash --force /Users/jpskenn/qmk_firmware/nora_v01_via.hex
        0%                            100%  Programming 0x5E80 bytes...
        [>>>>>>>>>>>>>>>>>>>>>>>>>>>>>>>>]  Success
        0%                            100%  Reading 0x7000 bytes...
        [>>>>>>>>>>>>>>>>>>>>>>>>>>>>>>>>]  Success
        Validating...  Success
        0x5E80 bytes written into 0x7000 bytes memory (84.38%).
    >>> dfu-programmer atmega32u4 reset
    *** Atmel DFU device disconnected: ATMEL ATm32U4DFU (03EB:2FF4:0000)
    ```

    書き込み完了メッセージが表示されたら、QMK Toolboxを終了してもかまいません。  

    これとは違うメッセージ（書き込み失敗など）が表示された場合は、スクリーンショットを撮ったり、メッセージをコピーしておくと、何らかのサポートを受ける場合にスムースに話が進みます。

1. 書き込みが終わってから30秒程度でキーボードが起動し、キー入力できるようになります。  
  ファームウェアを書き込んだ後、初回起動時に外部EEPROMの消去をおこなっています。  
  この消去処理にしばらく時間がかかっています。

1. リセットボタンを使ってDFUモードにする操作をおこなった場合は、[資料：EEPROMを消去して、初期状態に戻す方法](#資料eepromを消去して初期状態に戻す方法)をおこないます。

以上でQMK Toolboxを使用したファームウェアの書き込み作業は完了です。

</details>

### EEPROMを消去して初期状態に戻す方法

EEPROMに記録されているデータを消去し、初期状態に戻す方法について説明します。  

<details>
<summary>《《《 詳しい説明 》》》</summary>

キーマップやLEDの表示モードなどのEEPROMに記録されているデータを消去し、初期状態に戻すことができます。  

また、古いデータが残って動作がおかしくなるのを防止するため、リセットボタンを使用してファームウェアを書き込んだ際にもこの操作をおこないます。

1. USBケーブルを接続している場合は、ケーブルを抜きます。

1. キーボードの左上のキーを押したまま、USBケーブルを差し込みます。

1. ケーブルを差し込んで、1、2と数えてから、USBケーブルを抜きます。

1. USBケーブルを差し込みます。

1. 10秒ほど待つとキーボードが起動します。

以上でEEPROMが消去され、初期状態に戻ります。

</details>

### 基板準備作業メモ

基板の出荷準備作業に関するメモです。

<details>
<summary>《《《 詳しい説明 》》》</summary>

#### パーツリスト

| 部品名 | 個数 | 備考 |
| :---- | :-----: | :---- |
| USBコネクタ<br>TYPE-C-31-M-12 | 1 | |
| ESD<br>PRTR5V0U2X | 1 | 取り付け方向は基板の印を参照 |
| FUSE<br>0ZCJ0050AF2E | 1 ||
| リセットスイッチ<br>RS-187R05A2-DSMTRT | 1 ||
| SHコネクタ<br>JST SH ベース サイド型 4pin 面実装<br>[SM04B-SRSS-TB(LF)(SN)](https://www.lcsc.com/product-detail/_JST-Sales-America-_C160404.html) | 6 ||
| SH 4pin ケーブル| 1 | |

#### 基板セットアップ

1. 基板Top：`J3（Top3）`へSH 4pin ケーブルを1本取り付ける

  初期ロット（DN0030）のみ。

1. 基板Base：SMTAしていない部品を取り付ける

    1. 基板うら側`J7`へUSBコネクタを取り付ける

        テスターで各ピンがショートしていないことを確認する。

        USBコネクタ接続図（TYPE-C-31-M-12）  
        USBコネクタ接続図（TYPE-C-31-M-12）

    1. 基板うら側`D99`へESDを取り付ける

        基板に描かれた取り付け方向を参照

    1. 基板うら側`F1`へFUSEを取り付ける

        方向なし

    1. 基板うら側`ResetSW`へリセットスイッチを取り付ける

        方向なし

    1. 基板うら側`JP1`を、`Front`側にジャンパする。

        - `Front`
            インジケータ（2個）→アンダーグロー（16個）のLED配線。  
        - `Under`
            アンダーグロー（16個）のみのLED配線。

    1. 基板おもて側`J1`...`J6`へコネクタを取り付ける

        テスターで隣同士の端子がショートしていないか確認する。

1. ファームウェアを書き込む

    1. QMK Toolboxを起動して、書き込むファームウェアを開く

    1. 基板をPC/Macへ接続

        QMK Toolboxに、デバイスの接続メッセージが表示されることを確認。

    1. 基板のリセットスイッチを押す（リセットスイッチの動作確認も兼ねる）

        QMK Toolboxに、デバイスの切断と接続のメッセージが表示されることを確認。

    1. QMK Toolboxの`Flash`ボタンを押して書き込む

    1. Remapを開いて接続

        → EEPROMの初期化に1分ほどかかる

    1. Remapでスイッチソケットのパッドの反応を確認する

</details>

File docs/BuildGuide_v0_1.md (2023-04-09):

# Sandy v.0.1 ビルドガイド

このドキュメントは、Sandy v.0.1を組み立てるためのビルドガイドです。  
Sandyのコンセプトや特徴、ビルド例などについては、こちらの[README](/README.md)をご覧ください。

ビルドガイド全体に目を通して作業手順を把握しておくとミスの防止につながりますので、ぜひ、一度お読みになってから組み立て作業を始めてください。

作業手順をしっかりと確認しながら組み立てたい方は、

<details>
<summary>《《《 詳しい説明 》》》</summary>

ここに追加の説明を表示します。
</details>

と書かれたところをクリックすると、追加の説明が表示されます。

---

## 目次

<!-- @import "[TOC]" {cmd="toc" depthFrom=2 depthTo=2 orderedList=false} -->

<!-- code_chunk_output -->

- [目次](#目次)
- [注意事項や制限など](#注意事項や制限など)
- [部品リスト](#部品リスト)
- [組み立てに使用する工具](#組み立てに使用する工具)
- [組み立て前の確認](#組み立て前の確認)
- [組み立て手順](#組み立て手順)
- [参考資料](#参考資料)
- [サービスマニュアル](#サービスマニュアル)

<!-- /code_chunk_output -->

---

## 注意事項や制限など

- 試作版

  Sandy v.0.1は試作版です。  
  とりあえずの動作確認とキーボードとして使用できることは確認していますが、長期にわたる使用など、何が起きるかわからないところがあります。

- 組み立て難易度

  JST SHコネクタのはんだ付けが難しいです。  
  端子間が狭くはんだがブリッジしやすく、またパーツが小さいため目視で確認しずらいため、テスターがあると安心です。  

  また、基板同士をQwiicケーブルで接続して重ねる作業は、少し神経をつかいます。

- スイッチの取り付け

  ソケットを使用せず、基板に直接はんだ付けして取り付けます。

- GH60型，Poker型のケースへの取り付け

  - 中央、中央下のネジを使用せず、左右2本ずつ合計4本のネジだけで取り付けます。

  - ケース内部の構造によっては、取り付けに加工が必要になることがあります。
    また、場合によっては取り付けできないことがるかもしれません。

    TOFUケースへ取り付けできることを確認済みです。

- 5方向スイッチ（JS5208）の取り付け

  固定足のうち1本をニッパーなどでカットして取り付けます。

## 部品リスト

このキットを組み立てるためには、[キット内容](#キット内容)に加え、[別途用意が必要な部品](#別途用意が必要な部品)が必要です。  
好みに合わせて必要な数をお買い求めください。

[オプション部品](#オプション部品)は、使いたい機能などに応じて用意してください。  

### キット内容

| 部品名 | 個数 | 備考 |
| :-- | --: | :-- |
| ご案内リーフレット | なし | |
| 基板 Base | 1 | Baseのみ部品実装済み |
| 基板 Mid | 1 | |
| 基板 Top | 1 | |
| ダイオード<br>表面実装（SMD）タイプ, 1N4148W | 40 | 予備3個含む<br>[高速スイッチング・ダイオード　１Ｎ４１４８Ｗ](https://akizukidenshi.com/catalog/g/gI-07084/) |
| コネクタ<br>JST SH ベース サイド型 4pin 面実装 | 13 | 互換品。予備1個含む<br>[HR(Joint Tech Elec) A1001WR-S-04P](https://www.lcsc.com/product-detail/_HR-Joint-Tech-Elec-_C371510.html) |
| Qwiicケーブル<br>JST SH 4pin, 長さ5cm | 6 | - [PRT-17260](https://www.digikey.jp/ja/products/detail/sparkfun-electronics/PRT-17260/13629028)<br>- [Qwiicケーブル（Qwiic -Qwiic）50 mm](https://www.switch-science.com/products/6896?_pos=1&_sid=bc641ada5&_ss=r)<br>- [SparkFun　PRT-17260 Qwiicケーブル (50mm)](https://www.sengoku.co.jp/mod/sgk_cart/detail.php?code=EEHD-5ZMM) |
| スペーサー<br>丸型または六角 両メネジ, M2 3mm | 8 | [ヒロスギ ARB-2003E](https://hirosugi.co.jp/products/B/ARB-E.html#bx3) |
| 六角ナット<br>M2 2種 | 22 | [ウィルコ FNT-02N-2](https://wilco.jp/products/F/FNT-N-2.html) |
| ワッシャー<br>内径2.3mm 外径4.3mm 厚さ0.4mm | 11 | [ウィルコ FW-0204-04N](https://wilco.jp/products/F/FW-N.html#page3) |
| ネジ<br>M2 3mm | 16 | [ウィルコ F-0230N-03](https://wilco.jp/products/F/F-N-02.html#page3) |
| ネジ<br>M2 4mm | 4 | [(+)スリムヘッド小ねじ(鉄/ニッケル)(小箱) ](https://www.monotaro.com/p/4230/6074/) |
| ネジ<br>M2 7mm | 11 |  [ウィルコ F-0270N-03](https://wilco.jp/products/F/F-N-02.html#page3) |
| LED<br>SK6812MINI | 4 | [マイコン内蔵ＲＧＢＬＥＤ　ＳＫ６８１２ＭＩＮＩ](https://akizukidenshi.com/catalog/g/gI-15477/) |
| 5方向スイッチ, JS5208 | 1 | [JS5208](https://www.lcsc.com/product-detail/_E-Switch-_C3029619.html) <br>上下左右と押し込みの5方向。<br>上下左右はグニグニ動きますが、倒し切って「カチッ」というタクタイル感があるところがアクチュエーションポイントです。 |
| 5方向スイッチ用ノブ（つまみ）<br>※お試し用 | 1 | [タクトスイッチキャップ（10個入） [PLSA11CP]](https://www.aitendo.com/product/9731)<br>ちょっと奥まではまりすぎるのでお試し用。（穴にティッシュでもつめて高さを調整してください）<br>3.3mm角の軸に対応するものであれば、旧機種用のトラックポイントキャップなども使えます。 |

※出荷時期によって、基板等の仕様や、部品のメーカーや品番などを変更することがあります。

3枚の基板
3枚の基板

### 別途用意が必要な部品

| 部品名 | 個数 | 備考 |
| :-- | :-- | :-- |
| PCBマウント スタビライザー<br>2uサイズ | 0 〜 3 | 組み立てるレイアウトにより使用数が変わります。 |
| MXスイッチ | 67 〜 71 | 組み立てるレイアウトにより使用数が変動します。<br>取り付け安定性の高い5pinタイプを推奨。 |
| キーキャップ<br>MXスイッチ用 | 必要数 | 一般的な英語104のキーキャップセットで一通り埋めることができます。<br>40%や全部入りのキーキャップセットなど、1.5uエンターや1.5uバックスペースがあると雰囲気が良くなります。<br>2uや1.5uのスペースは、DSAなどを使用するのも良いでしょう。<br>参考： [Sandyのレイアウト](http://www.keyboard-layout-editor.com/#/gists/1d0f4082c7ae670692987e3519c82648) |
| GH60型, Poker型ケース<br>または<br>Jones／Nora用ボトムプレートキット | 1 | |
| USBケーブル （Type-C） | 1 | |

### オプション部品

| 部品名 | 個数 | 備考 |
| :-- | :-- | :-- |
| ロータリーエンコーダ, ALPS EC11, EC12または同等品 | 最大 2 | プッシュスイッチ付きにも対応 |
| ロータリーエンコーダ用ノブ（つまみ） | 必要数 | |

## 組み立てに使用する工具

- 必要な工具

  - 先の細いプラスドライバー（M2ネジに対応するもの。+0）

  - はんだ付け関連用品

  - ピンセット

  - ニッパーやカッターなど（5方向スイッチを取り付ける場合）

- あると便利な工具

  - M2ナット対応の十字レンチ

    ナットを締めるのが楽になります。  
    [タミヤ SP.38 工具セット](https://www.tamiya.com/japan/products/50038/index.html)の十字レンチがM2ナットに対応しています。

  - フラックスやハンダ吸い取り線

    はんだ付けの、ちょっとした修正や部品の取り外しなどがしやすくなります。

  - テスター

    はんだ付けの難易度が高くミスが起こりがちなので、何か不具合があった場合の原因調査で活躍します。

## 組み立て前の確認

1. 基板Baseを、USBケーブルでPCやMacに接続します。

1. PCやMacで認識されていることを確認します。

    - Windows  
      設定 → キーボードに”Sandy”が表示されていること

    - Mac  
      システムレポート → USBに”Sandy”が表示されていること

1. [Remap](https://remap-keys.app/)を開いて、キーボード”Sandy”を接続します。  

1. Remapの”Test Matrix Mode”を開きます。

1. 基板Baseのスイッチ取り付け穴をピンセットなどでショートさせ、画面上のキーの色が青に変わることを確認します。  
  （発送前に、基板Baseが正常であることを、Remapで確認しています）

確認作業に問題がある場合は [@jpskenn](https://twitter.com/jpskenn/) へ連絡してください。

## 組み立て手順

以降の手順に沿って組み立てます。  
`（オプション）`の手順は、不要であれば作業をとばしてもかまいせん。  
`（該当者のみ）`の手順は、条件に該当する場合のみ作業をおこないます。

### 組み立てるレイアウトを決める

以下のポイントを念頭に、組み立てるレイアウトを決めます。

- キーのサイズ  
  \*印のキーは英語104キーキャップセットに対応する組み合わせ

  - 左Shift：2u(\*) / 1.75u / 1u + 1u

  - 左Control：1.25u(\*) / 1.5u

  - Enter：1.25u(\*) / 1.5u

  - 最下行中央：  

    4キー(\*)：2u + 1u + 1u +2u  
    5キー：1.5u + 1u + 1u + 1u + 1.5u

- ロータリーエンコーダの有無と場所

  最大2個まで取り付けできます。

  - 左側グループ（RE_L1, RE_L2, RE_L3）のうち、いずれかひとつ

  - 右側グループ（RE_R1, RE_R2）のうち、どちらかひとつ

- 5方向スイッチの有無

参考： [Sandyのレイアウト](http://www.keyboard-layout-editor.com/#/gists/1d0f4082c7ae670692987e3519c82648)

### 基板Topの準備

1. 基板側面をマジックで塗る

1. JST SHコネクタを取り付ける（3個）

    うら側（`J1`, `J2`, `J3`）

    端子部分、はんだブリッジに注意。  
    可能なら、はんだ付け後に、コネクタ裏のスルーホールがを隣同士で同通しないことをテスターで確認します。

1. ダイオードを取り付ける（19個）

    うら側

1. スイッチを取り付ける

    おもて側からはめ込んで、うら側からはんだ付けします。

1. 基板Topのコネクタへ、ケーブルを差し込む（3本）

    ケーブルを差し込む方向を確認してから、基板からコネクタがもげないように手を添えつつ作業します。

### 基板Midの準備

1. 基板側面をマジックで塗る

1. （該当者のみ）LEDディフューザーのタブを切り取る

    *条件：基板Baseと基板Midの間隔を3.4mm以上にする場合。*

    LEDディフューザーとキーキャップが干渉しないよう、基板からLEDディフューザーのタブを切り取ります。  
    手でパキッと折ったりニッパーを使ったりして切り取り、切り取った箇所をやすりなどで滑らかにします。

1. JST SHコネクタを取り付ける（3個）

    うら側（`J1`, `J2`, `J3`）

    端子部分、はんだブリッジに注意。  
    可能なら、はんだ付け後に、コネクタ裏のスルーホールがを隣同士で同通しないことをテスターで確認します。

1. ダイオードを取り付ける（18個）

    うら側

1. （オプション）5方向スイッチを取り付ける

    5方向スイッチの小さい足2本のうち、横に2個細長い出っ張りのある側の1本を切り取ります。

    5方向スイッチのカットする足  
    5方向スイッチのカットする足

    おもて側からはめ込んで、うら側からはんだ付けします。

1. スイッチを取り付ける

    おもて側からはめ込んで、うら側からはんだ付けします。  
    組み立てるレイアウトにより、一部の取り付け位置が変わります。

1. 基板Midのおもて側から、ワッシャーを挟んだナットを7mmネジでとめる（11箇所）

    ```text
    7mmネジ  
    ↓  
    ーー 基板Mid ーー  
    ↓  
    ワッシャー  
    ↓  
    ナット
    ```

    基板Midおもて側ネジ止め箇所

1. 基板Midのうら側から、スペーサーを3mmネジでとめる（8箇所）

      ```text
      スペーサー  
      ↑
      ーー 基板Mid ーー  
      ↑
      7mmネジ  
      ```

    基板Midうら側ネジ止め箇所

1. 基板Midのコネクタへ、ケーブルを差し込む（3本）

    ケーブルを差し込む方向を確認してから、基板からコネクタがもげないように手を添えつつ作業します。

### 基板Baseの準備

1. 基板側面をマジックで塗る

1. （オプション）インジケータLEDを取り付ける

    おもて側へ、左に2個、右に2個のLEDを取り付けます。（`LED1`, `LED2`, `LED3`, `LED4`）  
    基板のマークに、LEDの切り欠きを合わせます。

    LED取り付け方向マーク  

    LED取り付け例

    ```text
    💡LEDの点灯パターンについてのヒント

    キーボードのファームウェアの機能により、  
    左, 右, 両方, 消灯
    の点灯パターンに切り替えることができます。
    ```

    参考：[資料：初期ファームウェアの機能と設定値](#資料初期ファームウェアの機能と設定値)

1. JST SHコネクタを取り付ける（6個）

    おもて側（`J6`, `J7`, `J8`, `J9`, `J10`, `J15`）

    端子部分、はんだブリッジに注意。  
    可能なら、はんだ付け後に、コネクタ裏のスルーホールがを隣同士で同通しないことをテスターで確認します。

1. （オプション）ロータリーエンコーダを取り付ける

    最大2個まで取り付けできます。

    - 左側グループ（RE_L1, RE_L2, RE_L3）のうち、いずれかひとつ

    - 右側グループ（RE_R1, RE_R2）のうち、どちらかひとつ

    おもて側からはめ込んで、うら側からはんだ付けします。  

1. （該当者のみ）スタビライザーを取り付ける

    *条件：2uキーにスタビライザーを使用する場合*

    おもて側から、レイアウトに応じた場所へ取り付けます。  
    大きい方の穴へスタビライザーの突起を引っ掛け、小さい方の穴へパチンとはめます。  

1. スイッチを取り付ける

    おもて側からはめ込んで、うら側からはんだ付けします。  
    組み立てるレイアウトにより、一部の取り付け位置が変わります。

    レイアウトのバリエーションがある箇所は、5pinスイッチの固定ピンがしっかりと固定されない場合があります。  
    はんだ付け時に傾かないよう、注意してください。

### 各基板をひとつに組み合わせる

1. 基板Midを基板Baseへ乗せ、ネジ穴へはめ込む

1. 基板Baseのうら側から、基板Midのネジをナットで仮止めする

    （全11箇所のうち、3箇所くらい）

    ```text
    －－ 基板Mid －－  
    ↓  
    －－ 基板Base －－  
    ↑  
    ナット
    ```

1. 基板Midのケーブルを、基板Baseのコネクタへ差し込む

    ケーブルを差し込む方向を確認してから、基板からコネクタがもげないように手を添えつつ作業します。

1. ケーブルを基板と基板の隙間へ逃す（押し込む）

1. 基板Topのケーブルを、基板Midの穴を通しつつ、基板Baseのコネクタへ差し込む

    ケーブルを差し込む方向を確認してから、基板からコネクタがもげないように手を添えつつ作業します。

1. ケーブルを基板と基板の隙間へ逃しつつ、基板Topを基板Midへ乗せる

    基板を組み合わせるようす  
    基板を組み合わせるようす

1. 基板Topのおもて側から、基板Midを3mmネジで仮止めする

    （全8箇所のうち、3箇所くらい）

    ```text
    3mmネジ  
    ↓  
    －－ 基板Top －－  
    ↑  
    －－ 基板Mid －－
    ```

### 動作確認と基板の完全固定

1. Remapの”Test Matrix Mode”を使用して、すべてのキーが正常に反応するか確認する

1. 動作確認できたら、基板Base→Mid、基板Top→Midのすべてのネジを固定する

### ケースへ取り付け

1. ケースまたは専用ボトムプレートへ取り付ける

1. キーキャップを取り付ける

## 参考資料

### 基板間隔

基板間隔の目安について説明します。

なお、最終的なキーの段差は、以下のようになります。

```text
キーの段差 ＝ 基板間隔 ＋ 基板の厚さ ＋ キーキャッププロファイルの高低差
```

- 基板間隔の最小値

  基板間隔の最小値は、スイッチの端子が基板からはみ出す量（1.7mm）と組み立て作業のしやすさを考慮し、以下のようにしています。

  - 基板Baseから基板Mid：2mm
  - 基板Midから基板Top：3mm

  スイッチの端子をカットすることで、1.6mm程度（ワッシャーなしのナットだけ）まで狭めることができますが、2mmと大差ないため、無理してやる価値はないように思います。

  また、基板Midと基板Topの間隔2mmした場合、スイッチの隙間に工具が入らないため、ナットで止める作業が困難になります。

- 基板間隔の最大値

  Qwiicケーブルの長さや組み立て時の安定性が確保できれば、長いスペーサーを使ってさらに間隔を広げられます。
  
  3ヶ月ほどテスト機を使用し、実用面では3mm程度が最適と感じています。

### 資料：初期ファームウェアの機能と設定値

出荷時に書き込まれている初期ファームウェアの機能と設定値を説明します。

- QMKバージョン

  0.18.17

- キーマップ書き換えツールのRemapやVIAに対応。

- レイヤー構成とレイヤーインジケータLEDの色  
  レイヤー0から7まで、8個のレイヤーが使用できます。  
  色が`－`の箇所は、元のレイヤー色が表示されます。

    | No. | レイヤー名 | 主なキー割り当て | レイヤーインジケータLEDの色<br>上, 下 |
    | :-: | :-- | :-- | :-: |
    | 0 | ベースレイヤー #1 | 英語配列 | 白, 白 |
    | 1 | ベースレイヤー #2 | ↑ | 青, 青 |
    | 2 | ベースレイヤー #3 | ↑ | 黄, 黄 |
    | 3 | Lower #1 | ファンクションキー<br>記号<br>オーディオコントロール | 緑, － |
    | 4 | Lower #2 | ↑ | 桃, － |
    | 5 | Raise #1 | ファンクションキー<br>数字<br>カーソル移動 | 水, － |
    | 6 | Raise #2 | ↑ | 橙, － |
    | 7 | Adjust | ベースレイヤー切り替え<br>LED等の設定<br>スクロールロックなど | 赤, － |
    | 番外| CapsLock | n/a | －, 紫 |

- ロータリーエンコーダ

  最大2個に対応。

  - 左側グループ（RE_L1, RE_L2, RE_L3）のいずれかひとつ

  - 右側グループ（RE_R1, RE_R2）のどちらかひとつ

- その他

  - ベースレイヤーを記憶させる

    キーボードの電源を切ってもベースレイヤーが記憶されるようにするには、  
    デフォルトレイヤー切り替えのキー `DF(0)`, `DF(1)`, `DF(2)` を `Shift` と組み合わせて押します。

    例えば、`Shift + DF(1)` を押すと `ベースレイヤー #2` へ切り替わると同時に、EEPROMへその情報が保存されます。
    EEPROMへ保存されているので、キーボードの電源を切っても、次回接続した際に`ベースレイヤー #2`の状態で起動します。

  - レイヤーインジケータの表示状態を切り替える

    レイヤーインジケータの表示状態を、  
    `左` → `右` → `左右両方` → `消灯` …  
    へ切り替えるには、`Adjust`レイヤーの`O（オー）`を押します。  
    なお、表示状態はEEPROMに記憶されます。

  - レイヤーインジケータの明るさを調整する

    レイヤーインジケータの明るさを、RGB Lightingの明るさに合わせるように設定してあります。

    明るさを調整するには、  
    `Adjust`レイヤーの`L`を押してから、（一時的にRGB LightingをONにしてから、）  
    `Adjust`レイヤーの`I`と`K`で明るさを調整し、
    `Adjust`レイヤーの`L`を押します。（RGB LightingをOFFにします。）

### 資料：Sandy関連ファイル

このキーボードに関連するファイルです。  

- ビルド済みファームウェア： sandy_v01_via.hex  
  [Sandy v01 files (20230328)](https://gist.github.com/jpskenn/21b21c53d0633dc71cbee85959485c7a)（Zipファイルをダウンロードして展開）

- ファームウェアのソース  
  私がQMKからフォークしたリポジトリ [https://github.com/jpskenn/qmk_firmware](https://github.com/jpskenn/qmk_firmware)の、[develop_Sandy](https://github.com/jpskenn/qmk_firmware/tree/develop_Sandy)ブランチ内、`keyboards/sandy/v01`に配置しています。  
  Sandy v.0.1のファームウェアは、[Sandy_v01タグ](https://github.com/jpskenn/qmk_firmware/releases/tag/Sandy_v01)を参照してください。

- 基板等の設計ファイルやドキュメント、Remap/VIAの定義ファイルなどは、[Sandyリポジトリ](https://github.com/jpskenn/Sandy)の[v01タグ](https://github.com/jpskenn/Sandy/releases/tag/v01)にまとめてあります。

### 資料：QMK Toolboxを使用して、ファームウェアを書き込む方法

[QMK Toolbox](https://github.com/qmk/qmk_toolbox/releases)を使用してビルド済み（＝作成済み）のファームウェアを書き込む方法について説明します。

よくわかっている方は、
`make sandy:via:flash`
のコマンドで、ファームウェアをビルドして書き込む方法でかまいません。

<details>
<summary>《《《 詳しい説明 》》》</summary>

**ファームウェアを書き込んだ後に初めてRemapに接続した際、キーボードレイアウト画面が表示されるまで30秒〜1分ほどかかる場合があります。**  
EEPROMの初期化処理がおこなわれていますので、キーボードの準備が整うまでしばらくお待ちください。  
2回目以降の接続では、すぐに接続されます。

QMKファームウェアのドキュメント[ファームウェアを書き込む](https://docs.qmk.fm/#/ja/newbs_flashing?id=ファームウェアを書き込む)も、あわせてご覧ください。

1. [資料：Sandy関連ファイル](#資料sandy関連ファイル)に記載のダウンロード先から、ビルド済みのファームウェアをダウンロードします。

1. [QMK Toolbox](https://github.com/qmk/qmk_toolbox/releases)をダウンロードし、起動します。

1. `Open`ボタンを押し、QMK Toolboxで、ダウンロードしておいたファームウェアを開きます。

1. `Sandy`キーボードをDFU (Bootloader)モードにします。
    1. USBケーブルが接続されている場合は、ケーブルを抜きます。
    1. キーボードの**左上**のキー（`ESC`や`\``）を押したまま、USBケーブルを差し込みます。

1. QMK Toolboxの画面に、以下のような接続メッセージが表示されます。  
    （もし表示されない場合は、USBケーブルを接続した状態で、基板裏側のリセットボタンを押します）

    ```text
    *** Atmel DFU device connected: ATMEL ATm32U4DFU (03EB:2FF4:0000)
    ```

1. QMK Toolboxの`Flash`ボタンを押すとファームウェアの書き込みが始まります。  
    5秒程度で書き込みが終わり、QMK Toolboxの画面に以下のような書き込み完了メッセージが表示されます。（サイズ表記などの、細かい部分は実際とは異なります）

    ```text
    *** Attempting to flash, please don't remove device
    >>> dfu-programmer atmega32u4 erase --force
        Erasing flash...  Success
        Checking memory from 0x0 to 0x6FFF...  Empty.
    >>> dfu-programmer atmega32u4 flash --force /Users/jpskenn/qmk_firmware/nora_v01_via.hex
        0%                            100%  Programming 0x5E80 bytes...
        [>>>>>>>>>>>>>>>>>>>>>>>>>>>>>>>>]  Success
        0%                            100%  Reading 0x7000 bytes...
        [>>>>>>>>>>>>>>>>>>>>>>>>>>>>>>>>]  Success
        Validating...  Success
        0x5E80 bytes written into 0x7000 bytes memory (84.38%).
    >>> dfu-programmer atmega32u4 reset
    *** Atmel DFU device disconnected: ATMEL ATm32U4DFU (03EB:2FF4:0000)
    ```

    書き込み完了メッセージが表示されたら、QMK Toolboxを終了してもかまいません。  

    これとは違うメッセージ（書き込み失敗など）が表示された場合は、スクリーンショットを撮ったり、メッセージをコピーしておくと、何らかのサポートを受ける場合にスムースに話が進みます。

1. 書き込みが終わってから30秒程度でキーボードが起動し、キー入力できるようになります。  
  ファームウェアを書き込んだ後、初回起動時に外部EEPROMの消去をおこなっています。  
  この消去処理にしばらく時間がかかっています。

1. リセットボタンを使ってDFUモードにする操作をおこなった場合は、[資料：EEPROMを消去して、初期状態に戻す方法](#資料eepromを消去して-初期状態に戻す方法)をおこないます。

以上でQMK Toolboxを使用したファームウェアの書き込み作業は完了です。

</details>

### 資料：EEPROMを消去して、初期状態に戻す方法

EEPROMに記録されているデータを消去し、初期状態に戻す方法について説明します。  

<details>
<summary>《《《 詳しい説明 》》》</summary>

キーマップやLEDの表示モードなどのEEPROMに記録されているデータを消去し、初期状態に戻すことができます。  

また、古いデータが残って動作がおかしくなるのを防止するため、リセットボタンを使用してファームウェアを書き込んだ際にもこの操作をおこないます。

1. USBケーブルを接続している場合は、ケーブルを抜きます。

1. キーボードの左上のキーを押したまま、USBケーブルを差し込みます。

1. ケーブルを差し込んで、1、2と数えてから、USBケーブルを抜きます。

1. USBケーブルを差し込みます。

1. 10秒ほど待つとキーボードが起動します。

以上でEEPROMが消去され、初期状態に戻ります。

</details>

## サービスマニュアル

基板の準備やファームウェアの書き込みなど、出荷前の作業メモです。

<details>
<summary>《《《 詳しい説明 》》》</summary>

### パーツリスト

| 部品名 | 個数 | 備考 |
| :---- | :-----: | :---- |
| USBコネクタ<br>USB4085-GF-A | 1 ||
| ESD<br>PRTR5V0U2X | 1 | SMTAしなかった場合 |
| FUSE<br>0ZCJ0050AF2E | 1 | SMTAしなかった場合 |
| リセットスイッチ<br>RS-187R05A2-DSMTRT | 1 ||

### 基板セットアップ

作業対象は基板Baseのみ

1. 部品取り付け

    1. 基板裏側からUSBコネクタを取り付ける

        テスターでピン接続、ショートしないことを確認する。
        USBコネクタ接続図  
        USBコネクタ接続図

    1. （オプション）基板裏側`D10`へESDを取り付ける

        基板に描かれた取り付け方向を参考

    1. （オプション）基板裏側`F1`へFUSEを取り付ける

        方向なし

    1. リセットスイッチを取り付ける

        方向なし

1. ファームウェア書き込み

    1. QMK Toolboxを起動して、書き込むファームウェアを開く

    1. 基板をPC/Macへ接続

      QMK Toolboxに、デバイスの接続メッセージが表示されることを確認。

    1. 基板のリセットスイッチを押す

      QMK Toolboxに、デバイスの切断と接続のメッセージが表示されることを確認。

    1. QMK Toolboxの`Flash`ボタンを押して書き込む

    1. Remapを開いて接続（自前のJSON読み込み） → EEPROMの初期化に1分ほどかかる

    1. Remapでキースイッチのスルーホールの反応を確認する

</details>

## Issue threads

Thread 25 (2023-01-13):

PCB: スイッチソケットのパッド形状をなんとかしたり

jpskenn, 2023-01-13:
ソケット同士が重なるところや、ロータリーエンコーダと同居するところで、
ソケットのパッド形状をなんとかしたら、そこそこうまくいったりしないだろうか？

参考
https://github.com/kymok/kicad-libs/tree/master/Switch_CherryMX_Kailh_Socket.pretty
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

jpskenn, 2023-04-08:
https://github.com/jpskenn/Sandy/commit/cdb025bbacb6ea6c0b4bf80bc543d558b9c1ff07

Closed 2023-04-08.

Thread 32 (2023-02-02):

PCB: スイッチプレートの枠が足りない箇所は、スルーホールのフットプリント追加

jpskenn, 2023-02-02:
スイッチプレートで枠が足りないところや、枠自体が存在しない（設置するのがつらい）ところは、
Hotswapソケット以外に、スルーホールのフットプリントを逆方向で追加する。

Midのこことか
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

jpskenn, 2023-04-05:
すべてのスイッチをソケットにする
＆
すべてのスイッチをスイッチプレートでスタビライズする

というのを目標にするので、このアイデアは封印。

Closed 2023-04-05.

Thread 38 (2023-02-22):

基板間の隙間へ挟むフォーム素材

jpskenn, 2023-02-22:
基板自体の振動によって発生する音などを抑制するため、部分的でもいいので、フォーム素材を挟みたい。

jpskenn, 2023-04-05:
v01の3台目でチェックしたい。

jpskenn, 2023-04-14:
しばらKBDfans 5degreeケースで使っているが、
基板が振動することによる不快な音などは感じないので、
各自の好みで、好きにカスタマイズする要素とする。

Closed 2023-04-14.

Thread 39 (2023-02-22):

PCB: Mid基板、Mid→Baseのネジがスイッチに干渉する。

jpskenn, 2023-02-22:
使用予定のネジ https://wilco.jp/products/F/F-EB-03.html#page3
ネジ頭がφ3.5mm（普通のネジはφ4mm）だが、
大きめのハウジングのスイッチだと、スイッチとスイッチの間が3.15mmとなるため、ちょっと干渉する。
ギリギリ押し込めるかな？というところだが、実物でチェックが必要。

場所はここ。（反対側も含めて2箇所）
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

jpskenn, 2023-03-26:
少し斜めに差し込む感じで、スイッチへの干渉なしでネジを入れることができた。

Closed 2023-03-26.

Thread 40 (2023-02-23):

基板間隔

jpskenn, 2023-02-23:
リファレンス（デフォルト出荷同梱物）となる、基板間隔を決める。
スペーサー + 基板の厚み（1.6mm）が実際の間隔となる。

スペーサーまたはナットの厚み（基板の厚みは含まない）に関連する数値リスト
- 1.2（ナット3種）：スイッチのピン当たるNG
- 1.6（ナット1種 or 2種）：スイッチのピン当たるNG。ピンカットしたらなんとか？
- 1.7（スイッチのピン3.3から基板の厚み1.6を引いた値）：最低ライン
- 2（中空スペーサー2mm）
- 2（ナット1種 or 2種 + ワッシャー0.4mm）
- 2.2（ナット3種 + 中空スペーサー1mm）
- 2.4（ナット3種 ×2）
- 2.4（ナット1種 or 2種 + ワッシャー0.4mm ×2）
- 2.6（ナット1種 or 2種 + 中空スペーサー1mm）
- 2.7mm （ナット3種 + 中空スペーサー1.5mm）
- 2.8（ナット1種 or 2種 + ナット3種）
- 3以上（両メネジスペーサー）:0.5mmきざみ

jpskenn, 2023-03-26:
cherryプロファイルでの感想。
- base → mid
  2mmでok。

- mid → top
  3mmスペーサーは、saキーキャップで試していたときよりも段差が高くなっている。
  自分にはちょうど良いが、最初はけっこうアグレッシブな段差に感じられ、ちょっとびびってしまった。
  打鍵してみるとtyとかも変な感じではないし、monkeytypeで78wpmも出た。
  また、1行目の数字行がすんごく近くなったので、レイヤーで2行目に数字行を持ってきて40%風にしなくてもいいかもしれない。
  しかし、これを初めて触る人にも当てはまるかと言うと、やはりアグレッシブすぎると思われる。

一般向けには、mid → topは2mmがいいかも。
3mmのスペーサーも入れといて、選べるようにしてもいい。

jpskenn, 2023-04-05:
mid → top を2mm（ナット＋ワッシャー）にすると、
midからあがってきたネジをtopオモテでナットで止めることになるが、
スイッチとスイッチの間にナットが入ることになり、
工具の入るスペースがなくなり、ナットを締めることができない。

よって、mid → top は3mmとする。

Closed 2023-04-05.

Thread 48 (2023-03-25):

基板間コネクタの変更案→薄型

jpskenn, 2023-03-25:
Molex Pico-EZmate Connector (781710004)
JST SHに比べて、かなり薄い。
ケーブルの入手性が難点かも。

S1 Daughter Boardで採用されてる
https://unified-daughterboard.github.io/#/announcements/announcement-20230118

jpskenn, 2023-04-05:
DigiKeyでコネクタとケーブルを買ってみた。
https://www.digikey.jp/ja/products/detail/molex/0781710004/2424925
https://www.digikey.jp/ja/products/detail/molex/0369200400/10232998
コネクタは妥当な価格だが、
ケーブルは383円で高すぎるため、金額的に使用は無理と判断。

Closed 2023-04-05.

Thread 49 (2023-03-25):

パームレスト一体型、ボトムプレート

jpskenn, 2023-03-25:
Glove80を使ったあとに、Sandy（キーキャップ変えただけ）を打鍵すると、パームレストがなくて寂しい感じになる。
ボトムプレートを手前に延長して、横長長方形のプレートをネジどめして、パームレストにならないかな？

パームレストを別で購入せずに一体型にするのは、
キーボードを動かすとき、パームレストを別に動かすのが嫌。（ちょっとどかすときに、ひとつかみで済む）
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

jpskenn, 2023-03-26:
パームレストのみならず、キーボード部分にハイプロプレートを追加してもいいかも。
基板が3段になってるので、どんなハイプロにするかを考える必要あり？

jpskenn, 2023-03-26:
タカチの傾斜スペーサー
https://www.takachi-el.co.jp/products/WSP

jpskenn, 2023-03-26:
ネジが斜めなのは気にせず、少し厚めのゴムとかシリコン素材のワッシャーをかませばなんとか？

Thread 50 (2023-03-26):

PCB Base: 右下ネジ上の1.5u、スイッチの固定ピンがフリーになってて、ゆるい

jpskenn, 2023-03-26:
ケースネジを避ける穴を開けているので、スイッチの固定ピンが固定されず、3ピンと同じ状態。
はんだ付けがちょっとシビア。

jpskenn, 2023-03-27:
マイナーなレイアウトなので、ドキュメント対応だけでよい？

jpskenn, 2023-04-08:
v02だとソケットになるし、スイッチプレートつけるので3ピンスイッチでも問題ない。
→クローズ

っていうか、5ピンスイッチだと、ケースの右下ネジ穴に固定ピンの片方が干渉するかも？みたいな感じになる。
（ビルドガイドで対応）

Closed 2023-04-08.

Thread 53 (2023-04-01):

PCB: テストポイントをまとめてテストしやすく

jpskenn, 2023-04-01:
- row*colのマトリクスの形にテストポイントをまとめて（並べて）、テストしやすく
- 組み立て後にもアクセスしやすいところへ配置
- SHコネクタ裏側のスルーホールあれはあれで良いが、Midとか組み立て後にテスター当てられないので、別の場所にテストポイント追加

jpskenn, 2023-04-07:
v02作成の省力化のため、テストポイントの再配置はなし（微調整くらい）。

SHコネクタについては、
組み立て後（スイッチ取り付け後）とかにもテスター当てたいので、テストポイント追加の方向で考え中。

jpskenn, 2023-04-08:
スイッチ取り付け後にテスター当てられないのは、元々用意していたRow, Colのテストポイントで代用できるので、何もしなくてよい。

Closed 2023-04-08.

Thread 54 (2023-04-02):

PCB: 配線、VIAで、"Sandy"の文字を描く

jpskenn, 2023-04-02:
無駄配線になるかもしれないが、
シルクだと、下の配線で見栄えが悪くなったりするので、
だったら、配線自体で描いてしまえという考え。

Redditにあったこれが、配線が`3`とか`7`に見えてきて、思いついた。
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
https://www.reddit.com/r/KiCad/comments/129yxz7/first_time_making_a_circuit_board_can_anyone_see/

配線の曲げが鋭角になってるのはちょっと気になるけど。

jpskenn, 2023-04-08:
中央を横切るバスがあったりするので、見送り。

Closed 2023-04-08.

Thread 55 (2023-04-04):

スイッチプレートとソケット

jpskenn, 2023-04-04:
スイッチが半田付けなのは、気軽にスイッチの交換ができないのと、一般への販売に障害となる。

base, mid, topの間隔を固定（2mmと3mm）にするなら、プレートも同じ間隔でネジ止めしたら、段差のついたプレートにならないか？

jpskenn, 2023-04-05:
すべてのスイッチに対して、
- ソケット対応（マイナーバリエーションは非対応でもしょうがないけど…）
- スイッチプレート対応（非ソケットで逃げたりしない）

jpskenn, 2023-04-05:
Base用のスイッチプレート
MidのPCBとのクリアランスが不足して、
スタビ付近で枠が作れず、下の辺だけになってしまう問題（○で囲んだ箇所）は、
MidのPCB外形で、下側をスイッチが乗るギリギリまで切り詰める感じに変更して、
Baseのスイッチプレートの枠を確保する。

ai03的な余裕のあるスタビカットアウトでも2.5mmの枠になるし、
もうちょい狭めにすれば3mmの枠になる。

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

jpskenn, 2023-04-08:
**販売が〜
一般ウケが〜
っていうのは、Sandy（Jones、Noraも含め）の開発精神に合致しないということを再確認、再認識する。

オレオレ自作キーボードなんだから、好きなものを作ろう。**

jpskenn, 2023-04-09:
https://github.com/jpskenn/Sandy/issues/64#issuecomment-1501059522

Closed 2023-04-09.

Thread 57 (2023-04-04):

5方向スイッチの必要性

jpskenn, 2023-04-04:
v01は使い勝手の実験でつけてみたが、

- 実用性
- 費用
- 入手性

などを考えると、v02以降はいらないかも？

jpskenn, 2023-04-04:
イマイチな点
- 5方向スイッチのまわり、基板丸見え
- 良い具合のノブがない
- 個人的に、マウス的な使い方をしない
- Dynamic  Macroにマウス移動を入れるなら、レイヤー内の通常キーへマウスキーを割り当てたやつで十分。

jpskenn, 2023-04-05:
- 値段（$4〜）の割に、そこまで使いたい雰囲気にならない

v02では、廃止。

jpskenn, 2023-04-08:
9f42b579d0e1ec240a0abd254a73eb68e40d1673

Closed 2023-04-08.

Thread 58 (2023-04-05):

基板間隔とスイッチプレート

jpskenn, 2023-04-05:
v01の試作で、mid → top の間隔を3mmと決定した。

mid用スイッチプレートの浮島をなんとかするため、
mid → top の間隔を3.4mmとして、
topをmidのスイッチプレートを兼ねたものにするのはどうか？

jpskenn, 2023-04-05:
v01の3台目で、
mid → top の間隔を
3mmスペーサー　＋　0.4ｍｍワッシャー
で組み立てて、0.4mmの違いが悪い方向に行かないか確認する。

jpskenn, 2023-04-06:
mid → Topを3.4mmにして組み立ててみた。
DSSプロファイルのキーキャップをつけたせいか、打鍵に違和感があり、流れるような打鍵ができず、何だかギクシャクしてしまう感じ。
また、`W E I O`に置いた薬指と中指の指先が、1行目（Top）のキーの側面に当たりやすくなってしまったようにも思える。

近いうちに、KATに付け替えて試す予定。

jpskenn, 2023-04-08:
KATに付け替えてテスト中。
やはりDSSは、元々最適化されてる量が多くて、段差をつけると、バランスが崩れてしまったようだ。

ちょっと打鍵がしづらい感じなのは、Kailh Midnightスイッチのポコポコ感にもあるかも。

3.4mmの段差は、ちょっとアグレッシブな印象もあるが、打鍵しづらいというレベルほどではない。
そのうち、Cherryでもテストが必要。

jpskenn, 2023-04-09:
80wpmにはなかなか届かないが、75wpmは出るので、3.4mmで問題ないと思う。
`Y`と`T`の打鍵が高すぎるとは感じないし、
数字行は元々それほど打鍵しないから、これで良さそう。

Closed 2023-04-09.

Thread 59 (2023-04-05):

PCB v02: すべてのスイッチをソケット化

jpskenn, 2023-04-05:
ポリシー
- 104usと自分のレイアウトは、全てソケット。
- ソケット干渉するとかは、なんともならないときは、縦配置しても良いことにする。
- マイナーなものはスルーホールでも良いが、それだったら、そのレイアウト無くすとかで良い。
- できるかわからんけど、SMTAやってみる
→バリエーションあるとこ、全てソケットつけたら、使ってないソケットがスイッチに干渉するかも？注意

jpskenn, 2023-04-05:
Baseで右下ネジ穴のまわりをくり抜いてるところ、
2uと1.5uのバリエーションの場所だが、横に並べるとソケットが干渉する。
- 1.5uを上下逆にしたとき、くり抜いた穴にかぶってダメ
- 2uを上下逆にしても、ちょっとだけくり抜いた穴にかぶる

実機でケース側ネジ穴と、くり抜いた穴のクリアランスを確認して、もう少しくりぬきサイズが小さくならないか調べる。

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

jpskenn, 2023-04-05:
左Shiftの1.75uが、ソケットで入れるのは無理。
スルーホールで入れても良いけど、これ必要なんだっけ？

jpskenn, 2023-04-08:
https://github.com/jpskenn/Sandy/issues/59#issuecomment-1497441820
40%系のバリエーションは、元々マイナーだし、自分自身も使ってないので削除
- 左Shift 1.75u
- tab 1.25u

jpskenn, 2023-04-08:
https://github.com/jpskenn/Sandy/issues/59#issuecomment-1497451985
ロータリーエンコーダ、中央の2個は削除

jpskenn, 2023-04-08:
右下ネジ穴まわりの1.5uと2uは、こんな具合で処理した。

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

jpskenn, 2023-04-08:
cdb025bbacb6ea6c0b4bf80bc543d558b9c1ff07

Closed 2023-04-08.

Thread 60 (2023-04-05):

PCB v02: 左右のLED取り付けON/OFFジャンパー不要

jpskenn, 2023-04-05:
- 手順が増える
- 忘れたらLED点かない
- LEDは、取り付ける or 取り付けない の2択になるので、あんまり意味ない
- 左を先頭にしておけば、自分は2個だけつけて、それで十分

ということで、ジャンパーなしとする

jpskenn, 2023-04-05:
a245b5afac12a38afd6d1484ba0505f72e9dd9df

Closed 2023-04-05.

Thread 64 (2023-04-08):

スイッチプレート：最下行、4キーと5キーを1枚のプレートにすると、全部くっつくぜ

jpskenn, 2023-04-08:
ジェネレーターで簡易作成したもの。（スタビの方向とか違ってる）
3u＋αの長枠、もしくは両隣も含めて5-6uくらいの長枠になりそう。

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

jpskenn, 2023-04-08:
いろいろ考え中

- 対応レイアウトを絞り込む
  個人的には最下行は5キーで決定（2u使わん）なので、そっちだけに統一。
  →104US対応じゃなくなる
- プレートを複数用意する

jpskenn, 2023-04-08:
最下行を
4キー（2 + 1 + 1 + 2）
から
5キー（1.5 + 1 + 1 + 1 + 1.5）
にした場合、
1.5u 2個を、DSAか何かで代用すれば、
104US + DSA2個でなんとかなる。

jpskenn, 2023-04-08:
https://twitter.com/tamano/status/1644687296447533056
「OSSは、誰でもカスタマイズできるじゃん」っていう言葉をいただいて、
ここ数日、製造した基板やキット化したものを完成系だと誤認していたのを、
Sandy（JonesやNoraも）がOSSだってのをあらためて思い出した。

無理にバリエーションを詰め込んでつらくならない方向で進める。

→スイッチプレート、最下行は、5キーで作成

jpskenn, 2023-04-08:
単一レイアウトに変更
最下行：5キー版のみ
左シフト：2uなし、1+1のみ

06d33d099982440fe964efa50331099f5f571981

jpskenn, 2023-04-09:
最下行、レイアウトを単一にしても強度的に不安なので、製造用の枠つけた。
中央部、縦のラインが細いの、製造大丈夫か心配だが、とりあえずこれで。
（Mid基板との間隔がほんの少しだけあるので、あと0.5mmとかは太くできる）
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

Closed 2023-04-09.

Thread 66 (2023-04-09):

スイッチプレート、Midのディフューザーはどうなる？

jpskenn, 2023-04-09:
Top基板（Midプレート付き）にディフューザーつける。
既存のMid基板のディフューザーは無くす。

でよいか？

jpskenn, 2023-04-09:
Baseのプレートにディフューザーをつける。
既存のMid基板から、取り外し。
35e71b834fdbd28e3de003758f964c239d6a609d
ccf44ce12c64579ef25a1904588dae06a6f4b8fc

jpskenn, 2023-04-09:
8682e6618f9bb58d869be01cf61147399e04faab

Closed 2023-04-09.

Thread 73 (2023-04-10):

基板接続のネジを締める場所がわかりやすいようなシルク

jpskenn, 2023-04-10:
v01だと、組み立て後に見えないよう、スペーサー側にシルクをつけていたが、
v02はスイッチプレートをつけるので、ネジを締める側にシルクをつける。

ネジアイコンでも良い。

jpskenn, 2023-04-10:
1547e9aa496ac704b1243c5f89f4bcfdf33272b6
42e1814414b152b0f2eb2b6e6028d1d29dd2a9cc

Closed 2023-04-10.

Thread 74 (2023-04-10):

原価計算

jpskenn, 2023-04-10:

jpskenn, 2023-04-11:
原価増加要因
- 基板枚数の増加
- ソケットの添付

原価減少要素
- 5方向スイッチ削除
- ダイオード減少
- 基板を一度にたくさん作る
- extendパーツを自前実装する（枚数多いなら一枚あたりが安くなるので、手間を考えると微妙？）

原価下げられる要素
- QwiicケーブルをAliの安いやつに変更
  10cmのやつしかない？
  ケーブル硬いかも？

その他、儲かるポイント
- SHコネクタ実装サービス 1500円とか？

jpskenn, 2023-04-11:
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

jpskenn, 2023-04-11:
梱包とか基板セットアップなどの金額は入ってないが、
だいたい6000円ってことで、確認した。

Closed 2023-04-11.

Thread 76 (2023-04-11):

Mid→Top 3.4mmでCherryプロファイルテスト

jpskenn, 2023-04-11:
とりあえずKATでしかテストしてない（DSSもつけたけど、3Dに合わなかった）ので、
他のプロファイルでもテストする。

jpskenn, 2023-04-12:
Cherryに付け替えてテスト。
KAT Space Cadetをつけていたときより、打鍵しやすいような気がする。
スイッチ、キーキャップの重さ、プロファイル形状のマッチングの問題？
3.4mmでも問題なし。
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

Closed 2023-04-12.

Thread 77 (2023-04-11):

ボトムプレート作るか？

jpskenn, 2023-04-11:
ケースに入れると、どうしても基板下に無駄な高さが出てしまうので、
ボトムプレートで組んで、基板下をできるだけ低くしたい。
（家に余ってるボトムプレートがたわんでたので、ちょっと…）

案
- Jones, Noraのボトムプレートを流用。Sandyロゴ追加
  - 1.2mmのFR-4？
  - ナット＆ワッシャで2mm接続（現在は3mmスペーサー）
- Base基板の突起を避ける切り抜きをつけたBase基板密着型。最低高狙い

jpskenn, 2023-04-11:
Base基板の部品配置的に、密着型は厳しいな

jpskenn, 2023-04-13:
Jones, Noraと同様の（というかNoraのデータを元に）ボトムプレートを作成。

0b64df41ce0b47296789886aad7e8c782377c1a8

Closed 2023-04-13.

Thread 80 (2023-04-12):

スイッチプレートの枠を最大まで太く

jpskenn, 2023-04-12:
現在は、基板の外形に合わせた枠の太さになっている。
Topとか、ちょっと細く感じる。製造大丈夫か？

基板や他のものに干渉しない範囲で、枠の太さをギリギリまで太くする。

jpskenn, 2023-04-12:
Baseはまだマシなので、
とりあえずはTopだけ実施。

jpskenn, 2023-04-13:
a2c6c5a175ee1676dd0c96e2a5e9b198ce5074f6

Closed 2023-04-13.

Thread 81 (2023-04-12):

Topのスイッチプレートつけたら、Mid→Topがねじ止めできない

jpskenn, 2023-04-12:
作業手順では、
ネジ8本のうち、3本程度仮止めしておき、
確認作業が終わってから、すべてのネジを止めるようになっている。

プレートつけたらネジ止めできないので、
- 手順で、仮止めやめて、最初から全てネジ止め
- プレートにネジ止めできる穴つける
のどちらかを考える。

jpskenn, 2023-04-12:
プレートにネジ穴つける方法では、
すでにボトムプレート用ネジ穴が開けられているので、
強度的に追加できる穴は2箇所。

となると、ネジの仮止めを8本中6本することになり、
だったら8本全部ネジ止めするのと変わらんのじゃ？
ということになるので、手順変更で仮止めなしにするのがよさそう。

jpskenn, 2023-04-13:
手順変更
d8673cf3f606da5f9213732b2d11663b44be15a1

Closed 2023-04-13.

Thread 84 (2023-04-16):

製造、キット化費用

jpskenn, 2023-04-16:
原価と販売額についての検討

jpskenn, 2023-04-16:
他製品の参考

Jones
https://shop.yushakobo.jp/products/2798

Nora
https://shop.yushakobo.jp/products/4296

https://shop.yushakobo.jp/products/ergoarrows?variant=42669070909671
https://shop.yushakobo.jp/products/consign_reviung41
https://shop.yushakobo.jp/products/4994
https://shop.yushakobo.jp/products/nomu30kit

Ergotonic49
https://shop.yushakobo.jp/products/2942

jpskenn, 2023-04-17:
「キット一式に、スイッチとキーキャップを追加したらキーボードとして完成する」
というのがほとんどのキットの内容。（ProMicroは別途というものもある）
Sandyのボトムプレートは作ったけど、キットに含めるかは未決定で、キット単体だとキーボードとして完成しない。
¥15,000だったとして、ケース代が別にかかると考えると、他のものを選んじゃうよな〜って思う。

ボトムプレートを含めた原価計算もおこなう

jpskenn, 2023-05-04:
20台を製造するとして、¥16,800くらいでなんとなりそう…
という感触で、あとは実際に製造して価格を確定する。

jpskenn, 2023-05-28:
製造不具合や傷品などを考慮して、15台で製造。
それでも、¥16,800でいけそうな費用だった。

jpskenn, 2023-06-03:
16000円台は高い印象がするので、再検討。

jpskenn, 2023-06-03:
ギリギリ15000円台の、15900円はどうかな？

jpskenn, 2023-06-04:
15000円台もお高い印象。
基板セットアップ費（自分の人件費）をNoraと同等にして、
原価率も同率として、
14000円台前半とする。

Closed 2023-06-04.

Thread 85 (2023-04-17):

Readmeでホームポジションの写真を掲載

jpskenn, 2023-04-17:
手がハの字になってるのがわかるような写真を添えて、ホームポジションを周知。

また、手首を曲げてるのはNGということも周知。

jpskenn, 2023-04-17:
これがホームポジション
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

jpskenn, 2023-04-17:
これはNG
ってか、こんなポジションで打鍵してる人いるの？
不自然に曲げないとダメだし、その時点でおかしいでしょ。
某酸のサイトに、この手のイラスト？が載ってたような記憶
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

jpskenn, 2023-04-17:
不自然な思想誘導？
https://salicylic-acid3.hatenablog.com/entry/self-made-keyboard-faq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

jpskenn, 2023-04-18:
Jones, Sandyは真ん中に2u挟んだちょいワイドだけど、
普通のロースタガのキーボードを使う時だって、
上腕を体の前へ曲げるなんてしないよね？

こうだから
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

jpskenn, 2023-04-19:
ツイートでなんとなく周知
https://twitter.com/jpskenn/status/1648459448669843461?s=46&t=VIweMQCylMF9q41_CzTUUQ

jpskenn, 2023-04-27:
#62 のメモ内容は、こっちで引き取り

jpskenn, 2023-05-13:
ちょろっとツイートした
https://twitter.com/jpskenn/status/1657499735060803584

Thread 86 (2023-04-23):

ボトムプレート

jpskenn, 2023-04-23:
DN0020では単純なボトムプレートを用意した。
それはそれでよい。

ボトムプレートと基板間を3mmまたは2ｍｍとして、
見た目をちょっと良くして、打鍵音の漏れを軽減するため、
アクリル板を挟むことを考えている。

Base基板：
- 最下行のダイオードを移動
- 最下行左右端キーはなし。（ついでなので、左右2uをなしでもよい）
  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
- アクリルが基板サイズからはみ出さないデザインの場合は、下から2行目の左右端もなし

jpskenn, 2023-04-23:
最下行の左右端キーを無くしたとき、Base用スイッチプレートはどうするの？

jpskenn, 2023-04-23:
Baseうら側、DN0020
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

jpskenn, 2023-04-23:
Baseプレート、DN0020
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

jpskenn, 2023-04-27:
以下の理由により、Base基板とボトムプレートの間隔は3mmでもよしとする。
- ケーブルを逃すのに、2mmでは難しいため。
- 2mm間隔は、7mmナットとワッシャー

jpskenn, 2023-04-28:
https://github.com/jpskenn/Sandy/issues/86#issue-1679869985
アクリル板対応で、最下行、下から2行目の左右端のキーをなくすことを考えていたが、
左右端にキーが欲しいこともあるだろうから（自分もいろいろ試してみたい）、
キーの配置（＝スイッチプレート）はそのままで変更しない。

アクリル板が左右端スイッチ、特に左側のソケットパッドにかかってしまうので、
最下行と下から2行目の左端キーを、ソケットを上下反転させることを考えている。

jpskenn, 2023-05-03:
アクリルフレームよりも、静音フォームを優先。
フォームでスイッチを囲えるようにしたい。

jpskenn, 2023-05-06:
舎のレーザー加工サービス クリアランスセールで、300mm\*90mmに収まらないか？
https://shop.yushakobo.jp/products/lasercut-clearance-sale

jpskenn, 2023-05-09:
アクリルフレームをアンダーグローLEDで光らせてインジケータとしても使える？

jpskenn, 2023-05-10:
フォームをレーザーカットしようとしていたが、
3mm厚のシール付きポロンシートを、50mm\*30mmくらいにカットして、
Base基板うら側中央へ貼り付けるだけで十分な気がしてきた。

jpskenn, 2023-05-11:
一旦完成
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
　

jpskenn, 2023-05-12:
6ab2a49433d9485f94e32e5290bd4c6988df1077
SK6812MINI-E対応

jpskenn, 2023-05-13:
遊舎工房のレーザー加工サービス クリアランスセールを1件発注した。
https://shop.yushakobo.jp/products/lasercut-clearance-sale

問題なければCloseする。

jpskenn, 2023-05-28:
アクリルフレームの長辺のところ、特に下側（キーボード手前側）がたわみやすい。
スペーサーの穴を開けているので、実際に組み立てるとたわみの影響はないが、
少し心許ない印象になってしまうため、補強が必要。

jpskenn, 2023-05-28:
補強入れた。
タイミングを見て、どこかへ発注。
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

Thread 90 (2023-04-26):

DN0020: ソケット化したため、SHコネクタのケーブルを逃す場所が少なくなった

jpskenn, 2023-04-26:
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

ケーブルをBase基板の穴から出して、Base基板の下（うら）側へ逃すことは可能。
**ケーブルの逃し方をビルドガイドに書く必要あり**

ボトムプレートとBase基板の間隔は3mmがベター。
（別の話として、間隔2mmでは、ナットとワッシャーを取り付けるのがつらい→不可能ではない？）

jpskenn, 2023-05-06:
ケーブルをBase基板うら側へ逃してもいいことを、なんとなくわかるように書いた
3445a74db31f19724dd0ea9867d4ebd395b97184

Closed 2023-05-06.

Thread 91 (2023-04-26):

DN0020: ボトムプレートとBase基板の間隔。2mmはつらい？

jpskenn, 2023-04-26:
3mmはJonesでもやってきた間隔で、普通。
Base基板の穴から逃したケーブルも収まっている。

2mmはケーブルが逃がせるか心配。
また、Base基板のネジ穴、左右端は切れ込みが入っているので、
ナットとワッシャーでとめるのがやりにくい。

アクリル板はさむとかのアイデア的には2mmにしたいが…

jpskenn, 2023-04-26:
2mmでいけるか試す。

jpskenn, 2023-04-27:
チェックするのもつらいので、たぶんつらいと判断し、3mmで決定とする。

Closed 2023-04-27.

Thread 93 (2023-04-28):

ファームウェア：　LEDインジケータ

jpskenn, 2023-04-28:
- Scrollとかのロック状態を表示
- NumLockがずっと点灯してるのは嫌だけど

jpskenn, 2023-05-04:
ScrollLockのインジケータを追加。
NumLockは、被害が少なそうなのと、常に点灯されても嫌なので追加せず。

339eb8f939e4b83d43c5d17ee43178928f27ea0a
c5aad37308f265f9b439b4aa51b8bfc90e4a381b

Closed 2023-05-04.

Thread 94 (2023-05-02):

ボトムプレート：　デザイン調整

jpskenn, 2023-05-02:
- [ ] うら側：ガイドラインもうちょい細く
- [ ] うら側：SandyのQRコードとURL
- [ ] おもて側（内側）：Jonesロゴとかなくす？コンパチ表記？
- [ ] おもて側：GH60コンパチ表記？

jpskenn, 2023-05-03:
ガイドライン、あまり使わなそうなものを減らした。

機能的なシルク以外は入れたく無いので、QRコードとURLはなし。

Jonesロゴとかは残す。コンパチなので。

GH60はちょっとだけ書いた。

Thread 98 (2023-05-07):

アンダーグローLED for アクリルフレーム（案）

jpskenn, 2023-05-07:
アクリルフレーム用に、Base基板うら側から下へ向けたLEDを配置。

既存のインジケータLEDは、現在左右2個ずつあるが、左2個だけでも良いのでは？
それなら、LEDの配線引き回しせずにすむ。

jpskenn, 2023-05-09:
左右2個ずつ、上下6個ずつでお試し。

スイッチ間、ネジ穴などで、ちょっときついところがある。

jpskenn, 2023-05-09:
動かなかったら遺物が乗ってる基板って気持ちでやってる

jpskenn, 2023-05-10:
LEDを乗せることができ、アクリルフレームもなんとかなりそうなので、Closeとする

jpskenn, 2023-05-10:
ファームウェアは、別項目とする

Closed 2023-05-10.

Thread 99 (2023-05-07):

ボトムプレート：Hotdog Mount?

jpskenn, 2023-05-07:
CannonKeysのこれ
https://cannonkeys.com/products/type-b

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

jpskenn, 2023-05-09:
とりあえず耐震マットマウントを試してみよう。

jpskenn, 2023-05-10:
普通に使える。
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

jpskenn, 2023-05-10:
ソケットがボトムプレートに干渉するのを恐れて少し多めに詰めたけど、
あんまり詰めると、ボヨンボヨン感が弱まって、しっかりした感じになるので注意。
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

jpskenn, 2023-05-27:
耐震ジェルマウントが有効なので、これをカスタマイズガイドに掲載する。
ハードウェアの変更、機能追加はしない。

Closed 2023-05-27.

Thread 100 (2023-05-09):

カスタマイズガイドをドキュメント化

jpskenn, 2023-05-09:
3D的な拡張、打鍵感の向上などのカスタマイズのガイド、アイデアをドキュメントにまとめる。

- PORONシートを入れる
- TECSEEミディアムスイッチ
- 耐震ジェルマウント

など？

jpskenn, 2023-05-13:
ゴム足サイズ変える

jpskenn, 2023-05-14:
fdb3cece155c64940f90fa06641c405a8bb0f1d6

Closed 2023-05-14.

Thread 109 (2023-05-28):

ファームウェア：アンダーグローをめちゃ明るくして、インジケータを暗めにしたいとき

jpskenn, 2023-05-28:
現在はインジケータの明るさは、RGB Lightingの明るさに同期している。
アクリルフレーム使用時に、アンダーグロー（＝RGB Lighting）をめちゃんこ明るくしたとき、
インジケータが眩しくなってしまうのをなんとかしたい。

jpskenn, 2023-05-28:
https://github.com/jpskenn/qmk_firmware/commit/479fbb940f2fc82f14d1f566ff2b6ce1c6796a8b

Closed 2023-05-28.

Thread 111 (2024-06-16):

キーキャップの対応チェック

jpskenn, 2024-06-16:
USとJPキーキャップで対応可能かを確認

jpskenn, 2024-06-16:
参考
PBT fans US Base
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
PBT fans US 40s
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

jpskenn, 2024-06-17:
PBTfans Doubleshot WOB
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

jpskenn, 2024-06-17:
PBTfansのBaseと40sなら、ほぼぴったり。
合ってないのは、
- R3左端CtrlがR4のもの
- R3Enterの左側（もしくは中央2キーのどちらか）に`

jpskenn, 2024-06-17:
普通の104USと、GMKのBaseだけではどうか？

jpskenn, 2024-06-18:
GMK Black Snail
Base Kit
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

jpskenn, 2024-06-20:
GMKとPBTfansのBaseだけで、ひととおり埋められる。

jpskenn, 2024-06-20:
US104
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

jpskenn, 2024-06-20:
US104（Numあり）だけでも、なんとか埋められる。
（PageUp/Downのプロファイルが違ったり、スペース1.5uが1.25uのALTで代用になるなど、ちょっとつらいところもある。）
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

jpskenn, 2024-06-20:
結論
DN0040のレイアウトは、
・Base + 40s + 1.5u Space + 2u POSで、完ぺきに埋められる。（100%）
・Base + 40s kitを使えば、ほぼほぼに埋められる。（気分的に98%）
・Baseのみでも、十分埋められる。（気分的に95%）
・104USは、ちょっと難ありだが、通常使用できる程度に埋められる（気分的に80%）

Closed 2024-06-20.

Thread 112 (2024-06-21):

スイッチプレートの穴をEdge.cutsじゃなくてフットプリントで

jpskenn, 2024-06-21:
追加料金を取られないかも？

https://x.com/copkbd/status/1803751343250907206

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

jpskenn, 2024-09-01:
スイッチ穴をフットプリント化した。
3Dビューアで見ると中に基板が残るのが、ちょっと気になるな。
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

jpskenn, 2024-09-03:
Top兼Mid用プレートにもやってみたが、ネジ穴との干渉とかあったりして、あとでやめるかも。

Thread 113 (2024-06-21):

MCU　RP2040へ変更

jpskenn, 2024-06-21:
ATmega32u4から、RP2040へ変更。
ファームウェアの容量増加と、RP2040が一般的になって安定してきたので、新しめの技術の取り入れ。

リファレンス
https://datasheets.raspberrypi.com/rp2040/hardware-design-with-rp2040-JP.pdf

参考
https://ymkn.hatenablog.com/entry/2023/12/10/000000

RP2040で作る自作キーボードの本（購入済み）
https://liliums.booth.pm/items/4444554

jpskenn, 2024-09-01:
aef67e5c2c4d424360937c87b87afe2bee60939d

Closed 2024-09-01.

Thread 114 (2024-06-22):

RP2040でLED（5V）を光らせるには？

jpskenn, 2024-06-22:
- LEDの電源（5V）
  USBから入ってきたのを、ヒューズとショットキーバリアダイオードを通したものを使用。
  これは以前のSandy（ATmega32u4）のときと同様。

- LEDの信号Data
  RP2040から出てきた信号を、3.3V→5Vへレベルシフトして使用する。

参考
https://zenn.dev/koron/articles/390bb5efa43ad0

jpskenn, 2024-06-22:
WS2812CはDataが3.3Vでも問題ないとのこと（High Voltage Input(VIH)が2.7V）。
しかし、WS2812Bの古いタイプはそうなってないので、念のためレベルシフトさせておく。

Closed 2024-09-03.

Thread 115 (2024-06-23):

Base基板の変更ポイント

jpskenn, 2024-06-23:
MCUをRP2040に変更することに伴う、Base基板の変更ポイント

- [x] USBのVBUS入力、Fuseの後ろにショットキーバリアダイオード追加（MCUの変更には直接関係ないけど、安全性向上）
- [x] MCUまわり総とっかえ（クリスタル、フラッシュメモリなども）
- [ ] MCUまわりのコンデンサ、抵抗は、あまり小さくしすぎない方向でいきたい。（最悪、手はんだで修正とかあるかもなので）
  →お手本が小さめのやつなので、今回は小さいやつでやる。
- [x] LED電源用のレベルシフト
- [x] BOOTLOADER/RESETスイッチの配置。GH60互換ケースの穴からスイッチ2個押せるん？
- [x] I2C接続のEEPROMトル
- [x] I2C接続の端子は残す方向。RP2040のピン？
  → 余ったGPIOピンは出すことにしている
- [x] ICSPトル

Closed 2024-09-03.

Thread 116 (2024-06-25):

レイアウト：R1を数字行にした場合、R2とずれが無くなるが問題ないか？

jpskenn, 2024-06-25:
これまでは、R1とR2は0.5uのずれがあったが、DN0040ではTABなどのサイズが1.5u→1uになったため、R1とR2のずれがなくなった。

これで使用に問題は無いか？

jpskenn, 2024-08-25:
Sandyを最も使っている人間（＝私）がSandyを40%として使っており、R1で数字や記号を入力することはほぼゼロである。
使っているのはESCと、別途キーマッピングしたPrintだけである。
というわけで、私は問題ない。

Closed 2024-08-25.

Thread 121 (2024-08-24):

インジケータLEDの場所

jpskenn, 2024-08-24:
- R4の左右
- 中央のメンテナンスベイ（カバーを透明化？）

jpskenn, 2024-08-26:
DM0030と同様に、乳白色のカバーをつけるのが好ましい。（LED直だと眩しい。また、斜めから見えない。）

jpskenn, 2024-09-01:
カバーじゃなくて、
「スイッチプレートの一部を、銅箔、マスク抜きして、基板自体の色を使用」でした。

jpskenn, 2024-09-08:
メンテナンスベイはやめる方向。
LED窓はつけた。
23b917055a90cf5f88f58043e66ac27477588cc2

Closed 2024-09-08.

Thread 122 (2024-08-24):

中央にメンテナンスベイ？

jpskenn, 2024-08-24:
RP2040のBOOTスイッチがGH60のケース穴から押せない？
DIPスイッチを乗せて（パターンあるけど乗せなくてもよい）、WinとMacモードを切り替え？
透明カバーをつけて、インジケータ、電源LEDなどを見せる？（キカイダーっぽい何か）

jpskenn, 2024-08-24:
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

jpskenn, 2024-08-24:
DIPスイッチは、ピンセットなど使わず、手でも操作しやすいくらいの大きさで。

jpskenn, 2024-08-24:
基板ベースは穴開いてる？
ミドル基板につける？

jpskenn, 2024-08-27:
BOOTとRESETのショートピン

jpskenn, 2024-09-08:
メンテナンスベイは、ピンをTopへ持っていくのが大変なので（キースイッチ用でいっぱいいっぱい）、ボツ。
BOOTとRESETは、キースイッチをひとつ取り外してジャンパ操作可能とする。

Closed 2024-09-08.

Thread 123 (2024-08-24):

R2-R3のケースネジ穴とスイッチ穴の干渉は？

jpskenn, 2024-08-24:
Snady DN0030まではR2-R3両橋のキーが1.5uだったので、スイッチのフットプリントとケースネジ穴は干渉していなかった（＝回避できていた）。
DN0040ではR1-R3までオルソになったので、ネジ穴との干渉が発生する可能性がある。

jpskenn, 2024-08-25:
- R2
R2はMid基板になるが、左右とも、外側から2番目のキーがネジ穴直上にくる。
Mid基板を取り付けた状態では、Base基板をケースにねじ止めできない。

-R3
スイッチ底面が、ケースネジの頭に干渉すると思われる。
低頭ネジでも、あまり良くなさそう。

jpskenn, 2024-08-25:
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
15uのGH60型ケースの左右0.5uをあけることで回避可能。

Tab、Enterなどを1uにするのは、40sキットを必要とせず、GMK BaseやUS104だけでなんとか埋められるようにするため。

Closed 2024-08-25.

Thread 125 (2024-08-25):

スルーホールタップの使用で、基板間のケーブルをなくせるか？

jpskenn, 2024-08-25:
- スルーホールタップ THシリーズ
  https://www.mac8sdk.co.jp/products/186
  スルーホールタップ(バラ100本入)【TH-1.6-M2-B】 4070円
  https://www.marutsu.co.jp/pc/i/91087/
- スルーホールタップ TH-1.6 シリーズ（スペーサーつき） 0.5mmきざみ
  https://www.mac8sdk.co.jp/products/258
  スルーホールタップ(バラ100本入)【TH-1.6-3.0-M2-B】 5188円
  https://www.marutsu.co.jp/pc/i/91122/

jpskenn, 2024-08-25:
DN0030では、SHコネクタにより
Base→Mid：12pin（4pin×3本）
Mid→Top：12pin
で接続していた。
信号的には、15pin必要なので、ネジ穴の数が足りない。

jpskenn, 2024-08-25:
ケーブルを無くす（スルーホールタップを電気的接続に使用）のは無理っぽい。

組み立てが簡単になるのであれば、ネジ、ワッシャー、ナットの代用としてもよいが、そうでもないような雰囲気。

何かに使えるかもしれないので、アイデアだけ残しておく。

jpskenn, 2024-08-26:
基板間のケーブル接続をやめると、ケーブルを通す穴を開ける必要がなくなり自由度が上がるため、ネジ穴による導通を実現したい。

jpskenn, 2024-08-26:
基板間のネジ穴を増やす方向で検討中。
コネクタを無くせば、その分、ネジ穴を配置する場所が増えるので、なんとかなる？

jpskenn, 2024-08-27:
R1にロータリーエンコーダーをつけたいのだか、SHコネクタひとつをBaseにつないだら、ロータリーエンコーダーが使えるようになるとかでも良い。

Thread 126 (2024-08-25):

DN0040 仕様

jpskenn, 2024-08-25:
- レイアウト
  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
  - キーサイズのバリエーションなし
  - GMKやePBTのBase Kitで最高の結果が得られるように。40sキット不要。結果的にUS104でもなんとかなる。
  - 中央部、2x2のエリアは、キーを配置せず、DIPスイッチやLEDインジケータ、ロータリーエンコーダとする可能性あり。
- キーの高さ
  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
  R3中央部を、DN0030より1段高くする。
- LED
  インジケータ、2-3個。`Z`と`/`の外側、もしくは中央。
  アンダーグローなし。
- 基板間の接続
  JST SHコネクタによる接続を踏襲するが、一部はネジ穴による同通により使用するケーブル本数を減らし、組み立てやすさを向上させる。
- ロータリーエンコーダ
  中央と右上（R1右端）はロータリーエンコーダに換装可能。
  中央2x2エリアにも配置する可能性あり。
- MCU RP2040
- 基板間の隙間を埋める何か（アクリル2mmと3mm？）

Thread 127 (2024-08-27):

RP2040用のRESET・BOOTスイッチ

jpskenn, 2024-08-27:
`Ctrl`を1uにしたので、隣の`A`との間が狭いため、RESET・BOOTスイッチの配置がつらい。
なるべくGH60型ケースの穴に合わせて配置するが、少しずれるかもしれない。

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

念の為、どこかのキースイッチを取り外して、ピンセットでショートさせられるスルーホールを用意しておく。

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

参考
https://okiraku-camera.tokyo/blog/?p=16074
https://geekhack.org/index.php?topic=97669.0

Closed 2024-09-03.

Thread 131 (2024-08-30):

Base基板より下、可能な限り薄く。

jpskenn, 2024-08-30:
パームレストは使わない。
低い方が、打鍵しやすい。

Base基板以下を1.2mmで？

jpskenn, 2024-08-30:
Choc V2ならMXなキーキャップ使えるの？

jpskenn, 2024-08-30:
Lofree Ghost switchとか、MX用キーキャップは嵌められるけど、スイッチのストロークが短くて当たるとのこと。

jpskenn, 2024-08-30:
Base基板とBottomプレートの接続を、Noraのようにゴムシート貼り付けでおこなう？
Sandyで耐震ジェルマウントを使っていて、これは結構よい。

jpskenn, 2024-08-30:
BaseとBottomを、ナット＋ワッシャー（2mm厚）でとめるってのもある。
この場合、Base基板は1.6mm厚にしておかないと、MXスイッチの真ん中の足が当たる。

懸念事項として、Base基板がたわんだときに、ソケットがBottomに当たって不快かもしれない。
自分のSandyは、たわみやすいところへ耐震ジェルかポロンのシートを挟んだ気がする。

jpskenn, 2024-08-30:
Bottom底面に貼るすべり止めを、1mmか0.5mmのゴムシートにする。

jpskenn, 2024-09-01:
ソケットやダイオードの逃し穴を開けたボトムプレートを、密着させる？
1.2mmか1.6mmボトムプレートで、ソケットとかは多少飛び出すが、ゴム脚とかで机には接しない、という感じ。

USBコネクタとケーブルハウジングが机に当たるかも？

jpskenn, 2024-09-06:
仮どめKOALA（仮どめコアラ）2mm [透明ゲル両面テープ 2mm厚 2m JK-01]
https://www.yodobashi.com/product/100000001006802083/

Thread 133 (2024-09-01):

Base基板：基板サイドからのLEDの光線漏れ対策

jpskenn, 2024-09-01:
ケースレスで使用する場合、サイドからの光線漏れがちょっと気になる。
ピンヘッダをLEDの周りに立てて、光を遮断？

jpskenn, 2024-09-01:
施工が面倒なのと、高さ2mmぴったりすぎて当たるのが嫌なので、スポンジシート（2mm厚、2-3mm幅、シール付）を貼る方がよい。

jpskenn, 2024-09-08:
1uのフォームで代用可能かも。

Kelowna プレート用静音フォーム
https://talpkeyboard.net/items/65d5c2ad70810903b47c1593

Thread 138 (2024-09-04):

とりあえず、今すぐ印刷して重ねてみろ！！

jpskenn, 2024-09-04:
配線に取り掛かりつつあるが、チェックが先だ！！

jpskenn, 2024-09-06:
基板間接続や穴、外形については特に問題なし。
Base用プレート左右端、付近にスイッチが取り付けられていないので、強度的に弱くてたわみそう。

別Issue立てた
→https://github.com/jpskenn/Sandy/issues/139

Closed 2024-09-06.

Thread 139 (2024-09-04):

Base用スイッチプレート　手前の左右端が弱そう

jpskenn, 2024-09-04:
手前の左右端（矢印部）にはスイッチが嵌っていないので、押さえたときにたわみそう。
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

BaseとBase用スイッチプレートの間に、スポンジシートなどを挟めばOK？
ミスミでいくつか試してみる。

jpskenn, 2024-09-06:
これ、3.5mm厚で良さそうかも。
https://www.yodobashi.com/product/100000001004000134/

jpskenn, 2024-09-06:
プレート用静音フォーム
https://talpkeyboard.net/items/65d5c2ad70810903b47c1593

Closed 2024-09-12.

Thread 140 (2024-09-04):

自前ケースに向けた布石

jpskenn, 2024-09-04:
すべての基板、スイッチプレート：左右0.5uの範囲に、パーツを配置しない。
Base基板：上0.5uの範囲に、パーツを配置しない。
Base以外の基板、スイッチプレート：左右0.5uを切り落とす（別の外径で製造する）。

これでBaseの左右と上、下の左右をケースで挟み込めば？

jpskenn, 2024-09-04:
MCUまわり（USBコネクタ付近）は0.5uあけとくのはつらい。
Base→Bottomのネジ穴を使って、後付けタブでケースに接続してもいい？

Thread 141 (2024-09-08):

ロープロ版「DN0040LP」

jpskenn, 2024-09-08:
スイッチをChoc V2にして、Cherryプロファイルなどと組み合わせて、ロープロ版とする。

Choc V2でMXキーキャップを使用する対応は、ここらへんを参考に。
https://74th.hateblo.jp/entry/chocv2-compatible-keycap

基板とスイッチプレート厚は1.2mm。
基板とスイッチプレート間は1mm。（と思われる。まだあまり調べておらず、Choc V1の知識。）
Top基板がMidスイッチプレートを兼ねているので、Topを高めにできないのでは？
（Mid基板をBaseスイッチプレート兼用にしたら、ちょっと安くなる？）

スイッチのフットプリント置き換えと、実装パーツ類の基板間クリアランスがポイント？

jpskenn, 2024-09-08:
Choc V2 data sheet
https://www.kailhswitch.com/Content/upload/pdf/202015927/PG135301D03.pdf
[PG135301D03.pdf](https://github.com/user-attachments/files/16923758/PG135301D03.pdf)

jpskenn, 2024-09-08:
通常版の構造

``` text
1.6mm   Top用スイッチプレート
3.4mm   スイッチ
1.6mm   Top基板 兼 Mid用スイッチプレート
3mm     スペーサー
1.6mm   Mid基板             1.6mm   Base用スイッチプレート
2mm     ナット＋ワッシャー   3.4mm   スイッチ
1.6mm   Base基板
3mm     スペーサー
1.6mm   ボトムプレート
```

jpskenn, 2024-09-09:
ミスミ　標準ウレタンシート　T=0.5mmあり
https://jp.misumi-ec.com/vona2/detail/110302682610/?rid=c14_detail_2_110302682610

jpskenn, 2024-09-09:
基板とスイッチプレートを兼用すると、Base、Mid、Topがそれぞれ2.2mmの段差になる。
Topの段差がちょっと足りないかも？

jpskenn, 2024-09-09:
既存の自作キーボードでは、スイッチプレートなしだったり、ありだったり。
スイッチプレートをつけると、キー押し下げ時にキーキャップの裾野（？）がプレートに当たるので、使えるキーキャップが減るとのこと。
https://discord.com/channels/376937950409392130/382560194917433345/810507548737929227

### スイッチプレートなし
- Ajisai74
- Sparrow62

### スイッチプレートあり
- おおやけさんのTrekなんとか
- Loflee
- Logicool MX Mechanical

jpskenn, 2024-09-09:
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

jpskenn, 2024-09-09:
キーキャップのギャップは、使用するキーキャップのプロファイル（試したのはDSS、Cherry、KATなど。KATはChoc V2だと無理な気がするが。）に合わせて、Base→Mid 3.6mm、Mid→Top 5.0mmに最適化してきた。
スイッチの形状が変わったとしても、指がかかるところは変わらないので、DN0040LPでも同じギャップにする。

実際に打鍵してみないとわからないが、スイッチのストロークが少なくなるので、それに起因するような調整が今後発生するかもしれない。

jpskenn, 2024-09-10:
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

jpskenn, 2024-09-10:
プレートあり・なしの判断ポイント
- プレートなしでも、スイッチがソケットでしっかり固定されるか？
  MXのソケットはちょっとゆるかったので、ソケット使うならプレートつけたい。
  `Ajisai74`がソケット使わずに半田付けさせてるのは、そういうところか？
- 使用予定のキーキャップ（DSS、Cherryなど）が、プレートに干渉するか？
- 設計の難易度？
  Mid用スイッチプレートはR2左右2キーが孤立することになるが、1枚の大きなプレートにしたらなんとかなりそう。

jpskenn, 2024-09-10:
Mid用プレートの中央部分、10*10cm基板でいけるのでは？
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

jpskenn, 2024-09-12:
Kailh Deep Sea MINIで、キーキャップの干渉をチェックした。

- DSS ハードヒットで、A行がうっすらスイッチに当たるかも。
- GMK Cherry ハードヒットでA行が確実に当たる。
- ePBT Cherry ハードヒットでA行ちょっと当たる。
- PBTfans？ Cherry ハードヒットでA行当たる。
- KAT まったく当たらない。

ハードヒットは、ッターン！！みたいな上から振り下ろすような感じのこと。
普通の打鍵だと、大して気にならないレベル。
また、いずれも、プレートには当たらない。

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

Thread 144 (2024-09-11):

R1の必要性？

jpskenn, 2024-09-11:
お仕事で使ってるとき、ESCとプリントスクリーンくらいしか使ってない。
もうR1なくても良いんでは？

残す理由としては、
- 余ったキーキャップを置いておくところ
- マクロ用の何か
- 片手で数字を入力する
とか？

jpskenn, 2024-09-11:
R1を無くすと、Midが完全に孤立してしまうのでけっこうつらい。
孤立部分をネジ3-4本で支えるとして、ネジ導通するならまぁなんとかなりそう？
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

jpskenn, 2024-09-11:
Mid基板、ネジを綺麗に四隅へ配置するのは、ちょっとしんどい？
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

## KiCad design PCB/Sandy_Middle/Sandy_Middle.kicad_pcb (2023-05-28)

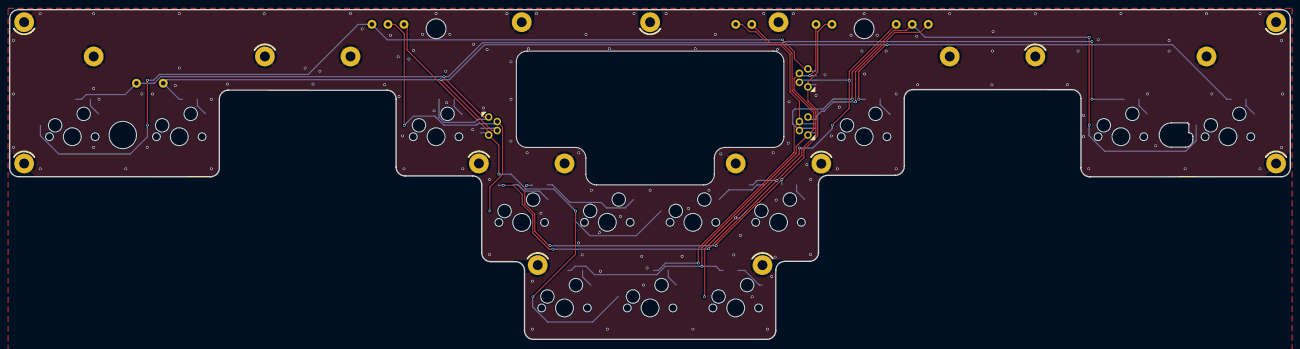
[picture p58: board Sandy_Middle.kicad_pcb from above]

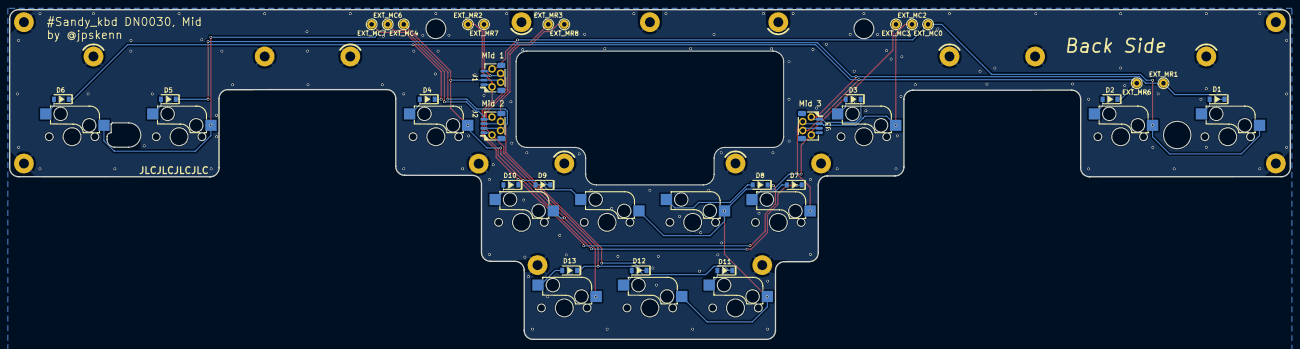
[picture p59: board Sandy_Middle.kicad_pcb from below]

Board: 2 copper layers, 285.0 x 73.4 mm, 61 parts (36 on the bottom side), 26 nets.

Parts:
Cutout1: 60_Outline; 60_Outline-Sandy-Mid7-narrow-bottom-small-right-hole
D1, D2, D3, D4, D5, D6, D7, D8, D9, D10, D11, D12, D13: D; D_SOD-123_Emphasized_Direction_Line
EXT_MC0, EXT_MC2, EXT_MC3, EXT_MC4, EXT_MC6, EXT_MC7: Conn_01x01; TestPoint_THTPad_D2.0mm_Drill1.0mm
EXT_MR1, EXT_MR2, EXT_MR3, EXT_MR6, EXT_MR7, EXT_MR8: Conn_01x01; TestPoint_THTPad_D2.0mm_Drill1.0mm
H1, H2, H3, H4, H5, H6, H7, H8, H9, H10, H11, H12, H13, H14, H15, H16, H17, H18, H19: MountingHole; MountingHole_2.2mm_M2_Pad_minimal
J1, J2, J3: Conn_02x02_Top_Bottom; JST_SH_SM04B-SRSS-TB_1x04-1MP_P1.00mm_Horizontal_wCable_hou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
SW_'1: SW_Push; MXOnly-1U-Hotswap-guide
SW_;1: SW_Push; MXOnly-1U-Hotswap-guide
SW_BS1.5u1: SW_Push; MXOnly-1.5U-Hotswap-guide
SW_G1: SW_Push; MXOnly-1U-Hotswap-guide
SW_H1: SW_Push; MXOnly-1U-Hotswap-guide
SW_P1: SW_Push; MXOnly-1U-Hotswap-guide
SW_Q1: SW_Push; MXOnly-1U-Hotswap-guide
SW_R1, SW_R4CenterC1, SW_R4CenterL1, SW_R4CenterR1: SW_Push; MXOnly-1U-Hotswap-guide
SW_TAB1.5u1: SW_Push; MXOnly-1.5U-Hotswap-guide
SW_U1: SW_Push; MXOnly-1U-Hotswap-guide

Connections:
Mid_GND: H1.1, H2.1, H3.1, H4.1, H5.1, H6.1, H7.1, H8.1, H9.1, H10.1, H11.1, H12.1, H13.1, H14.1, H15.1, H16.1, H17.1, H18.1, H19.1
Mid_col0: EXT_MC0.1, J1.4, SW_Q1.1, SW_TAB1.5u1.1
Mid_col2: EXT_MC2.1, J3.2, SW_G1.1, SW_R1.1
Mid_col3: EXT_MC3.1, J3.4, SW_'1.1, SW_;1.1, SW_R4CenterC1.1, SW_R4CenterL1.1
Mid_col4: EXT_MC4.1, J1.2, SW_H1.1, SW_R4CenterR1.1, SW_U1.1
Mid_col6: EXT_MC6.1, J2.2, SW_BS1.5u1.1, SW_P1.1
Mid_col7: EXT_MC7.1, J2.4
Mid_row1: D1.1 (K), D3.1 (K), D5.1 (K), EXT_MR1.1, J3.1
Mid_row2: D8.1 (K), D10.1 (K), EXT_MR2.1, J1.1
Mid_row3: D11.1 (K), D13.1 (K), EXT_MR3.1, J2.1
Mid_row6: D2.1 (K), D4.1 (K), D6.1 (K), EXT_MR6.1, J3.3
Mid_row7: D7.1 (K), D9.1 (K), EXT_MR7.1, J1.3
Mid_row8: D12.1 (K), EXT_MR8.1, J2.3
unnamed: D1.2 (A), SW_TAB1.5u1.2
unnamed: D2.2 (A), SW_Q1.2
unnamed: D3.2 (A), SW_R1.2
unnamed: D4.2 (A), SW_U1.2
unnamed: D5.2 (A), SW_P1.2
unnamed: D6.2 (A), SW_BS1.5u1.2
unnamed: D7.2 (A), SW_G1.2
unnamed: D8.2 (A), SW_;1.2
unnamed: D9.2 (A), SW_'1.2
unnamed: D10.2 (A), SW_H1.2
unnamed: D11.2 (A), SW_R4CenterL1.2
unnamed: D12.2 (A), SW_R4CenterC1.2
unnamed: D13.2 (A), SW_R4CenterR1.2

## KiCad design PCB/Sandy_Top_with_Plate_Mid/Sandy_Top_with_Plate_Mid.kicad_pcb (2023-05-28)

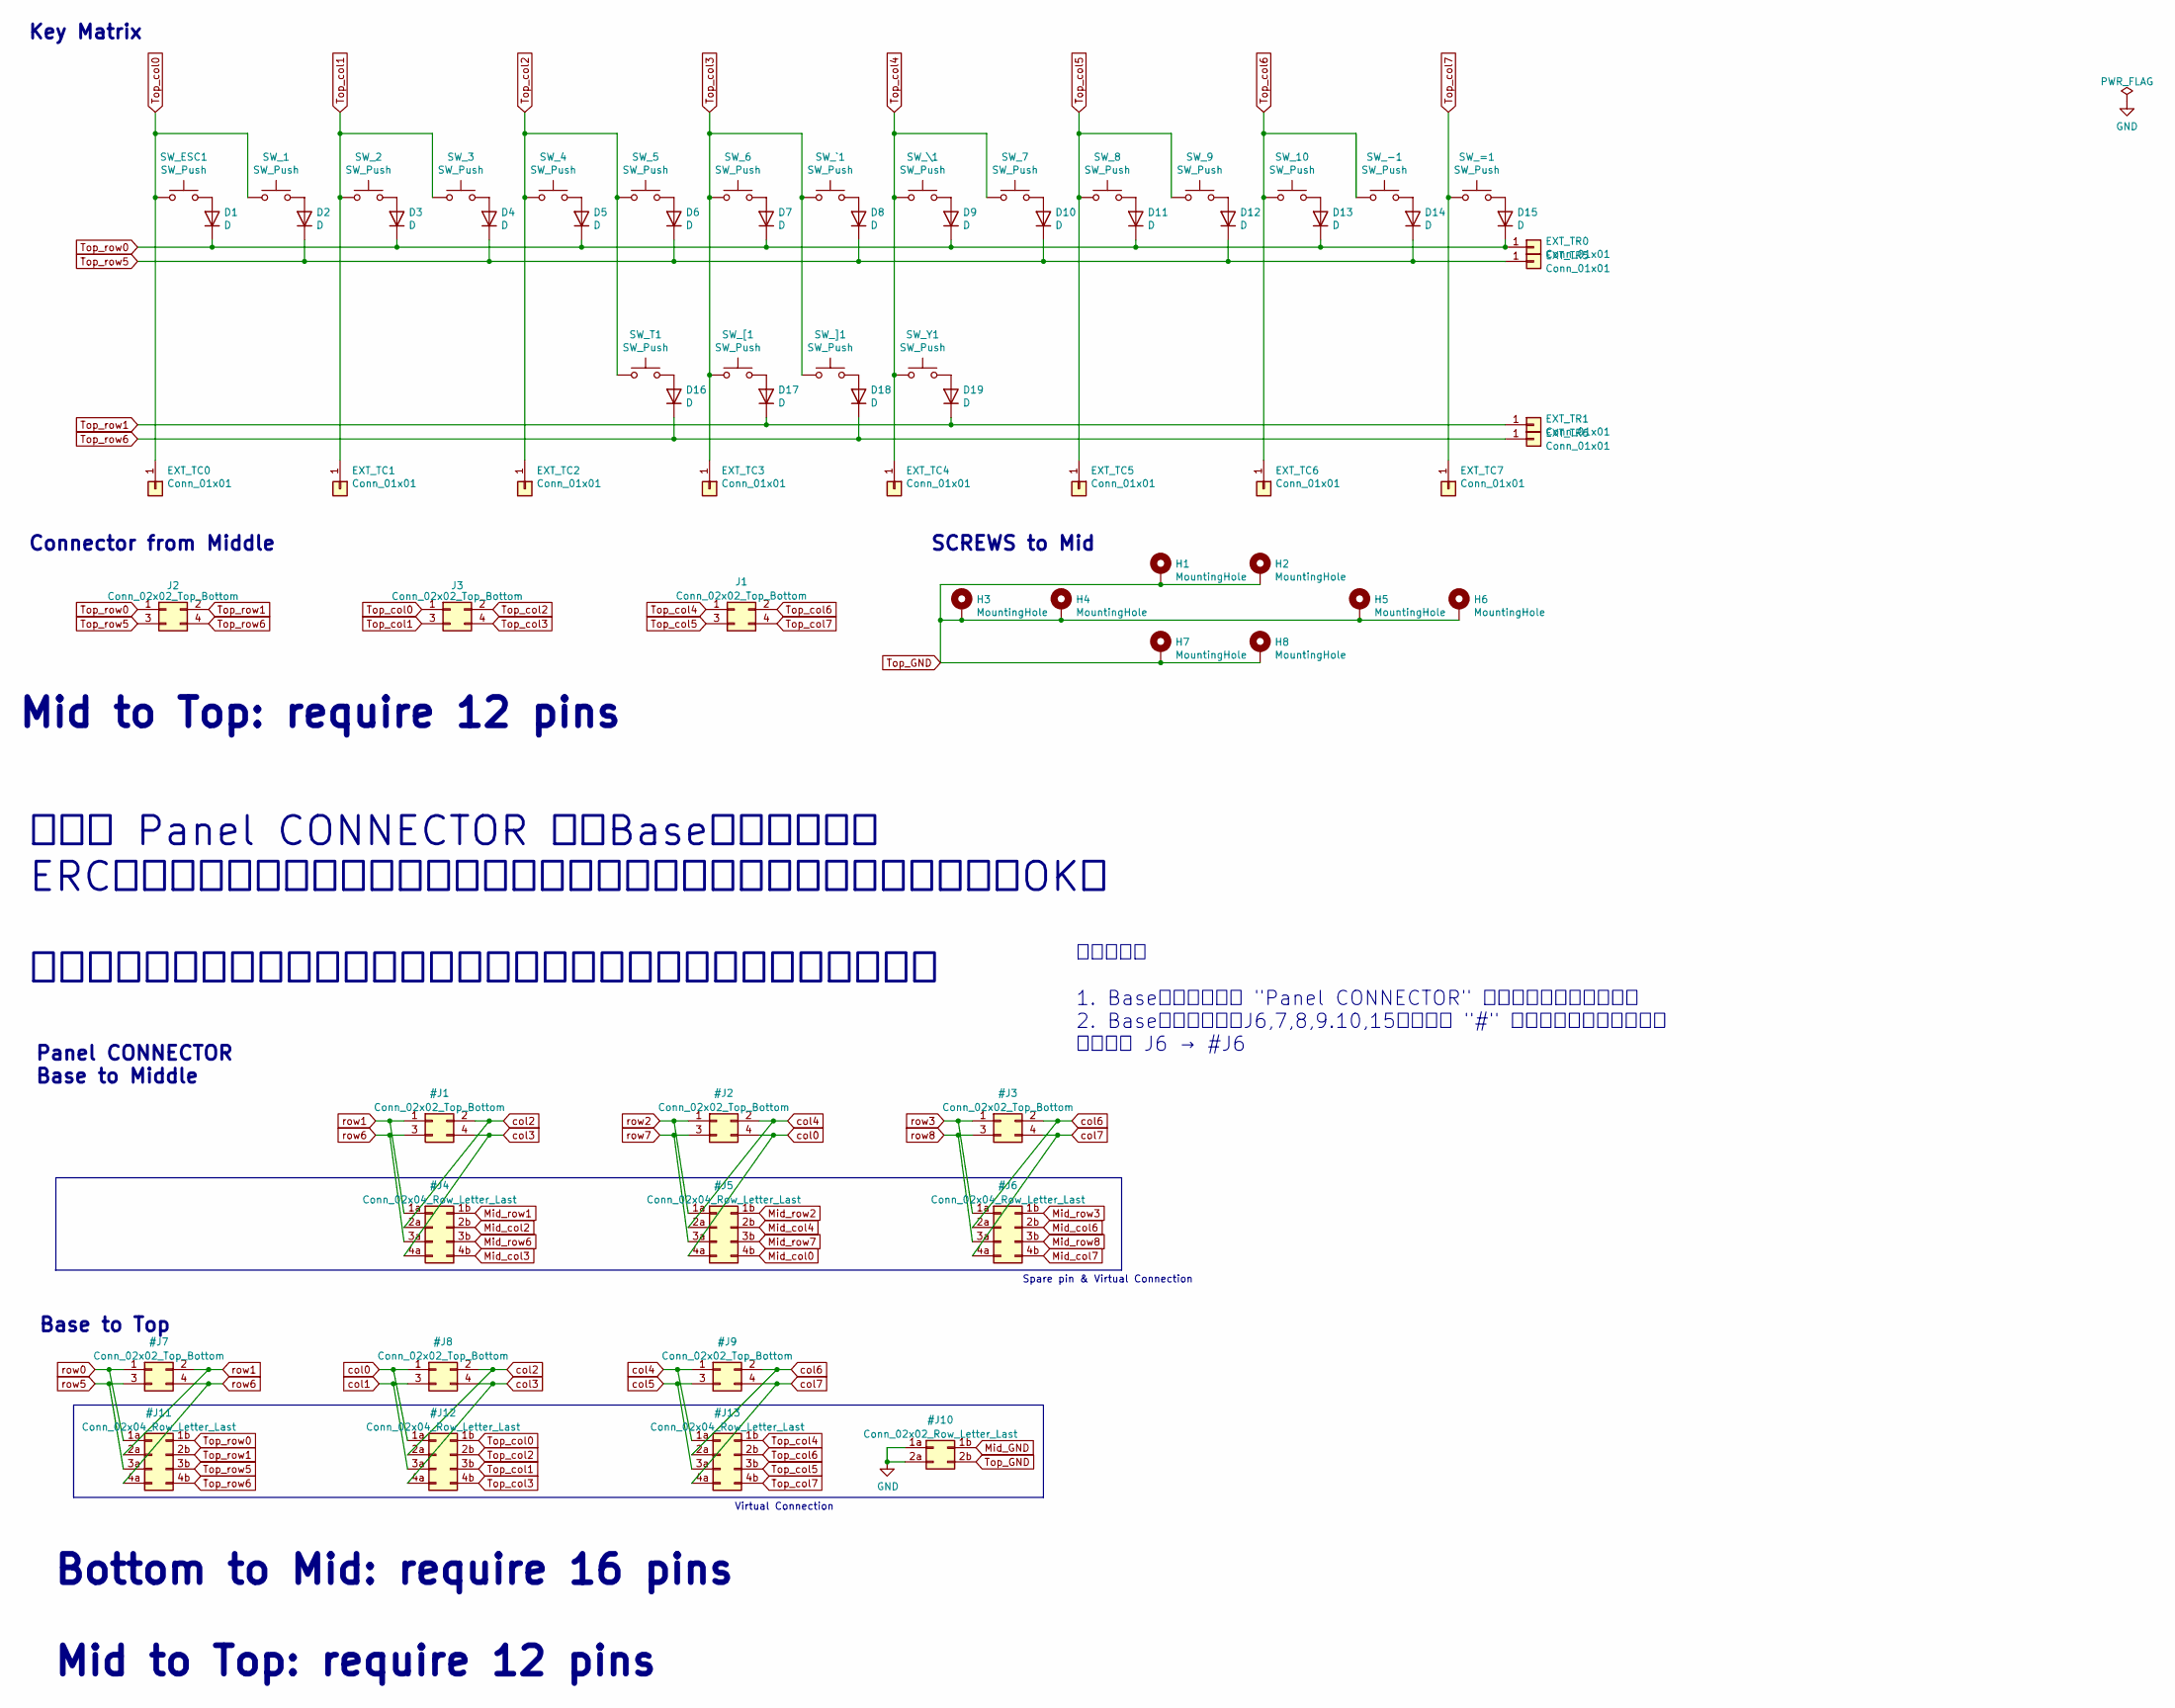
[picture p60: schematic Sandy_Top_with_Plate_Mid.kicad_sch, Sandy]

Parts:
D1, D2, D3, D4, D5, D6, D7, D8, D9, D10, D11, D12, D13, D14, D15, D16, D17, D18, D19: D; D_SOD-123_Emphasized_Direction_Line; LCSC C81598
EXT_TC0, EXT_TC1, EXT_TC2, EXT_TC3, EXT_TC4, EXT_TC5, EXT_TC6, EXT_TC7: Conn_01x01; TestPoint_THTPad_D2.0mm_Drill1.0mm
EXT_TR0, EXT_TR1, EXT_TR5, EXT_TR6: Conn_01x01; TestPoint_THTPad_D2.0mm_Drill1.0mm
H1, H2, H3, H4, H5, H6, H7, H8: MountingHole; MountingHole_2.2mm_M2_Pad_minimal
J1, J2, J3: Conn_02x02_Top_Bottom; JST_SH_SM04B-SRSS-TB_1x04-1MP_P1.00mm_Horizontal_wCable_hou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; LCSC C371510
SW_1, SW_2, SW_3, SW_4, SW_7, SW_9, SW_10: SW_Push; MXOnly-1U-Hotswap-guide
SW_5: SW_Push; MXOnly-1U-Hotswap-screw-hole-side2-guide
SW_6: SW_Push; MXOnly-1U-Hotswap-screw-hole-side1-guide
SW_8: SW_Push; MXOnly-1U-Hotswap-screw-hole-side3-guide
SW_-1: SW_Push; MXOnly-1U-Hotswap-guide
SW_=1: SW_Push; MXOnly-1U-Hotswap-guide
SW_ESC1: SW_Push; MXOnly-1U-Hotswap-guide
SW_T1: SW_Push; MXOnly-1U-Hotswap-guide
SW_Y1: SW_Push; MXOnly-1U-Hotswap-guide
SW_[1: SW_Push; MXOnly-1U-Hotswap-guide
SW_\1: SW_Push; MXOnly-1U-Hotswap-guide
SW_]1: SW_Push; MXOnly-1U-Hotswap-guide
SW_`1: SW_Push; MXOnly-1U-Hotswap-guide

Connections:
unnamed: D1.2 (A), SW_ESC1.2
unnamed: D2.2 (A), SW_1.2
unnamed: D3.2 (A), SW_2.2
unnamed: D4.2 (A), SW_3.2
unnamed: D5.2 (A), SW_4.2
unnamed: D6.2 (A), SW_5.2
unnamed: D7.2 (A), SW_6.2
unnamed: D8.2 (A), SW_`1.2
unnamed: D9.2 (A), SW_\1.2
unnamed: D10.2 (A), SW_7.2
unnamed: D11.2 (A), SW_8.2
unnamed: D12.2 (A), SW_9.2
unnamed: D13.2 (A), SW_10.2
unnamed: D14.2 (A), SW_-1.2
unnamed: D15.2 (A), SW_=1.2
unnamed: D16.2 (A), SW_T1.2
unnamed: D17.2 (A), SW_[1.2
unnamed: D18.2 (A), SW_]1.2
unnamed: D19.2 (A), SW_Y1.2
Top_GND: H1.1, H2.1, H3.1, H4.1, H5.1, H6.1, H7.1, H8.1

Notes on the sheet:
Mid to Top: require 12 pins
Connector from Middle
Virtual Connection
Spare pin & Virtual Connection
SCREWS to Mid
Bottom to Mid: require 16 pins Mid to Top: require 12 pins
Panel CONNECTOR Base to Middle
以下の Panel CONNECTOR は、Baseからコピペ。 ERCの警告「別パネルのラベルがどこにも接続されていない」は、無視してOK。 ！！！他の警告（ラベルかぶりとか）は、しっかりチェックせよ！！！
Base to Top
コピペ手順 1. Baseの回路図から "Panel CONNECTOR" の箇所をまるごとコピペ 2. Baseのコネクタ（J6,7,8,9.10,15）の頭に "#" をつけて仮想シンボル化 例： J6 → #J6
Key Matrix

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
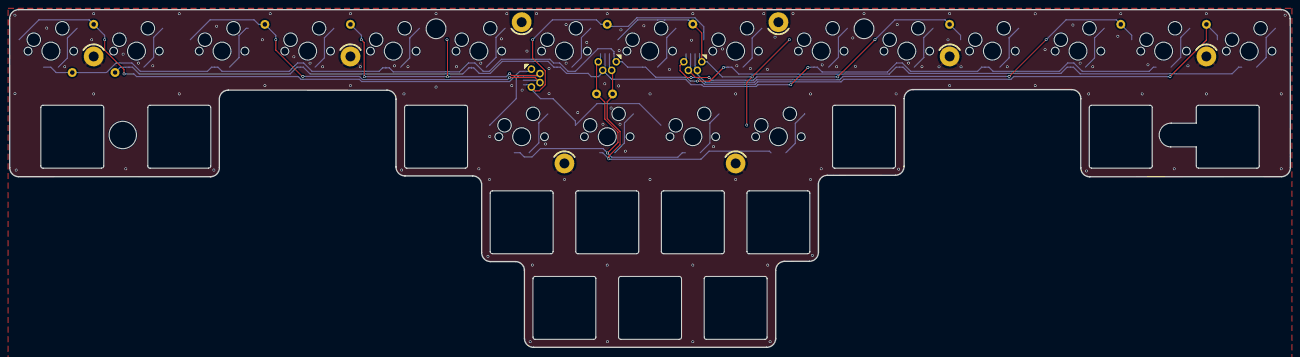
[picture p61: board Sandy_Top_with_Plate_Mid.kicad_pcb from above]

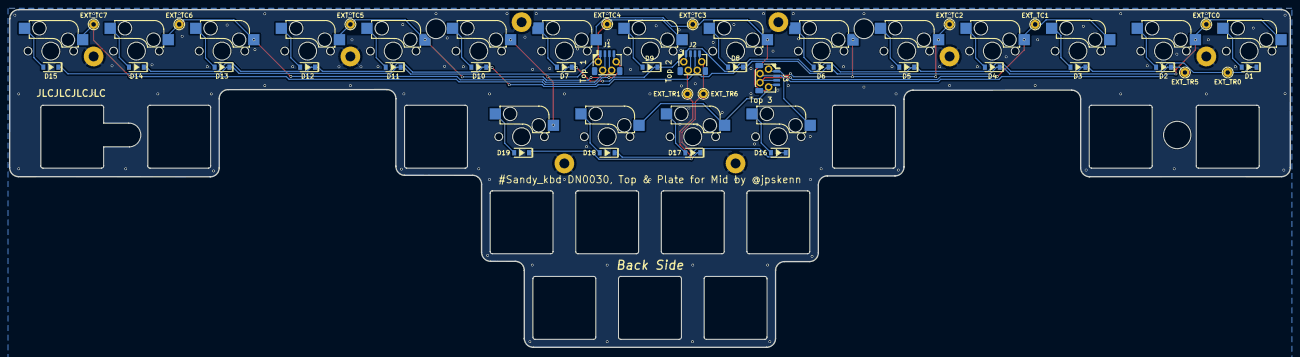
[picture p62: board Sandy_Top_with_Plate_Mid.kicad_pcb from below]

Board: 2 copper layers, 285.0 x 75.1 mm, 61 parts (34 on the bottom side), 32 nets.

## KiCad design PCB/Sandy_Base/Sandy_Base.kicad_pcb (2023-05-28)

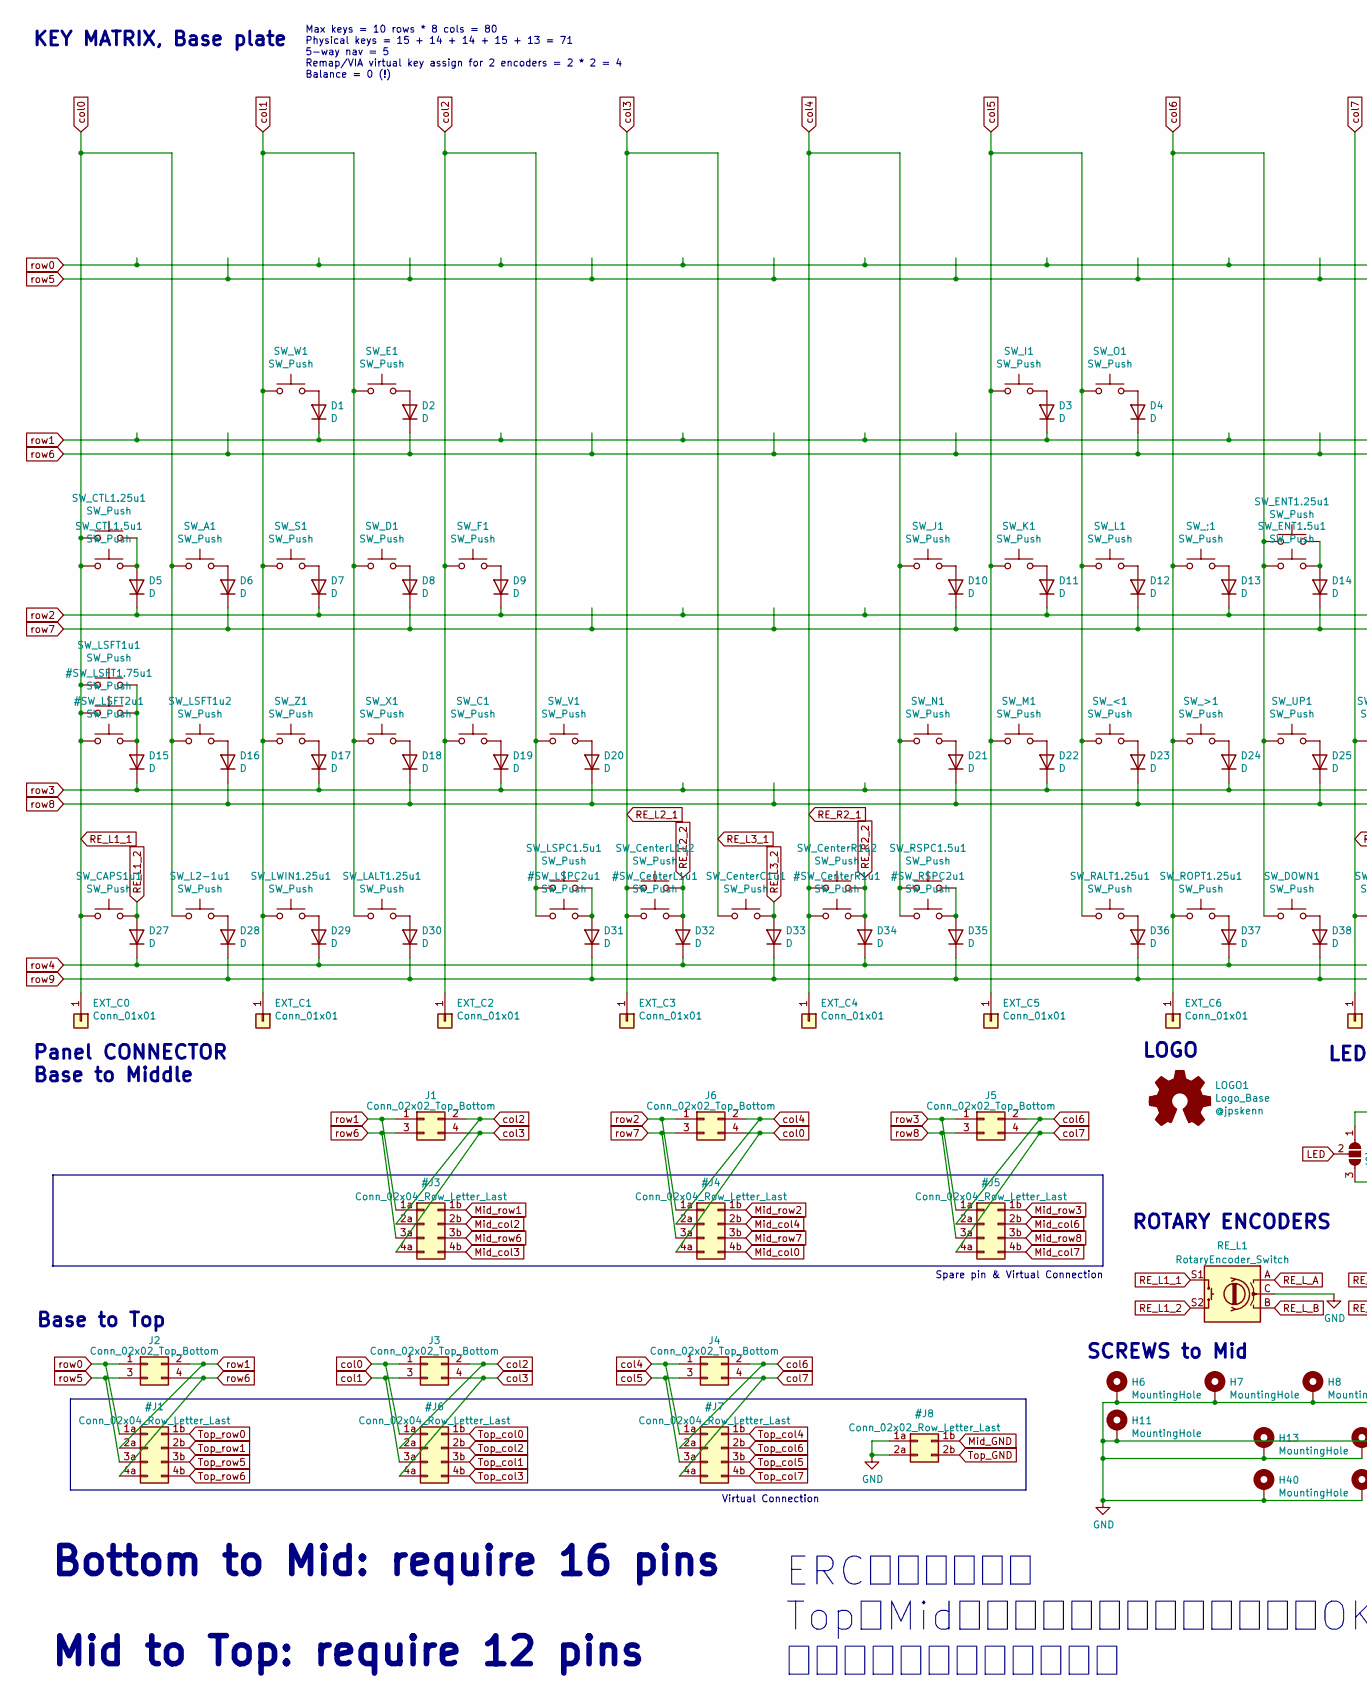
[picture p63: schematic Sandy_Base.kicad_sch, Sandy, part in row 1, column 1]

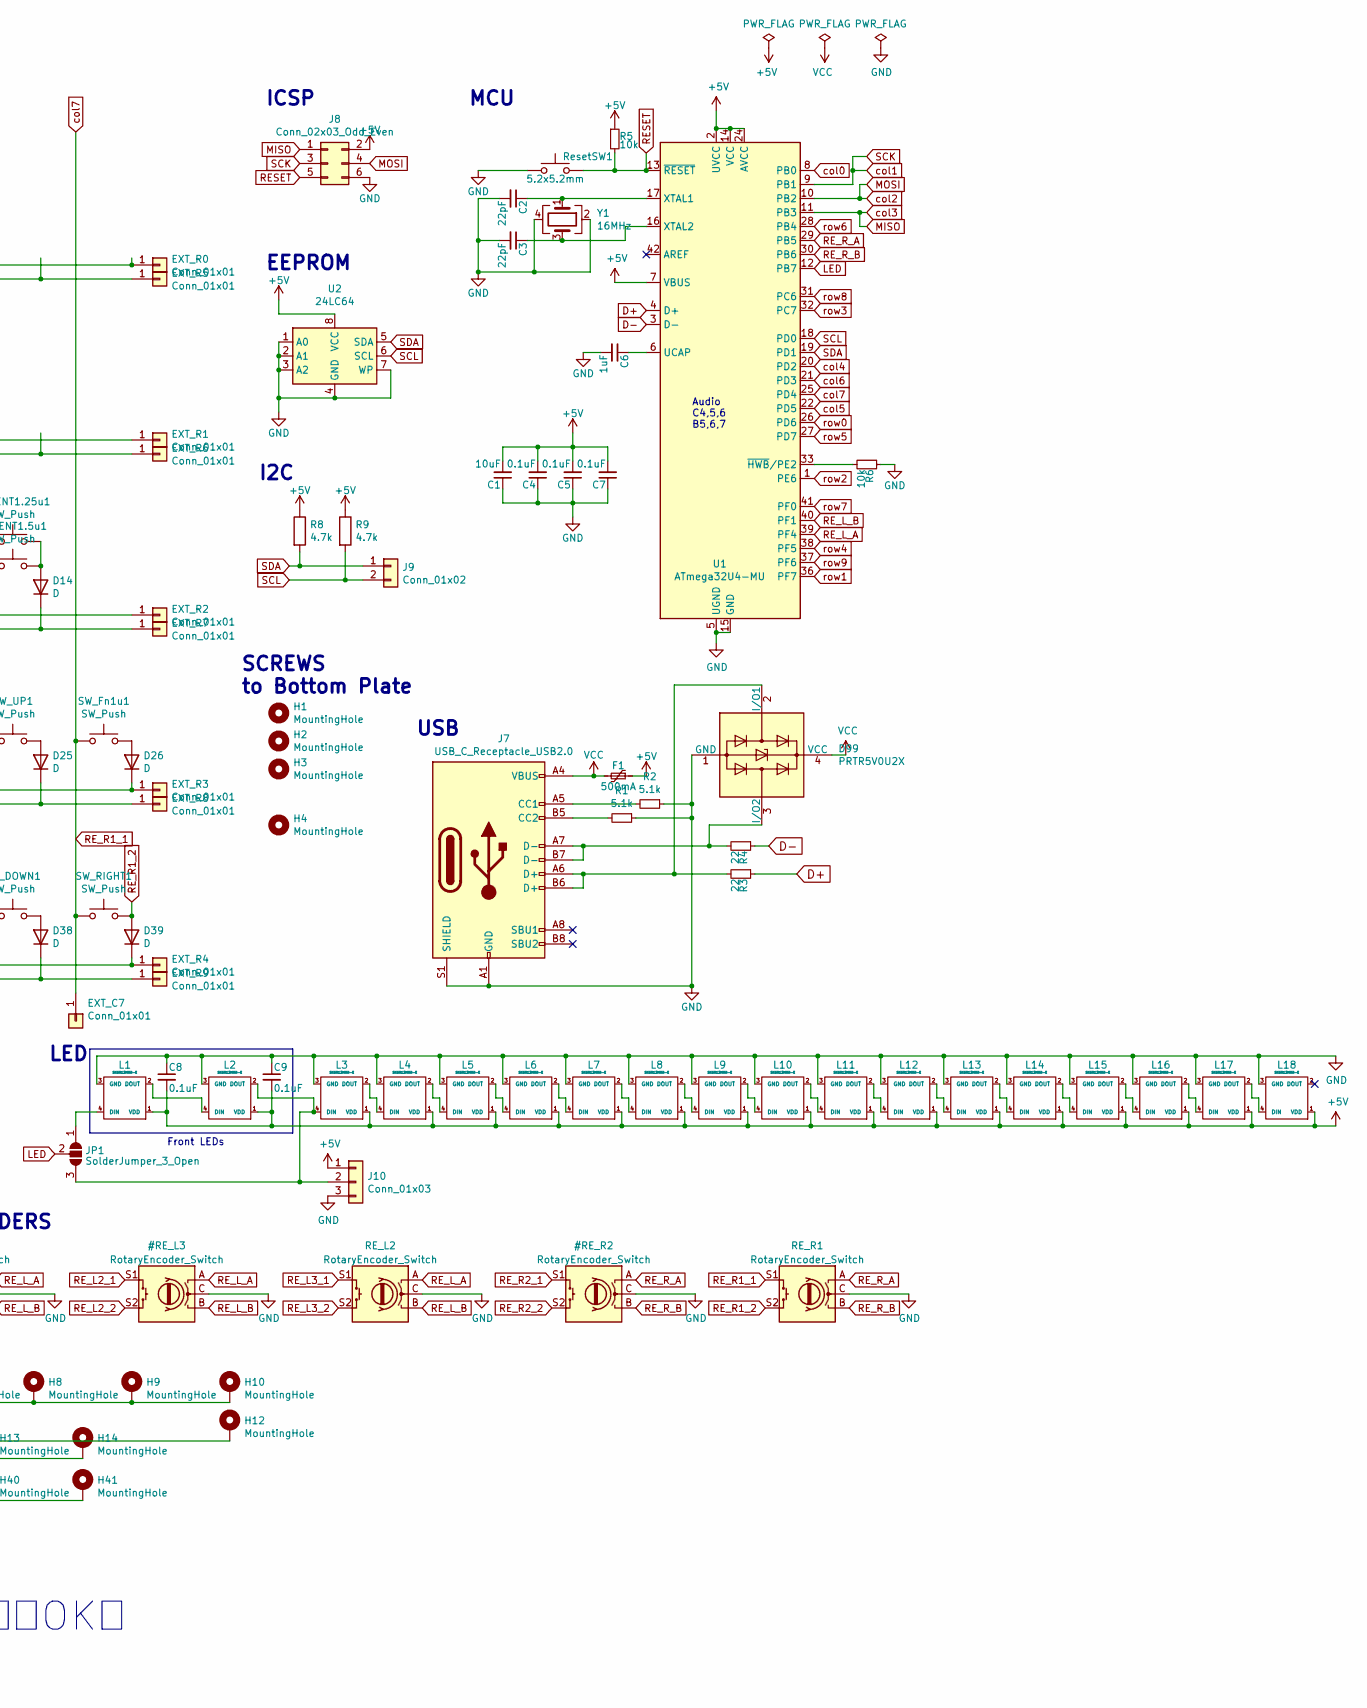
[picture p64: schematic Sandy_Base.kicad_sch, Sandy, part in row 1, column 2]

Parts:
C1: 10uF; C_0805_2012Metric; LCSC C15850
C2, C3: 22pF; C_0805_2012Metric; LCSC C1804
C4, C5, C7, C8, C9: 0.1uF; C_0805_2012Metric; LCSC C49678
C6: 1uF; C_0805_2012Metric; LCSC C28323
D1, D2, D3, D4, D5, D6, D7, D8, D9, D10, D11, D12, D13, D14, D15, D16, D17, D18, D19, D20, D21, D22, D23, D24, D25, D26, D27, D28, D29, D30, D31, D32, D33, D34, D35, D36, D37, D38, D39: D; D_SOD-123_Emphasized_Direction_Line_Reference_on_bottom; LCSC C81598
D99: PRTR5V0U2X; SOT-143_Handsoldering; LCSC C78442
EXT_C0, EXT_C1, EXT_C2, EXT_C3, EXT_C4, EXT_C5, EXT_C6, EXT_C7: Conn_01x01; TestPoint_THTPad_D2.0mm_Drill1.0mm
EXT_R0, EXT_R1, EXT_R2, EXT_R3, EXT_R4, EXT_R5, EXT_R6, EXT_R7, EXT_R8, EXT_R9: Conn_01x01; TestPoint_THTPad_D2.0mm_Drill1.0mm
F1: 500mA; Fuse_1206_3216Metric_Pad1.42x1.75mm_HandSolder; LCSC C70076
H1, H2, H3, H4: MountingHole; MountingHole_2.2mm_M2_No_Cu
H6, H7, H8, H9, H10, H11, H12, H13, H14, H40, H41: MountingHole; MountingHole_2.2mm_M2_Pad_minimal
J1, J2, J3, J4, J5, J6: Conn_02x02_Top_Bottom; JST_SH_SM04B-SRSS-TB_1x04-1MP_P1.00mm_Horizontal_wCable_hou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; LCSC C371510
J7: USB_C_Receptacle_USB2.0; USB_C_Receptacle_HRO_TYPE-C-31-M-12; LCSC C165948
J8: Conn_02x03_Odd_Even; PinHeader_2x03_P2.54mm_Vertical
J9: Conn_01x02; PinHeader_1x02_P2.54mm_Vertical
J10: Conn_01x03; PinHeader_1x03_P2.54mm_Vertical
JP1: SolderJumper_3_Open; SolderJumper-3_P1.3mm_Open_RoundedPad1.0x1.5mm
L1, L2, L3, L4, L5, L6, L7, L8, L9, L10, L11, L12, L13, L14, L15, L16, L17, L18: SK6812MINI-E; YS-SK6812MINI-E_middle_hole_with_small_pad
LOGO1: Logo_Base; Sandy_logo_w60_new
R1, R2: 5.1k; R_0805_2012Metric; LCSC C27834
R3, R4: 22; R_0805_2012Metric; LCSC C17561
R5, R6: 10k; R_0805_2012Metric; LCSC C17414
R8, R9: 4.7k; R_0805_2012Metric; LCSC C17673
RE_L1, RE_L2: RotaryEncoder_Switch; RotaryEncoder_Alps_EC11K-Switch_Vertical_H20mm_NPTH_MP_mini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
RE_R1: RotaryEncoder_Switch; RotaryEncoder_Alps_EC11K-Switch_Vertical_H20mm_NPTH_MP_mini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
ResetSW1: 5.2x5.2mm; SW_SPST_TL3342
SW_;1: SW_Push; MXOnly-1U-Hotswap-guide
SW_<1: SW_Push; MXOnly-1U-Hotswap-guide
SW_>1: SW_Push; MXOnly-1U-Hotswap-guide
SW_A1: SW_Push; MXOnly-1U-Hotswap-guide
SW_C1: SW_Push; MXOnly-1U-Hotswap-guide
SW_CAPS1u1: SW_Push; MXOnly-1U-Hotswap-on-RE-guide
SW_CTL1.5u1: SW_Push; MXOnly-1.5U-Hotswap-guide
SW_CTL1.25u1: SW_Push; MXOnly-1.25U-Hotswap-guide
SW_CenterC1u1: SW_Push; MXOnly-1U-Hotswap-on-RE-guide
SW_CenterL1u2: SW_Push; MXOnly-1U-Hotswap-guide
SW_CenterR1u2: SW_Push; MXOnly-1U-Hotswap-guide
SW_D1: SW_Push; MXOnly-1U-Hotswap-guide
SW_DOWN1: SW_Push; MXOnly-1U-Hotswap-guide
SW_E1: SW_Push; MXOnly-1U-Hotswap-guide
SW_ENT1.5u1: SW_Push; MXOnly-1.5U-Hotswap-guide
SW_ENT1.25u1: SW_Push; MXOnly-1.25U-Hotswap-guide
SW_F1: SW_Push; MXOnly-1U-Hotswap-guide
SW_Fn1u1: SW_Push; MXOnly-1U-Hotswap-guide
SW_I1: SW_Push; MXOnly-1U-Hotswap-guide
SW_J1: SW_Push; MXOnly-1U-Hotswap-guide
SW_K1: SW_Push; MXOnly-1U-Hotswap-guide
SW_L1, SW_L2-1u1: SW_Push; MXOnly-1U-Hotswap-guide
SW_LALT1.25u1: SW_Push; MXOnly-1.25U-Hotswap-guide
SW_LSFT1u1, SW_LSFT1u2: SW_Push; MXOnly-1U-Hotswap-guide
SW_LSPC1.5u1: SW_Push; MXOnly-1.5U-Hotswap-guide
SW_LWIN1.25u1: SW_Push; MXOnly-1.25U-Hotswap-guide
SW_M1: SW_Push; MXOnly-1U-Hotswap-guide
SW_N1: SW_Push; MXOnly-1U-Hotswap-guide
SW_O1: SW_Push; MXOnly-1U-Hotswap-guide
SW_RALT1.25u1: SW_Push; MXOnly-1.25U-Hotswap-guide
SW_RIGHT1: SW_Push; MXOnly-1U-Hotswap-on-RE-guide
SW_ROPT1.25u1: SW_Push; MXOnly-1.25U-Hotswap-guide
SW_RSPC1.5u1: SW_Push; MXOnly-1.5U-Hotswap-guide
SW_S1: SW_Push; MXOnly-1U-Hotswap-guide
SW_UP1: SW_Push; MXOnly-1U-Hotswap-guide
SW_V1: SW_Push; MXOnly-1U-Hotswap-guide
SW_W1: SW_Push; MXOnly-1U-Hotswap-guide
SW_X1: SW_Push; MXOnly-1U-Hotswap-guide
SW_Z1: SW_Push; MXOnly-1U-Hotswap-guide
U1: ATmega32U4-MU; QFN-44-1EP_7x7mm_P0.5mm_EP5.2x5.2mm; LCSC C45874
U2: 24LC64; SO-8_3.9x4.9mm_P1.27mm; LCSC C79988
Y1: 16MHz; Crystal_SMD_3225-4Pin_3.2x2.5mm_HandSoldering; LCSC C13738

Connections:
+5V: C1.2, C4.2, C5.2, C7.2, C8.2, C9.2, F1.1, J8.2, J10.1, L1.1 (VDD), L2.1 (VDD), L3.1 (VDD), L4.1 (VDD), L5.1 (VDD), L6.1 (VDD), L7.1 (VDD), L8.1 (VDD), L9.1 (VDD), L10.1 (VDD), L11.1 (VDD), L12.1 (VDD), L13.1 (VDD), L14.1 (VDD), L15.1 (VDD), L16.1 (VDD), L17.1 (VDD), L18.1 (VDD), R5.1, R8.1, R9.1, U1.2 (UVCC), U1.7 (VBUS), U1.14 (VCC), U1.24 (AVCC), U1.34 (VCC), U1.44 (AVCC), U2.8 (VCC)
D+: R3.1, U1.4 (D+)
D-: R4.1, U1.3 (D-)
LED: JP1.2 (C), U1.12 (PB7)
unnamed: D1.2 (A), SW_W1.2
unnamed: D2.2 (A), SW_E1.2
unnamed: D3.2 (A), SW_I1.2
unnamed: D4.2 (A), SW_O1.2
unnamed: D5.2 (A), SW_CTL1.5u1.2, SW_CTL1.25u1.2
unnamed: D6.2 (A), SW_A1.2
unnamed: D7.2 (A), SW_S1.2
unnamed: D8.2 (A), SW_D1.2
unnamed: D9.2 (A), SW_F1.2
unnamed: D10.2 (A), SW_J1.2
unnamed: D11.2 (A), SW_K1.2
unnamed: D12.2 (A), SW_L1.2
unnamed: D13.2 (A), SW_;1.2
unnamed: D14.2 (A), SW_ENT1.5u1.2, SW_ENT1.25u1.2
unnamed: D16.2 (A), SW_LSFT1u2.2
unnamed: D17.2 (A), SW_Z1.2
unnamed: D18.2 (A), SW_X1.2
unnamed: D19.2 (A), SW_C1.2
unnamed: D20.2 (A), SW_V1.2
unnamed: D21.2 (A), SW_N1.2
unnamed: D22.2 (A), SW_M1.2
unnamed: D23.2 (A), SW_<1.2
unnamed: D24.2 (A), SW_>1.2
unnamed: D25.2 (A), SW_UP1.2
unnamed: D26.2 (A), SW_Fn1u1.2
unnamed: D28.2 (A), SW_L2-1u1.2
unnamed: D29.2 (A), SW_LWIN1.25u1.2
unnamed: D30.2 (A), SW_LALT1.25u1.2
unnamed: D36.2 (A), SW_RALT1.25u1.2
unnamed: D37.2 (A), SW_ROPT1.25u1.2
unnamed: D38.2 (A), SW_DOWN1.2
unnamed: D99.2 (I/O1), J7.A6 (D+), J7.B6 (D+), R3.2
unnamed: D99.3 (I/O2), J7.A7 (D-), J7.B7 (D-), R4.2
unnamed: J7.A5 (CC1), R2.2
unnamed: J7.B5 (CC2), R1.2
unnamed: J10.2, JP1.3 (B), L2.2 (DOUT), L3.4 (DIN)
unnamed: JP1.1 (A), L1.4 (DIN)
unnamed: L1.2 (DOUT), L2.4 (DIN)
unnamed: L3.2 (DOUT), L4.4 (DIN)
unnamed: L4.2 (DOUT), L5.4 (DIN)
unnamed: L5.2 (DOUT), L6.4 (DIN)
unnamed: L6.2 (DOUT), L7.4 (DIN)
unnamed: L7.2 (DOUT), L8.4 (DIN)
unnamed: L8.2 (DOUT), L9.4 (DIN)
unnamed: L9.2 (DOUT), L10.4 (DIN)
unnamed: L10.2 (DOUT), L11.4 (DIN)
unnamed: L11.2 (DOUT), L12.4 (DIN)
unnamed: L12.2 (DOUT), L13.4 (DIN)
unnamed: L13.2 (DOUT), L14.4 (DIN)
unnamed: L14.2 (DOUT), L15.4 (DIN)
unnamed: L15.2 (DOUT), L16.4 (DIN)
unnamed: L16.2 (DOUT), L17.4 (DIN)
unnamed: L17.2 (DOUT), L18.4 (DIN)
unnamed: C6.1, U1.6 (UCAP)
unnamed: C2.1, U1.17 (XTAL1), Y1.1
unnamed: C3.1, U1.16 (XTAL2), Y1.3
unnamed: R6.2, U1.33 (~HWB/PE2)
RESET: J8.5, R5.2, ResetSW1.2, U1.13 (~RESET)
RE_L1_2: D27.2 (A), RE_L1.S2, SW_CAPS1u1.2
RE_L3_2: D33.2 (A), RE_L2.S2, SW_CenterC1u1.2
RE_R1_2: D39.2 (A), RE_R1.S2, SW_RIGHT1.2
SCL: J9.2, R9.2, U1.18 (PD0), U2.6 (SCL)
SDA: J9.1, R8.2, U1.19 (PD1), U2.5 (SDA)
VCC: D99.4 (VCC), F1.2, J7.A4 (VBUS), J7.A9 (VBUS), J7.B4 (VBUS), J7.B9 (VBUS)
row4: D27.1 (K), D29.1 (K), D32.1 (K), D34.1 (K), D37.1 (K), D39.1 (K), EXT_R4.1, U1.38 (PF5)
row9: D28.1 (K), D30.1 (K), D31.1 (K), D33.1 (K), D35.1 (K), D36.1 (K), D38.1 (K), EXT_R9.1, U1.37 (PF6)

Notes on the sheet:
SCREWS to Mid
SCREWS to Bottom Plate
ICSP
Virtual Connection
Spare pin & Virtual Connection
Bottom to Mid: require 16 pins Mid to Top: require 12 pins
Panel CONNECTOR Base to Middle
Audio C4,5,6 B5,6,7
MCU
USB
LOGO
EEPROM
Base to Top
LED
Front LEDs
ERCチェックで、 TopとMidのラベルが見つからないのはOK。 （別プロジェクトでやる）
KEY MATRIX, Base plate
I2C
ROTARY ENCODERS
Max keys = 10 rows * 8 cols = 80 Physical keys = 15 + 14 + 14 + 15 + 13 = 71 5-way nav = 5 Remap/VIA virtual key assign for 2 encoders = 2 * 2 = 4 Balance = 0 (!)

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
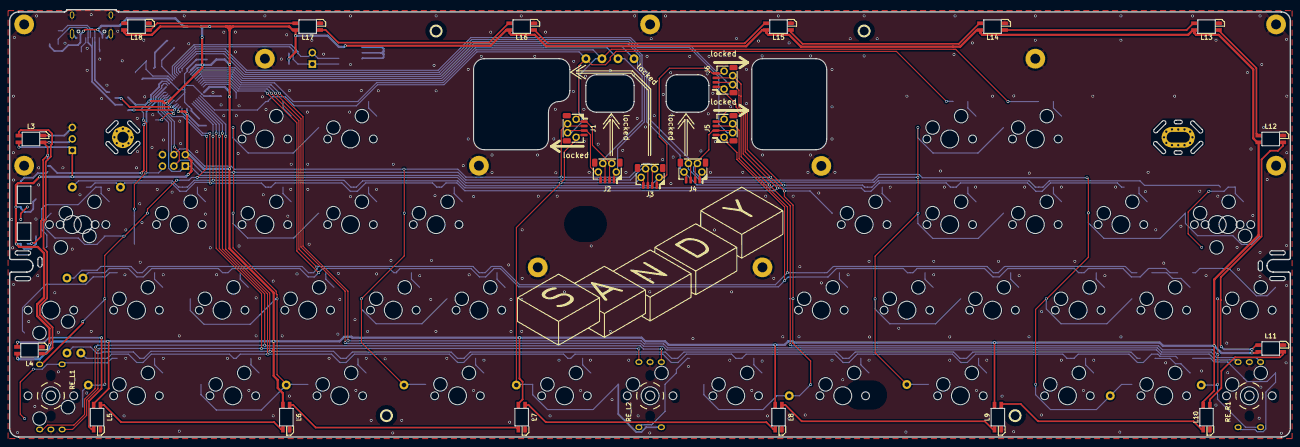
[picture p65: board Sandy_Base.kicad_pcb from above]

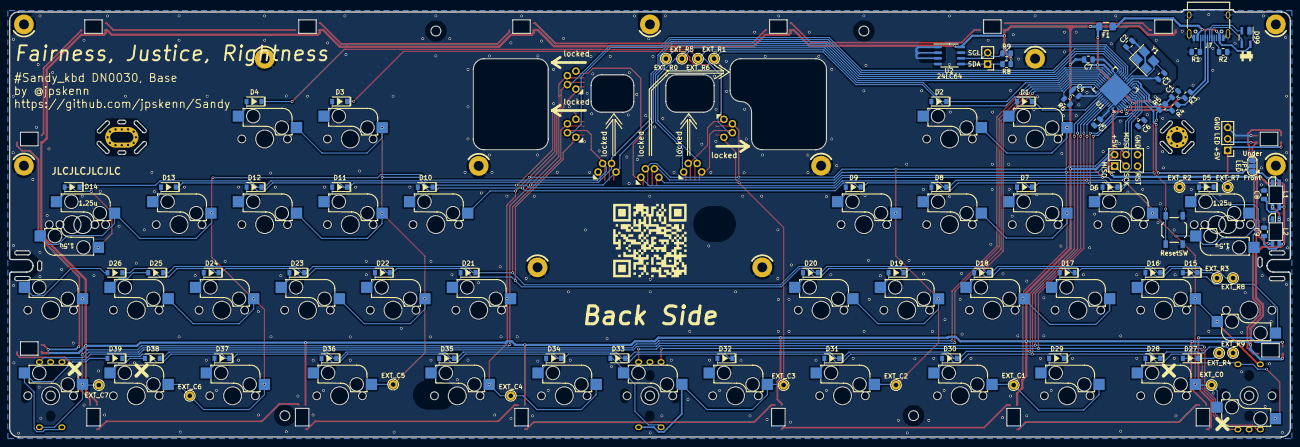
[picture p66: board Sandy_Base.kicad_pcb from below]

Board: 2 copper layers, 285.0 x 95.1 mm, 169 parts (98 on the bottom side), 96 nets.

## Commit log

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2023-01-03 Jonesの最新版をKiCad6へ変換してスタート
    [Sandy.kicad_pcb, Sandy.kicad_sch, Sandy.sch]
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2023-01-04 レイアウトテスト用としてスイッチを仮配置
    [Sandy.kicad_pcb]
2023-01-04 レイアウト落とし込み。マトリクス変更（総当たり→COL2ROW）
    [Sandy.kicad_sch]
2023-01-04 レイアウト落とし込み。ロータリーエンコーダ反映
    [Sandy.kicad_sch]
2023-01-04 テストピンなどを配置
    [Sandy.kicad_sch]
2023-01-05 基板重ね合わせのテスト
    [Sandy.kicad_pcb]
2023-01-07 子基板との接続を仮作成
    [Sandy.kicad_pcb, Sandy.kicad_sch]
2023-01-07 ミドルとトップをシート分割
    [Sandy.kicad_sch, matrix_middle.kicad_sch, matrix_top.kicad_sch]
2023-01-07 MCUさっくり配置
    [Sandy.kicad_pcb, Sandy.kicad_sch]
2023-01-08 レイアウト調整
    [Sandy.kicad_sch]
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2023-01-08 ピンヘッダのピン順を変更。フットプリント割り当て。
    [Sandy.kicad_sch, matrix_middle.kicad_sch, matrix_top.kicad_sch]
2023-01-08 子基板仮配置。コネクタ形状、位置を変更。
    [Sandy.kicad_pcb, Sandy.kicad_sch, matrix_middle.kicad_sch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]
2023-01-08 傾け時の干渉回避のため、外形を少しだけ小さくした
    [Sandy.kicad_pcb]
2023-01-09 Base基板、中央、右下ネジ穴を大穴へ。issue_#23
    [Sandy.kicad_pcb]
2023-01-12 外形、ネジ穴調整
    [Sandy.kicad_pcb, Sandy.kicad_sch, matrix_middle.kicad_sch]
2023-01-13 キースイッチを配置
    [Sandy.kicad_pcb, Sandy.kicad_sch, matrix_middle.kicad_sch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]
2023-01-13 部品仮配置
    [Sandy.kicad_pcb, Sandy.kicad_sch, matrix_middle.kicad_sch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]
2023-01-13 スイッチ方向確定。細かな調整
    [Sandy.kicad_pcb, Sandy.kicad_sch, matrix_middle.kicad_sch]
2023-01-27 5wayスイッチを追加するテスト
    [Sandy.kicad_pcb, Sandy.kicad_sch, matrix_middle.kicad_sch]
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2023-01-28 JSTコネクタとスペーサーでなんとするテスト
    [Sandy.kicad_pcb, Sandy.kicad_sch, matrix_middle.kicad_sch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]
2023-01-28 JSTコネクタとスペーサーに置き換え
    [Sandy.kicad_pcb, Sandy.kicad_sch, matrix_middle.kicad_sch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]
2023-01-29 スペーサー位置調整
    [Sandy.kicad_pcb]
2023-01-29 コネクタ位置考え中
    [Sandy.kicad_pcb, Sandy.kicad_sch, matrix_middle.kicad_sch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]
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2023-01-30 3枚の基板を1枚にまとめ中
    [Sandy.kicad_pcb, Sandy.kicad_sch, matrix_middle.kicad_sch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]
2023-01-31 基板外形変更前
    [Sandy.kicad_pcb]
2023-01-31 基板外形置き換え
    [Sandy.kicad_sch, matrix_middle.kicad_sch, matrix_top.kicad_sch]
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2023-01-31 BaseからMidへのピン数減少のため、コネクタ1個減らす
    [Sandy.kicad_sch, matrix_middle.kicad_sch, matrix_top.kicad_sch]
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2023-02-01 キープレートのフットプリント作成苦戦中
    [Sandy.kicad_sch, matrix_middle.kicad_sch]
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2023-02-12 スイッチのソケットを廃止
    [Sandy.kicad_sch, matrix_middle.kicad_sch, matrix_top.kicad_sch]
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2023-02-14 配線完了
    [Sandy.kicad_sch]
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2023-02-15 基板外形のマウスバイトを変更
    JLCPCBのガーバービューアでも正常表示されるようになった
    [Sandy-B_Cu.gbl, Sandy-B_Mask.gbs, Sandy-B_Paste.gbp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]
2023-02-15 外形関連のDRCエラーに対応
    [Sandy-B_Cu.gbl, Sandy-B_Fab.gbr, Sandy-B_Mask.gbs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]
2023-02-15 Edge Cutsの線幅を統一
    [Sandy-B_Cu.gbl, Sandy-B_Fab.gbr, Sandy-B_Mask.gbs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]
2023-02-15 微調整。SMTA発注テスト→基板大きすぎ
    JLCPCBのSMTAで、基板サイズが大きい（”Large Board"）と判定され、$50プラスとなる。
    [Sandy_BOM.csv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]
2023-02-16 基板を3枚に分けた
    [Sandy-B_Cu.gbl, Sandy-B_Fab.gbr, Sandy-B_Mask.gbs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]
2023-02-16 ネジ穴のフットプリントをわかりやすく
    これまでKiCadのライブラリに保存していたフットプリントを、ローカルへ移動。
    [Sandy_Base.kicad_pcb, Sandy_Base.kicad_sch, Sandy_Middle.kicad_pcb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]
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2023-02-17 3Dモデル指定。5wayスイッチテスト。
    [Sandy_Middle.kicad_pcb]
2023-02-17 5wayスイッチテスト。
    [Sandy_Middle.kicad_pcb]
2023-02-17 寸法線の位置を調整
    [Sandy_Middle.kicad_pcb]
2023-02-17 コネクタの1番ピンを明示
    [Sandy_Base.kicad_pcb, Sandy_Middle.kicad_pcb, Sandy_Top.kicad_pcb]
2023-02-17 MidにLEDディフューザーを追加
    [Sandy_Middle.kicad_pcb]
2023-02-18 ディフューザー固定用スペーサーネジ穴を追加
    [Sandy_Base.kicad_pcb, Sandy_Base.kicad_sch]
2023-02-18 ディフューザー固定用スペーサーネジ穴を追加（右側追加忘れ分）
    [Sandy_Base.kicad_pcb, Sandy_Base.kicad_sch]
2023-02-18 Midのディフューザータブ裏側に、スペーサーの位置指標を追加
    使うかわからんので、穴はあけてない。
    [Sandy_Middle.kicad_pcb]
2023-02-18 GNDベタ不要部分削除 #35
    [Sandy_Base.kicad_pcb, Sandy_Middle.kicad_pcb, Sandy_Top.kicad_pcb]
2023-02-18 シルク位置調整
    [Sandy_Base.kicad_pcb]
2023-02-19 最下行に親指に最適化したレイアウトを追加
    [Sandy_Base.kicad_pcb, Sandy_Base.kicad_sch]
2023-02-19 スイッチつけ忘れ対応
    [Sandy_Base.kicad_pcb, Sandy_Base.kicad_sch]
2023-02-19 配線微調整
    [Sandy_Base.kicad_pcb]
2023-02-20 3Dモデルを指定
    [Sandy_Base.kicad_pcb, Sandy_Middle.kicad_pcb, Sandy_Top.kicad_pcb]
2023-02-20 不要ライン削除
    [Sandy_Base.kicad_pcb]
2023-02-20 組み立ての目安となるシルク追加
    [Sandy_Base.kicad_pcb, Sandy_Middle.kicad_pcb, Sandy_Top.kicad_pcb]
2023-02-20 ダイオードの方向を強調するシルクに変更
    [Sandy_Base.kicad_sch, Sandy_Middle.kicad_pcb, Sandy_Middle.kicad_sch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]
2023-02-20 ソケットを使用しなくなったため、正方向にできるスイッチが増えたのを忘れていた
    [Sandy_Middle.kicad_pcb]
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2023-02-20 2uスタビの3Dモデル追加。製造ファイル作成
    [Sandy_BOM.csv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]
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2023-02-21 ヘディングレベル修正
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2023-02-21 コネクタの接続先がわかるシルクを追加
    [Sandy_Middle.kicad_pcb, Sandy_Top.kicad_pcb]
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2023-02-21 "Back Side"シルク位置調整
    [Sandy_Middle.kicad_pcb, Sandy_Top.kicad_pcb, Sandy_Top.kicad_sch]
2023-02-21 コネクタの番号と、パーツの番号を合わせる
    [Sandy_Middle.kicad_pcb, Sandy_Middle.kicad_sch]
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2023-02-21 CとRのフットプリントを変更
    Jonesの開発でKiCad5で使っていたフットプリントが見つからなくなっていた。
    [Sandy_Base.kicad_sch]
2023-02-21 GNDベタ調整
    [Sandy_Middle.kicad_pcb, Sandy_Top.kicad_pcb]
2023-02-21 製造番号シルク位置調整
    [Sandy_Top.kicad_pcb]
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2023-02-22 基板おもて側からの取り付けがわかりやすいシルクを追加
    [Sandy_Base.kicad_sch, Sandy_Middle.kicad_pcb]
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2023-02-22 LEDに3Dモデルを追加
    [Sandy_Base.kicad_sch]
2023-02-22 Mid→Topのスペーサー用ネジがTopのスイッチに干渉しないよう、ネジ穴位置を変更（2本）
    [Sandy_Middle.kicad_pcb, Sandy_Top.kicad_pcb]
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2023-03-19 課題を修正
2023-03-19 課題と解決策を加筆修正中
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2023-03-25 箇条書きのフォーマット修正
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2023-04-07 WIP, issue #61
    [Sandy_Base.kicad_pcb, Sandy_Base.kicad_sch, Sandy_Top.kicad_pcb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]
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2023-04-08 各文字の位置がズレてるように見えるのを修正
    [Sandy_Base.kicad_pcb]
2023-04-08 Topの3キーの並び順が間違えているが、互換性を保つため、修正しないコメントを追加
    [Sandy_Top.kicad_pcb]
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2023-04-09 Mid→Topのスペーサー取り付けの記述間違いを修正
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2023-04-10 インデント修正
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2023-04-10 備考が備考であるよう、パーツの説明を修正
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2023-04-13 Mid基板、BSキーだけ上下反転してるのおかしいのを修正
    Midなので、正方向にしてもソケットはケースネジ穴には干渉しない。
    [Sandy_Middle.kicad_pcb]
2023-04-13 修正：タイトル見切れ
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2023-04-13 修正：強度確保のため、Topプレートの枠を太くした
    [Sandy_Plate_Top.kicad_pcb]
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2023-04-14 修正：3D表示のソケット位置微調整 Z：-1.8mm → -1.65mm
    [Sandy_Base.kicad_pcb]
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2023-05-03 修正：実線の大円が片方消えていた
    [Sandy_Plate_Bottom.kicad_pcb]
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2023-05-13 修正：DN0020はボトムケース使用のためオプション扱い
2023-05-13 修正：使用数の間違い
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2023-05-15 修正：右インジケータLEDを廃止したのに、プレートにディフューザーが残っていた
    [Sandy_Plate_Base.kicad_pcb]
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2023-05-23 修正：改行追加
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2023-05-31 表現修正
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2023-06-06 記号修正
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2023-06-16 規格名修正
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2023-11-03 修正 ファームウェアのファイル名間違い
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
